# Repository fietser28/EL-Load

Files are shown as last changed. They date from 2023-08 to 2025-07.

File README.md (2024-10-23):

<!--
SPDX-FileCopyrightText: 2023 Jan Nieuwstad <jan.sources@nieuwstad.net>

SPDX-License-Identifier: CC-BY-SA-4.0
-->

# This is WORK IN PROGRESS.
The designs here are not finished or fully tested yet.

# Overview

The DCL8010 electronic load module features a DC Electronic Load with several modes and protections.
This project is the for the development boards for this project. There is a seperate git project for the [firmware](https://github.com/fietser28/EL-Load-FW).

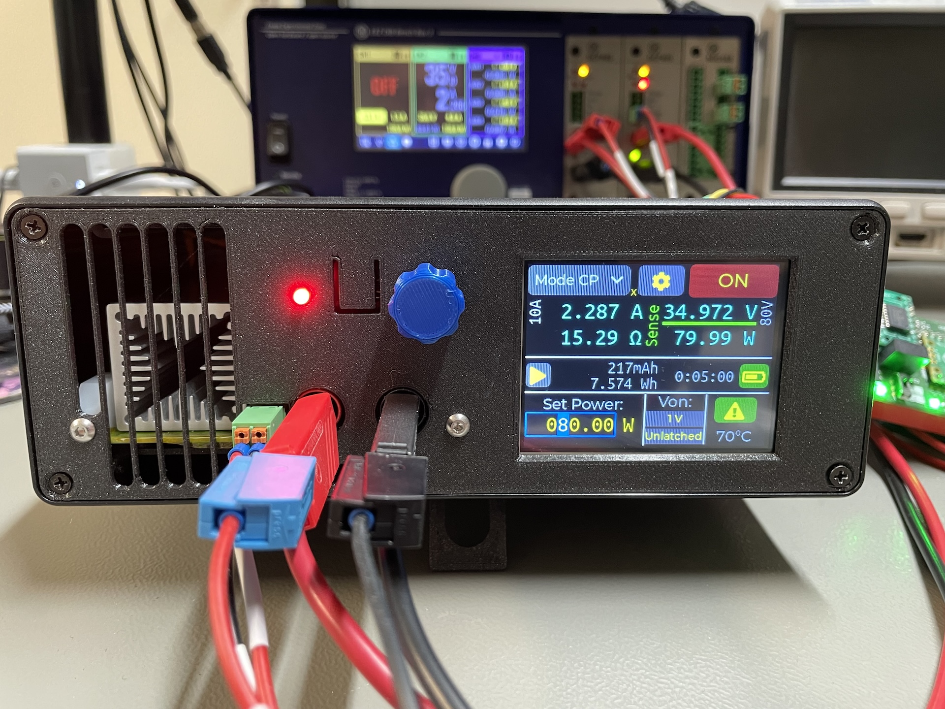
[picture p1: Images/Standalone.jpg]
Standalone unit


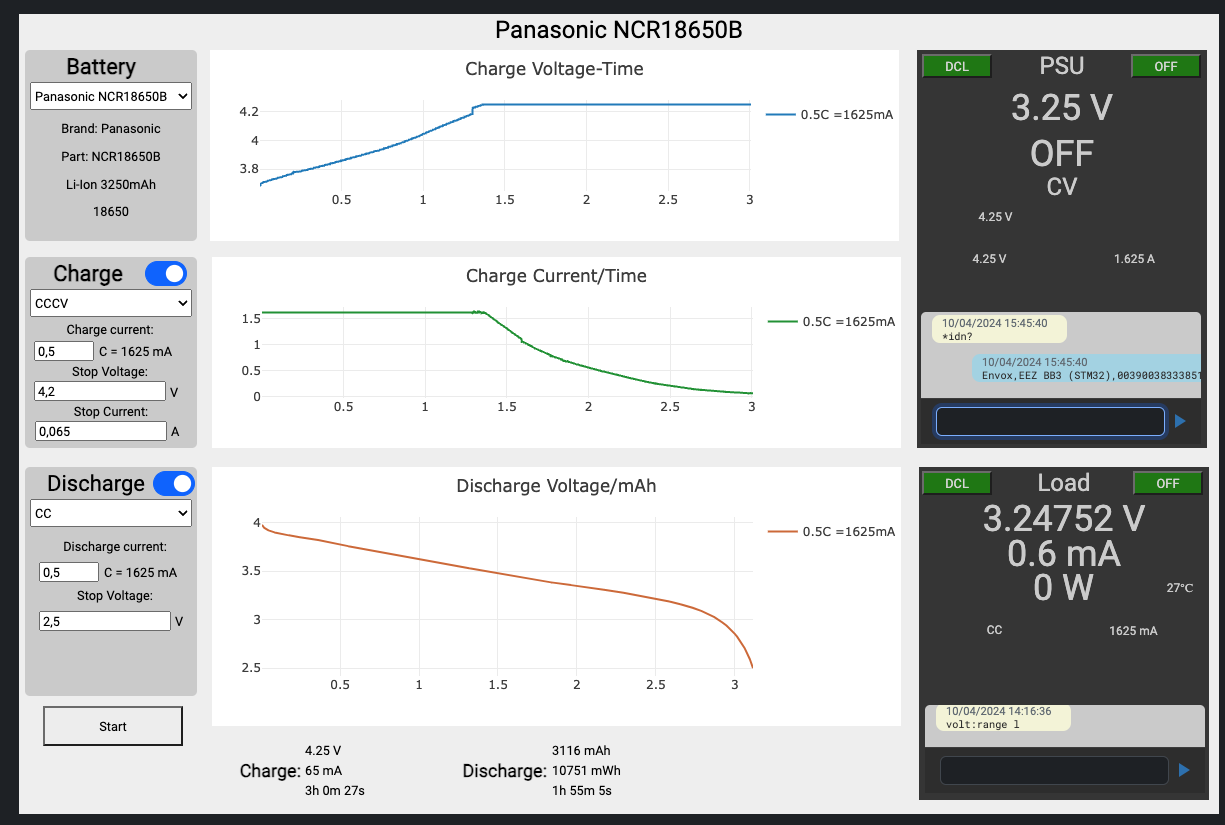
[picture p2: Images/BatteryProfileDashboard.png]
battery profile
Together with [studio] and a BB3 there will be some example dashboards in the near future. For example a  application:

## Specifications

* Modes: Constant Current (CC), Constant Voltage (CV), Constant Power (CP) and Constand Resistance (CR). CC and CV are implemented in hardware, CP and CR are software controlled and have a slower dynamic response.
* Limits:
  * Current: 1mA - 10A set and read
  * Voltage: 0.5V - 80V (set), 1mV-80V read
  * Power: 80W

* Protections:
In hardware:
  * User definable Over Voltage Protection (OVP), clamps load off within 1ms
  * User definable Over Current Protection (OCP), clamps load off within 1ms
With software support:
  * User definable Over Power Protection for a specific time in seconds (1-99)
  * User definable Over Temperature Protection for a specific time in seconds (1-99)

* Other hardware features:
  * Von: The minimum voltage needs to be present before the load is turned on. This can be set with or without latching. This is implemented in hardware and when on guarentees a gradual turn-on if a power source is 'hot plugged' or turned on. 
  * Temperature based fan control
  * Fan RPM readout
  * Heatsink temperature readout

## Design considerations

### Sizing
The Electronic Load was designed to complement a pair of BB3 DCP405 modules. Such a pair can deliver up to 80V (series configuration) or 10A (parallel configuration). The power is just maximized what is achievable with the small form factor of a BB3 module.

Minimum set voltage (an von cutoff) aim is as low as possible but at least 0.5V. A low Von cutoff is important to discharge for example AA battries (around 0.8V).

### Resolution and accurary
Aim is to have 0.1% full scale accurary after calibration. Calibration will be done in 100% in software.

This results in the follwing goals:
| Input/output | Range | Accuracy  | Resolution | Remarks 
| --- |  --- | --- | --- | ---
| Current monitor | 0-10A | 10mA | 1mA | 
| Current monitor | 0-1A | 1mA | 0.1mA | not evaluted/tested yet
| Voltage monitor | 0-80V | 80mV | 1mV | Accuracy probably: 10mV
| Voltage monitor | 0-10V | 1mV | 0.1mV | 
| Power measurements | 0-24h | 1s & 0.2% FS | 1s | Perform accurate incremental calculations and timing
| Current set | 5mA-10A | 10mA | 1mA |
| Current set | 5mA-1A  | 1mA | 0.2mA | 
| Voltage set | 0.5-80V | 80mV | 1mV |
| Voltage set | 0.5-9V  | 5mV | 1mV |
| Resistance set  | ? | ? | ? | 0.5% FS In software
| Power set | ? | 0.25W | ? | 0.5% FS in software
| Von set (80V range) | 0.25-50V | 0.2V  | 0.1V | Difficult to calibrate
| Von set (9V range) | 0.25-6V | 0.1V  | 0.1V | Difficult to calibrate
| OCP (10A range) | 0.1-10A | 100mA  | 10mA | Difficult to calibrate
| OCP set (1A range) | 0.25-6V | 10mA  | 1mA | Difficult to calibrate, not implemnted yet
| OVP (80V range) | 1-80V | 0.2V  | 0.1V | Difficult to calibrate
| OVP set (9V range) | 0.25-9V | 0.1V  | 0.1V | Difficult to calibrate, not tested yet

Using 16bit ADC's and DAC's this should be achievable with calibration done in software.

### Hardware / software partitioning
Everything requiring a response below 10ms is implemented directly in hardware. All other functionality is preferably done in software.
This results in the following decisions:
* Current and Voltage measurement and control loops are in analog circuitry
* Over voltage and over current protection measurement and shutdown are in hardware with a seperate clamp on the power MOSFET gates to shutdown as fast as possible. It is up to software to toggle pins to release the hwardware protection
* Von circuitry is implemented in hardware including the latch. The Von circuitry is important to avoid the MOSFET loops to go fully open (unregulated) when the supplied current and/or voltage is less then the set values. An unregulated situation would lead to large (= overshoot) spikes if the DUT suddenly starts providing more power (e.g. plug-in/turn on).
* To combine current, voltage and Von control a cross-over circuit is used where the smallest set current will get priority.

### Fail safely: 
An electronic load is often used to discharge batteries and due to the time this takes it is not realistic to assume the discharge is always attended by a person. If a failing component in the electronic load fails it might cause a short. A battery (or other power source without proection) being shorted is a serious fire hazard. Therefore the Electronic Load has a physical fuse and all possbile components that might faile are behind this fuse. This includes the input snubber network, transient and revserse polarity diode and of course the main MOSFETS of the electronic load. This protection is not perfect: It requires a >10A peak surge, but greatly reduces the risk.

## Limitations / Issues

Most limitations,TODO's and issues are now tracked on [github issues](https://github.com/fietser28/EL-Load/issues).

# PCBs

### EL-Load-Analog
Main PCB. Contains all the analog circuitry including MOSFETS. The DAC & ADC's are also on this board. Sizes of the PCB adhere to DIB standard (I hope).

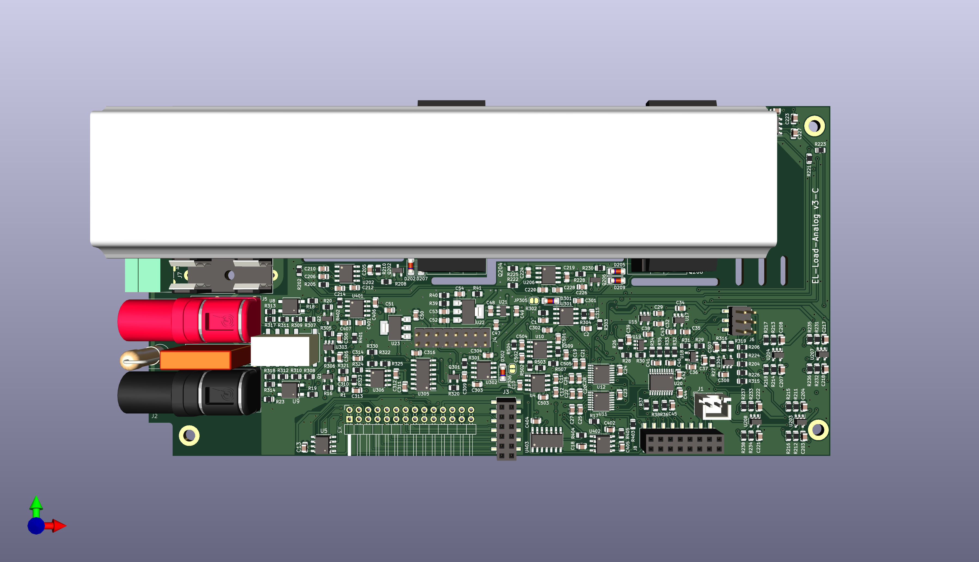
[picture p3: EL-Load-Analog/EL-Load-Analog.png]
EL-Load-Analog


### EL-Load-Power-MCU
PCB for stand alone deployment outside of BB3. This board contains an isolated power supply (input 5V) with fan controllers, MCU, GPIO and a bunch of connectors. 
It directly fits to the Analog PCB with an addidional IDC cable. There is also an IDC connector to the Front panel PCB.

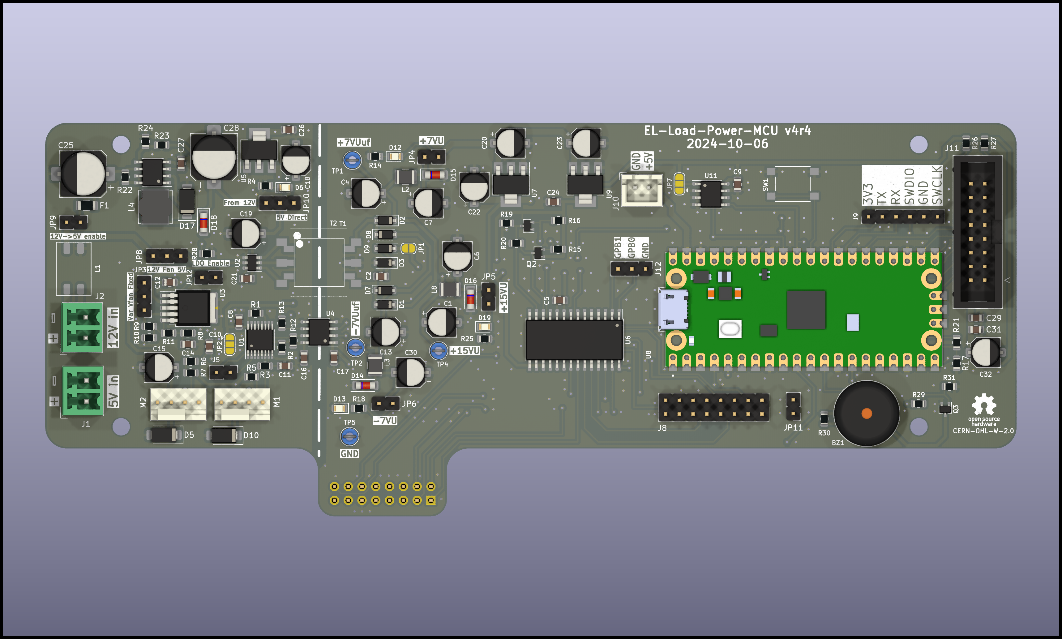
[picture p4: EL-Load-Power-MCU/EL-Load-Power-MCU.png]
EL-Load-Power-MCU


### EL-Load-Panel
Front panel PCB for standalone deployment. Connects to EL-Load-Power-MCU. Has a connector for common 2.4/2.8" TFT touchscreen PCBs, 1 encoder, 1 microswitch and one 1 LED.

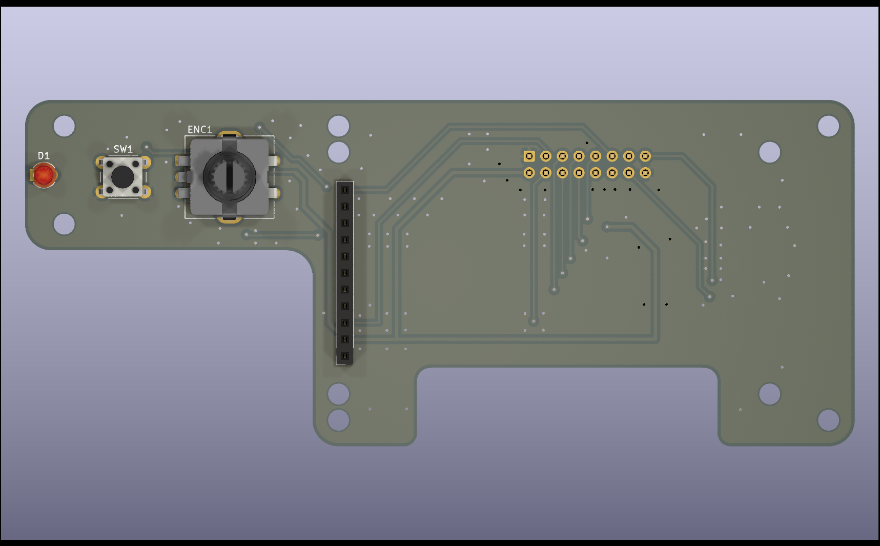
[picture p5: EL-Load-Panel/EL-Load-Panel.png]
EL-Load-Panel

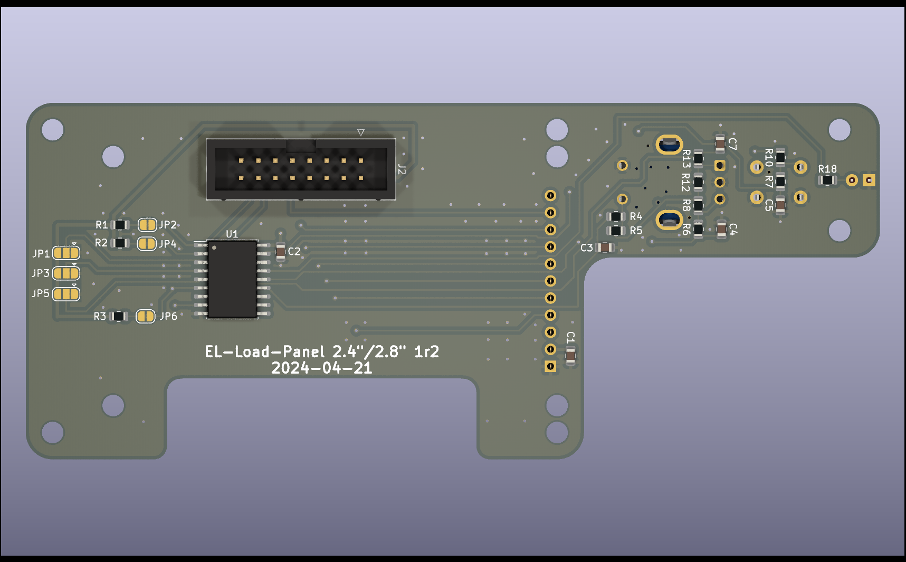
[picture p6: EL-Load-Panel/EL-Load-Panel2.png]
EL-Load-Panel backside


## Obsolete PCB's

### EL-Load-Simple-Power
Obsolete test board. Very simple 78*/79* based power supply to generate 2x+12V, 1x+5V, 1x-5V and optionally -12V. Was used for previous version of EL-Load-Analog.

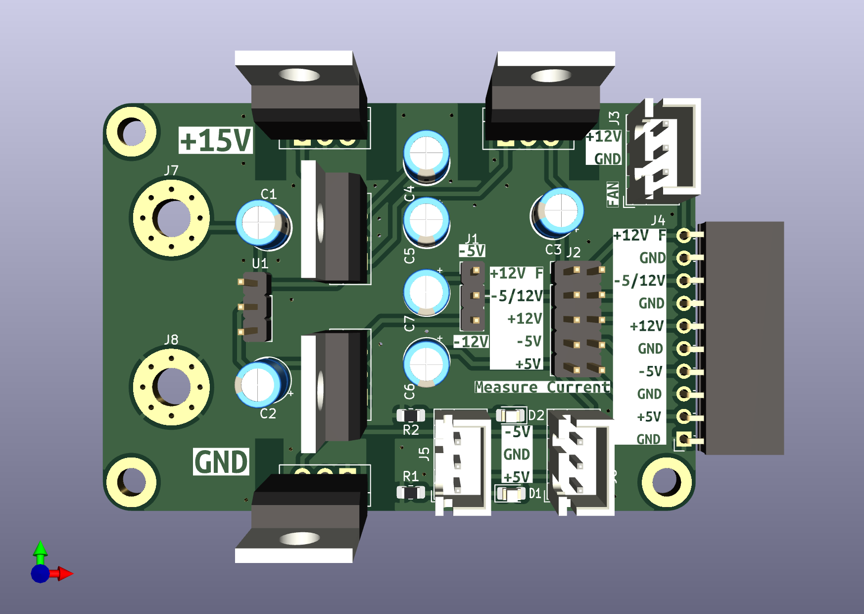
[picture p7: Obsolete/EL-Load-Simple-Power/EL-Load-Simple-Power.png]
EL-Load-Simple-Power


### EL-Load-Fan-Controller
Obsolete test board for the fan controller. For testing MAX31760 with 12V LDO regulation. Not used anymore. MAX31760 is now on Power-MCU-board.

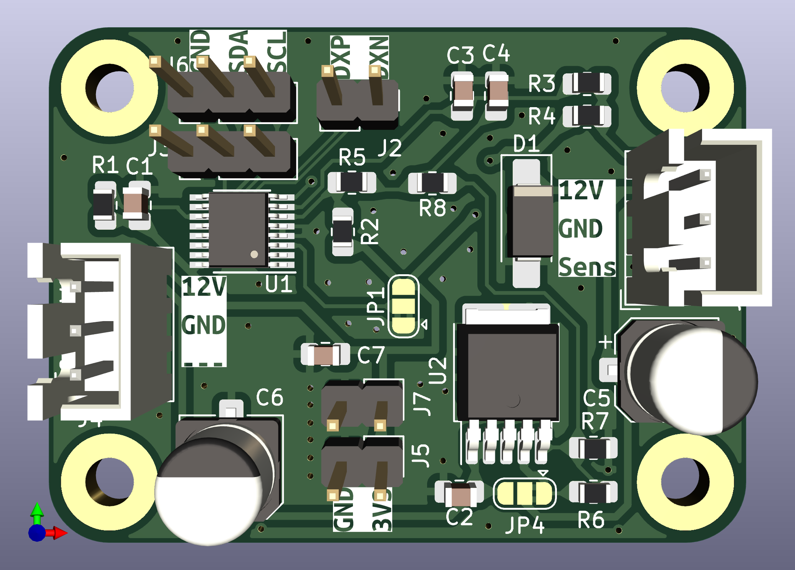
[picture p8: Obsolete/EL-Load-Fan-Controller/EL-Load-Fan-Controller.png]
EL-Load-Fan-Controller


### EL-Load-Digital
Obsolete test board for the MCU + ADC + DAC + GPIO + Touchscreen connection. DAC + ADC's are now on analog board. MCU and GPIO are now on new Power-MCU-board.

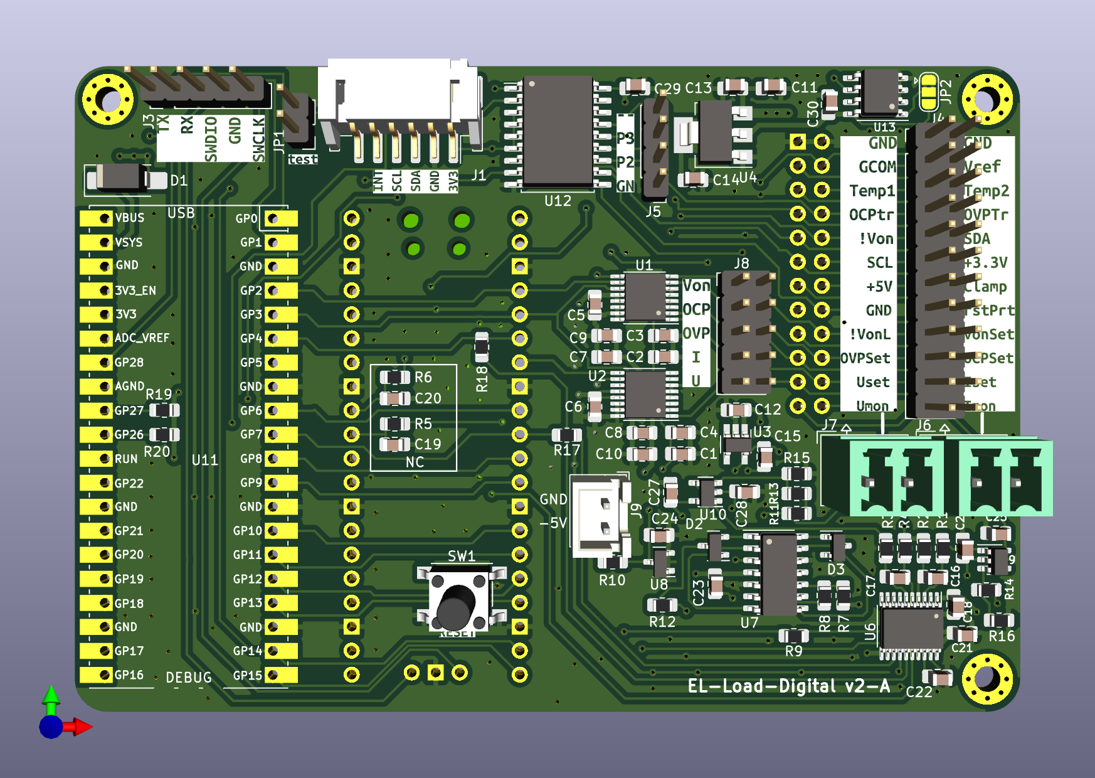
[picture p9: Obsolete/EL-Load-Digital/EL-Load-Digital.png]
EL-Load-Digital


# Ownership and License

This work is licensed under multiple licences:
 * All hardware designs are licensed under CERN-OHL-W-2.0
 * All original software source code is licensed under GPL-3.0-or-later.
 * All documentation is licensed under CC-BY-SA-4.0.
 * There are also parts imported from other sources. See the indivdual files for there specific licenses.

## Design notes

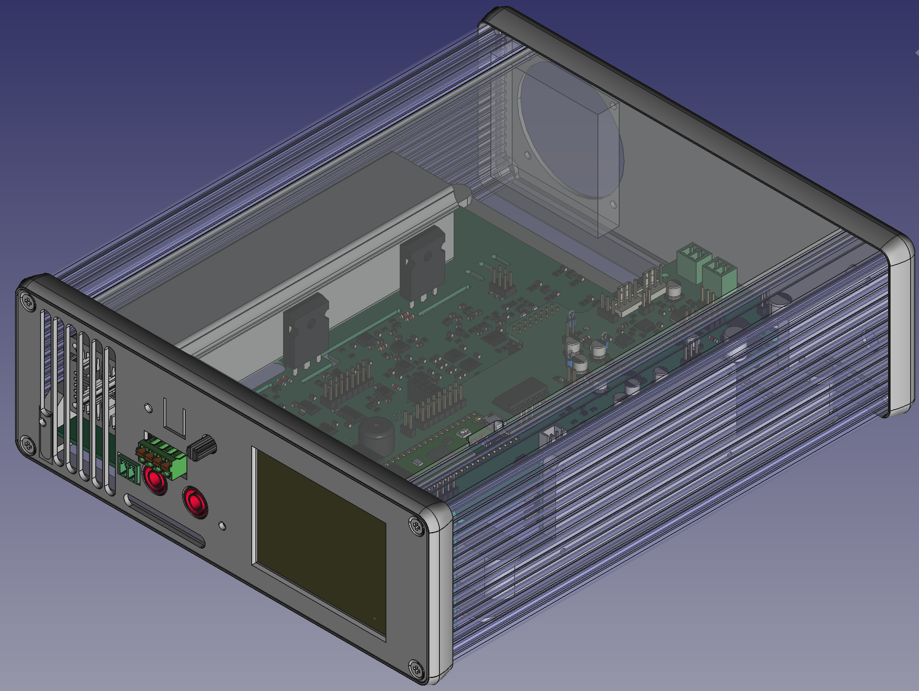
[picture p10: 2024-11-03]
Images/Case3Dv4.png

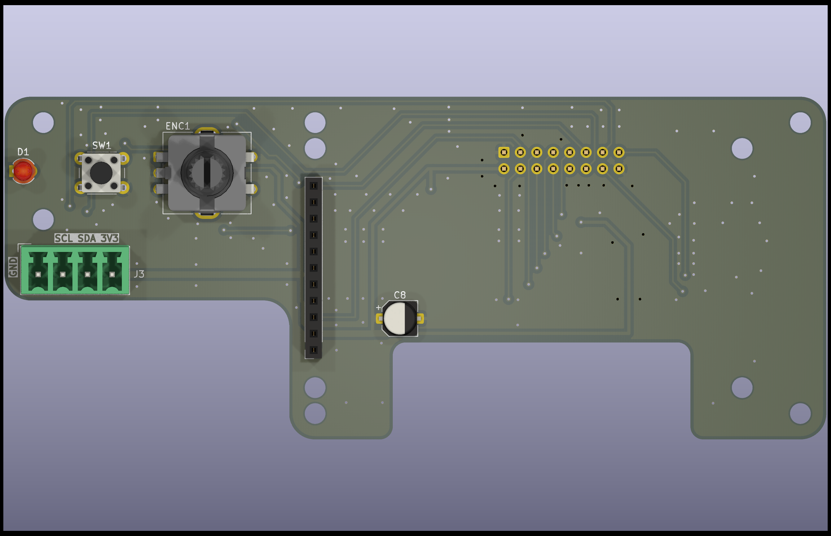
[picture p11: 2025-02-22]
EL-Load-Panel/EL-Load-Panel-v3.png

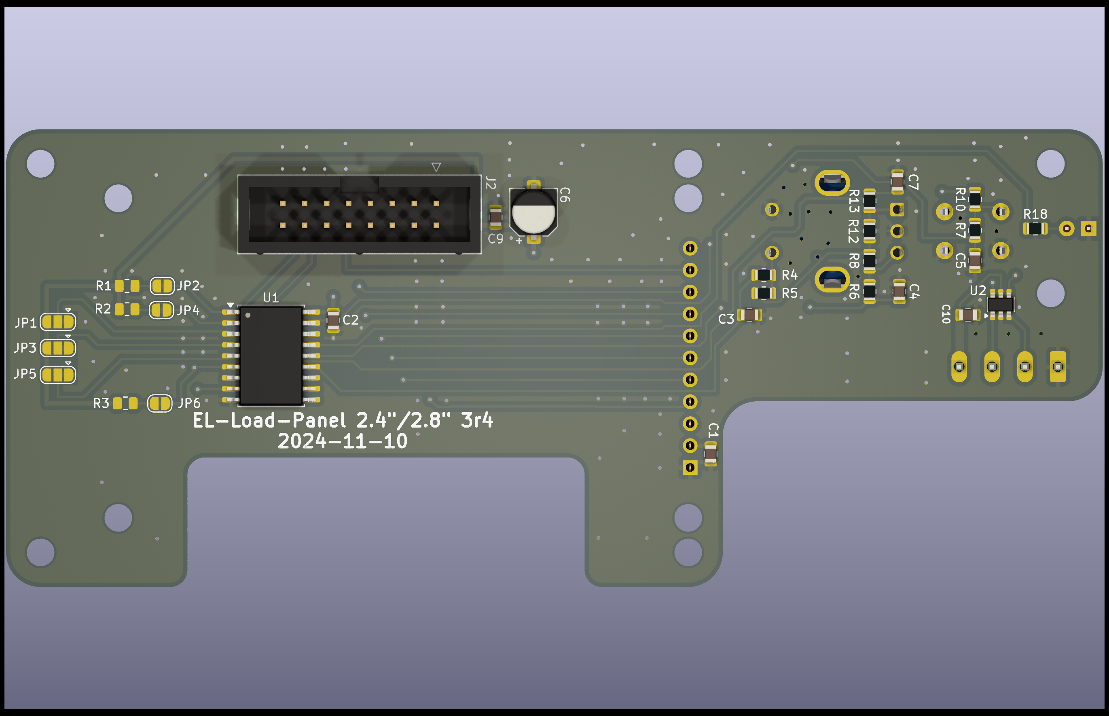
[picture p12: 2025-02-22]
EL-Load-Panel/EL-Load-Panel-v3-2.png

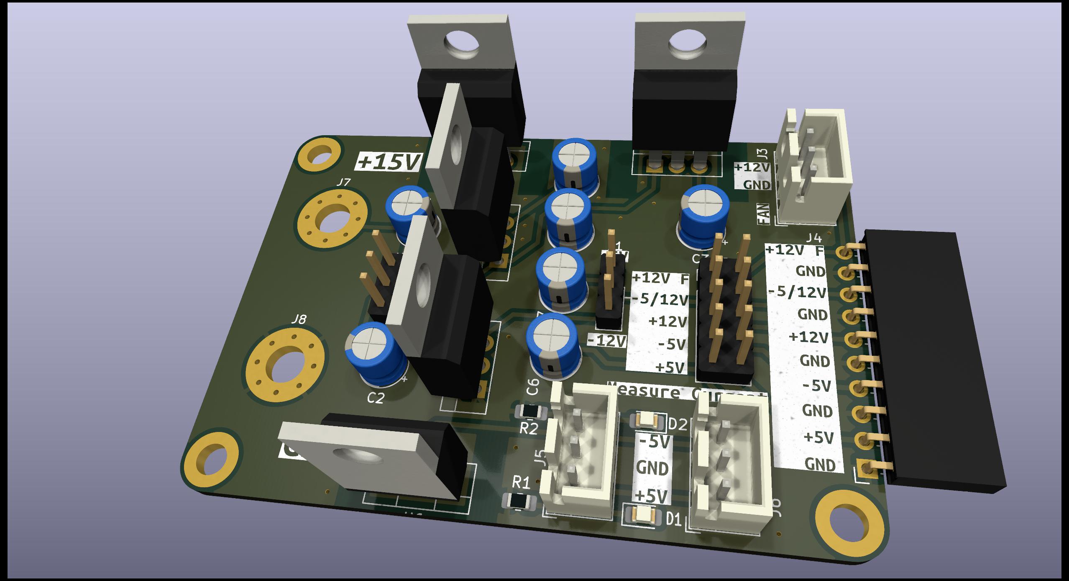
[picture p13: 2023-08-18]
EL-Load-Simple-Power/EL-Load-Simple-Power-3D.jpg

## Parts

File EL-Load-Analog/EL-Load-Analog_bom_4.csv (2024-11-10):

Description | Footprint | Part | Reference | Value | Quantity | Datasheet | Part Name | MPN | Sim.Device | Sim.Pins
Unpolarized capacitor, small symbol | C_0805_2012Metric | C_Small | C315 | 100p | 1 | ~ | C_100.0pF_0805_20%
Unpolarized capacitor, small symbol | C_0805_2012Metric | C_Small | C1 C213 C214 C227 C228 C310 | 1n | 6 | ~ | C_1.0nF_0805_20%
Unpolarized capacitor, small symbol | C_0805_2012Metric | C_Small | C5 C6 C18 C40 C41 C43 C48 C54 C405 | 10n | 9 | ~ | C_10.0nF_0805_20%
Unpolarized capacitor, small symbol | C_0805_2012Metric | C_Small | C2 | 33n | 1 | ~ | C_33.0nF_0805_20%
Unpolarized capacitor, small symbol | C_0805_2012Metric | C_Small | C4 C7 C21 C22 C23 C24 C25 C26 C36 C37 C38 C39 C201 C202 C203 C204 C205 C206 C207 C208 C215 C216 C217 C218 C219 C220 C221 C222 C301 C302 C303 C304 C305 C306 C307 C308 C309 C311 C312 C313 C314 C402 C404 C406 C407 C501 C502 C504 C505 | 100n | 49 | ~ | C_100.0nF_50V_0805_10%_X7R
Unpolarized capacitor | C_Rect_L18.0mm_W5.0mm_P15.00mm_FKS3_FKP3 | C | C3 | 100nF | 1 | ~ | C_100.0nF_15mm_THT_X2_10% | R46KI3100CKM1K
Unpolarized capacitor, small symbol | C_0805_2012Metric | C_Small | C45 | 220n | 1 | ~ | C_220.0nF_0805_20%
Unpolarized capacitor, small symbol | C_0805_2012Metric | C_Small | C401 | 680n | 1 | ~ | C_680nF_25V_X7R_10%_0805
Unpolarized capacitor, small symbol | C_0805_2012Metric | C_Small | C10 C12 C19 C20 C29 C32 C42 C44 C47 C503 | 1u | 10 | ~ | C_1.0uF_0805_20%
Unpolarized capacitor, small symbol | C_0805_2012Metric | C_Small | C34 C35 C316 | 2u2 | 3 | ~ | C_2.2uF_25V_X7R_10%_0805
Unpolarized capacitor, small symbol | C_0805_2012Metric | C_Small | C27 C28 C49 C50 C52 | 10u | 5 | ~ | C_10.0uF_25V_X5R_10%_0805
Unpolarized capacitor, small symbol | C_0805_2012Metric | C_Small | C11 C51 C53 | 22u | 3 | ~ | C_22u_16V_X5R_10%_0805
1500W unidirectional TRANSZORB® Transient Voltage Suppressor, DO-201AE | D_SMC | 1.5KExxA | D203 | 1.5KE100A (smd) | 1 | https://www.vishay.com/docs/88301/15ke.pdf | D_1.5KE100A_SMC
100V 0.15A standard switching diode, DO-35 | D_MiniMELF | 1N4148 | D2 D3 D9 D10 D11 D12 D13 D14 D15 D301 D302 | 1N4148 | 11 | https://assets.nexperia.com/documents/data-sheet/1N4148_1N4448.pdf | D_1N4148_miniMELF |  | D | 1=K 2=A
Bidirectional transient-voltage-suppression diode, filled shape | D_SOD-323 | D_TVS_Filled | D1 D4 D5 D6 | PESD3V3L1BAF | 4 | ~ | D_TVS_PESD3V_SOD323
Zener diode | D_MiniMELF | D_Zener | D7 D8 D201 D202 D204 D205 D206 D207 D208 D209 | TZMB16-GS08 | 10 | ~ | D_Z_16V_miniMELF
Fuse | Fuseholder_Cylinder-5x20mm_Schurter_0031_8201_Horizontal_Open | Fuse | F1 | Fuse | 1 | ~ | FH_5x20_THT
Heatsink | LAM3K | Heatsink | HS102 | Heatsink | 1 | ~ | MH_LAM/3/150
Generic connector, single row, 01x02, script generated | PhoenixContact_MC_1,5_2-G-3.81_1x02_P3.81mm_Horizontal | Conn_01x02_Socket | J7 | Conn_01x02_Socket | 1 | ~ | H_Plug_2P_3.81MM_PCB_HOR
Generic connector, double row, 02x08, odd/even pin numbering scheme (row 1 odd numbers, row 2 even numbers), script generated (kicad-library-utils/schlib/autogen/connector/) | PinHeader_2x08_P2.54mm_Vertical | Conn_02x08_Odd_Even | J4 | Conn_02x08_Odd_Even | 1 | ~ | H_Male_1x40_vertical_THT
Generic connector, double row, 02x08, odd/even pin numbering scheme (row 1 odd numbers, row 2 even numbers), script generated (kicad-library-utils/schlib/autogen/connector/) | PinSocket_2x08_P2.54mm_Vertical_SMD | Conn_02x08_Odd_Even | J8 | Conn_02x08_Odd_Even | 1 | ~ | H_Female_2x8_SMD
Generic connectable mounting pin connector, single row, 01x01, script generated (kicad-library-utils/schlib/autogen/connector/) | SWEB-8094-AU | Conn_01x01_MountingPin | J5 | SWEB8094AU-RT | 1 | ~ | H_Banana_Socket_24A_Red
Generic connectable mounting pin connector, single row, 01x01, script generated (kicad-library-utils/schlib/autogen/connector/) | SWEB-8094-AU | Conn_01x01_MountingPin | J2 | SWEB8094AU-SW | 1 | ~ | H_Banana_Socket_24A_Black
Generic connector, single row, 01x02, script generated (kicad-library-utils/schlib/autogen/connector/) | JST_XH_B2B-XH-A_1x02_P2.50mm_Vertical | Conn_01x02 | J1 | Temp Sensor PCB | 1 | ~ | H_JST_XH_PCB_2P_VERT
Generic connector, single row, 01x02, script generated (kicad-library-utils/schlib/autogen/connector/) | JST_XH_B2B-XH-A_1x02_P2.50mm_Vertical | Conn_01x02 | J9 | Temp Sensor heatsink | 1 | ~ | H_JST_XH_PCB_2P_VERT
General purpose signal relay, Kemet EE2 Series, DPDT (2 Form C), double coil latching, SMD, 60W/125VA, 220VDC/250VAC, 2A, 5V DC coil | Relay_DPDT_Kemet_EE2_NU_DoubleCoil | EE2-5TNU | K2 | EE2-5TNU | 1 | https://content.kemet.com/datasheets/KEM_R7002_EC2_EE2.pdf | ER_EE2-5TNU-L
0.115A Id, 60V Vds, N-Channel MOSFET, SOT-23 | SOT-23 | 2N7002 | Q1 Q2 Q201 Q202 Q205 Q206 Q301 | 2N7002 | 7 | https://www.onsemi.com/pub/Collateral/NDS7002A-D.PDF | Q_2N7002
100Vds, 12A Id, N-Channel MOSFET, SO-8 | SO-8_3.9x4.9mm_P1.27mm | AOSP66923 | Q7 | AOSP66923 | 1 | http://www.aosmd.com/pdfs/datasheet/AOSP66923.pdf | U_AOSP66923
N-MOSFET transistor, gate/drain/source | TO-247-3_Vertical | Q_NMOS_GDS | Q203 Q204 Q207 Q208 | IRFP250M | 4 | ~ | Q_IRFP250MPBF
0.2A Ic, 40V Vce, Small Signal NPN Transistor, SOT-23 | SOT-23 | MMBT3904 | Q4 | MMBT3904 | 1 | https://www.onsemi.com/pdf/datasheet/pzt3904-d.pdf | Q_MMBT3904
-0.2A Ic, -40V Vce, Small Signal PNP Transistor, TO-92 | SOT-23 | MMBT5401 | Q5 Q8 | MMBT5401 | 2 |  | Q_MMBT5401
0.6A Ic, 160V Vce, General Purpose NPN Transistor, SOT-23 | SOT-23 | MMBT5551 | Q3 Q6 | MMBT5551 | 2 |  | Q_MMBT5551
-6A Ic, -100V Vce, Power PNP Transistor, TO-220 | TO-220-3_Vertical | TIP42C | Q101 | TIP42C | 1 | https://www.centralsemi.com/get_document.php?cmp=1&mergetype=pd&mergepath=pd&pdf_id=TIP42.PDF
Resistor, small symbol | R_0805_2012Metric | R_Small | R11 R12 R24 R25 R45 R221 R222 | 0 | 7 | ~ | R_0.0Ω_0805_1%
Resistor | R_2512_6332Metric_Pad1.40x3.35mm_HandSolder | R | R219 R220 R239 R240 | 10m | 4 | ~ | R_R01_2512_1%_20ppmC
Resistor, small symbol | R_0805_2012Metric | R_Small | R36 R37 R38 | 47 | 3 | ~ | R_47.0Ω_0805_1%
Resistor, small symbol | R_0805_2012Metric | R_Small | R207 R208 R227 R228 | 100 | 4 | ~ | R_100.0Ω_0805_1%
Resistor, small symbol | R_0805_2012Metric | R_Small | R40 | 200 | 1 | ~ | R_200.0Ω_0805_1%
Resistor, small symbol | R_0805_2012Metric | R_Small | R504 | 220 | 1 | ~ | R_220.0Ω_0805_1%
Resistor, small symbol | R_0805_2012Metric | R_Small | R8 R21 | 330 | 2 | ~ | R_330.0Ω_0805_1%
Resistor, small symbol | R_0805_2012Metric | R_Small | R18 R19 | 470 | 2 | ~ | R_470.0Ω_0805_1%
Resistor, small symbol | R_0805_2012Metric | R_Small | R9 R10 | 750 | 2 | ~ | R_750.0Ω_0805_1%
Resistor, small symbol | R_0805_2012Metric | R_Small | R32 R33 R34 R35 R322 R401 R402 | 1k | 7 | ~ | R_1.0kΩ_0805_1%
Resistor, small symbol | R_0805_2012Metric | R_Small | R41 | 1k8 | 1 | ~ | R_1.8kΩ_0805_1%
Resistor, small symbol | R_0805_2012Metric | R_Small | R301 R302 R303 R304 R325 R404 R405 | 2k | 7 | ~ | R_2.0kΩ_0805_1%
Resistor, small symbol | R_0805_2012Metric | R_Small | R330 | 2k2 | 1 | ~ | R_2.2kΩ_0805_1%
Resistor, small symbol | R_0805_2012Metric | R_Small | R47 R48 | 4k7 | 2 | ~ | R_4.7kΩ_0805_1%
Resistor, small symbol | R_0805_2012Metric | R_Small | R320 | 7k5 | 1 | ~ | R_7.5kΩ_0805_1%
Resistor, small symbol | R_0805_2012Metric | R_Small | R17 R44 R46 R55 R56 R57 R201 R202 R403 R502 R507 R509 | 10k | 12 | ~ | R_10.0kΩ_0805_1%
Resistor, small symbol | R_0805_2012Metric | R_Small | R323 R503 | 15k | 2 | ~ | R_15.0kΩ_0805_1%
Resistor, small symbol | R_0805_2012Metric | R_Small | R39 R42 R58 R203 R205 R223 R225 | 22k | 7 | ~ | R_22.0kΩ_0805_1%
Resistor, small symbol | R_0805_2012Metric | R_Small | R22 R43 | 47k | 2 | ~ | R_47.0kΩ_0805_1%
Resistor, small symbol | R_0805_2012Metric | R_Small | R16 R20 R53 R54 R321 | 100k | 5 | ~ | R_100.0kΩ_0805_1%
Resistor, small symbol | R_0805_2012Metric | R_Small | R49 R51 R52 R209 R210 R229 R230 | 1M | 7 | ~ | R_1.0MΩ_0805_1%
Resistor, small symbol | R_0805_2012Metric | R_Small | R4 R5 R26 R29 R30 R31 R211 R212 R213 R214 R231 R232 R233 R234 R309 R310 R311 R312 R313 R314 | 100k 0.1% | 20 | ~ | R_100k_0805_0.1%
Resistor, small symbol | R_0805_2012Metric | R_Small | R27 R28 R305 R306 | 10k 0.1% | 4 | ~ | R_10k_0805_0.1%
Resistor, small symbol | R_0805_2012Metric | R_Small | R307 R308 | 1k 0.1% | 2 | ~ | R_1k_0805_0.1%
Resistor, small symbol | R_0805_2012Metric | R_Small | R215 R216 R217 R218 R235 R236 R237 R238 | 1k1 0.1% | 8 | ~ | R_1k1_0805_0.1%
Resistor | R_Axial_DIN0516_L15.5mm_D5.0mm_P5.08mm_Vertical | R | R2 | 1k5 (3W) | 1 | ~ | R_1.5kΩ_THT_15mm_5mm_3W_1% | FMP300FRF73-1K5
Resistor, small symbol | R_0805_2012Metric | R_Small | R204 R206 R224 R226 | 20k 0.1% | 4 | ~ | R_20k_0805_0.1%
Resistor, small symbol | R_0805_2012Metric | R_Small | R317 R318 | 39k 0.1% | 2 | ~ | R_39k_0805_0.1%
Resistor, small symbol | R_0805_2012Metric | R_Small | R3 R6 R315 | 5k 0.1% | 3 | ~ | R_5k_0805_0.1%
quad 2-input NOR gate | SO-14_3.9x8.65mm_P1.27mm | 74HCT02 | U305 U403 | 74HCT02 | 2 | http://www.ti.com/lit/gpn/sn74hct02 | U_74HCT02D
Single 2.7V to 6.0V Single Supply CMOS Op Amps, with Chip Select, SOIC-8 | SOIC-8_3.9x4.9mm_P1.27mm | MCP603-xSN | U401 | AD8038 | 1 | http://ww1.microchip.com/downloads/en/DeviceDoc/21314g.pdf | U_AD8038ARZ
24-bit dual-channel ADC with 1.2V internal reference | TSSOP-20_4.4x6.5mm_P0.65mm | ADS131M02 | U20 | ADS131M02 | 1 |  | U_ADS131M02
1A Low Dropout regulator, positive, adjustable output, SOT-223 | SOT-223-3_TabPin2 | AMS1117 | U22 | AMS1117 | 1 | http://www.advanced-monolithic.com/pdf/ds1117.pdf | U_AZ1117CH-ADJTRG1
16-bit quad-channel voltage output DAC with external reference | TSSOP-16_4.4x5mm_P0.65mm | DAC8555 | U11 U12 | DAC8555 | 2 | https://www.ti.com/lit/ds/symlink/dac8555.pdf | U_DAC8555IPW
Operational Amplifier, TO-99-8 | SOIC-8_3.9x4.9mm_P1.27mm | LM318H | U201 U202 U205 U206 | LM318D | 4 | http://www.ti.com/lit/ds/symlink/lm318-n.pdf | U_LM318D
Low-Power, Low-Offset Voltage, Dual Comparators, DIP-8/SOIC-8/TO-99-8 | SOIC-8_3.9x4.9mm_P1.27mm | LM393 | U2 U306 U402 | LM393 | 3 | http://www.ti.com/lit/ds/symlink/lm393.pdf | U_LM393
Dual, 1 MHz, 85µA, Rail-to-Rail input and output SOIC-8 | SOIC-8_3.9x4.9mm_P1.27mm | MCP6L02x-xSN_2 | U301 | LM833 | 1 | http://ww1.microchip.com/downloads/en/devicedoc/22140b.pdf | U_LM833DR
Dual, 1 MHz, 85µA, Rail-to-Rail input and output SOIC-8 | SOIC-8_3.9x4.9mm_P1.27mm | MCP6L02x-xSN_1 | U302 | LM833 | 1 | http://ww1.microchip.com/downloads/en/devicedoc/22140b.pdf | U_LM833DR
MICROPOWER 200mA Low Noise LDO negative regulator, fixed output -5V, TSOT-23-5 | TSOT-23-5 | LT1964-5 | U21 | LT1964-5 | 1 | https://www.analog.com/media/en/technical-documentation/data-sheets/1964fb.pdf | U_LT1964ES5-5
Single, 1 MHz, 85µA, Rail-to-Rail input and output, SOT-23-5 | SOT-23-5 | MCP6L01x-xOT | U18 U19 | MCP6V51 | 2 | http://ww1.microchip.com/downloads/en/devicedoc/22140b.pdf | U_MCP6V51T-E/OT
Low offset opamp, SOT-23-5 | SOT-23-5 | MCP6V51/LTC2050HV | U203 U204 U207 U208 | MCP6V51/LTC2050HV | 4 |  | U_LTC2050HVCS5
Low offset opamp, SOT-23-5 | SOT-23-5 | MCP6V51/LTC2050HV | U303 U304 | OPA189/MCP6V51/LTC2050HV | 2 |  | U_LTC2050HVCS5
2.5V 0.1% 10mA Low Noise Precision Voltage Reference, SO-8 | SOIC-8_3.9x4.9mm_P1.27mm | REF5025AD | U4 | REF5025AD | 1 | http://www.ti.com/lit/ds/symlink/ref5030.pdf | U_REF5025
Single SPDT Analog Switch, 5V/3.3V Single-Supply Operation, 12Ohm Ron, SOT-23-6 | SOT-23-6 | TS5A63157DBV | U1 | SN74LVC1G3157DBV | 1 | https://www.ti.com/lit/ds/symlink/ts5a63157.pdf | U_SN74LVC1G3157DBVR
Dual Low-Noise JFET-Input Operational Amplifiers, DIP-8/SOIC-8 | SOIC-8_3.9x4.9mm_P1.27mm | TL072 | U10 | TL072/OPA2376 | 1 | http://www.ti.com/lit/ds/symlink/tl071.pdf | U_TL072CDT
800mA Low-Dropout Linear Regulator, 5.0V fixed output, TO-220/TO-252/TO-263/SOT-223 | SOT-223-3_TabPin2 | TLV1117-50 | U23 | TLV1117-50 | 1 | http://www.ti.com/lit/ds/symlink/tlv1117.pdf | U_AZ1117CH-5.0TRG1
Ultra Low Noise, High PSRR LDO | SOT-23-5 | TPS72325 | U17 | TPS72325 | 1 |  | U_TPS72325DB
Ultra Low Noise, High PSRR LDO | SOT-23-5 | TPS7A2030 | U15 | TPS7A2030 | 1 |  | U_TPS7A2030PDBVR
Form A, Solid State Relay (Photo MOSFET) 60V, 0.2A, 10Ohm, SO-4 | SO-4_4.4x4.3mm_P2.54mm | ASSR-1218 | U8 U9 | VO1400AEFTR | 2 | https://docs.broadcom.com/docs/AV02-0173EN | U_VO1400AEFTR
Component Groups: | 82
Component Count: | 301
Fitted Components: | 301
Number of PCBs: | 1
Total components: | 301
Schematic Version: | 4
Schematic Date: | 2024-11-10
PCB Variant: | default
BoM Date: | 2024-11-10
Schematic Source: | EL-Load-Analog.kicad_sch
KiCad Version: | Eeschema 7.0.9

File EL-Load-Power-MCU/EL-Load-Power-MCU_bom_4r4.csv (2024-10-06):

Description | Footprint | Part | Reference | Value | Quantity | Datasheet | Part_Name | MPN | Consumable | Sim.Enable
Buzzer, polarized | Buzzer_12x9.5RM7.6 | Buzzer | BZ1 | Buzzer | 1 | ~ | EM_Buzzer_single_5V_THT
Unpolarized capacitor, small symbol | C_0805_2012Metric | C_Small | C27 | 200p | 1 | ~ | C_200.0pF_0805_20%
Unpolarized capacitor, small symbol | C_0805_2012Metric | C_Small | C5 C8 C9 C10 C11 C16 C17 C21 C31 | 100n | 9 | ~ | C_100.0nF_50V_0805_10%_X7R
Unpolarized capacitor, small symbol | C_0805_2012Metric | C_Small | C2 C14 C29 | 1u | 3 | ~ | C_1.0uF_0805_20%
Unpolarized capacitor, small symbol | C_0805_2012Metric | C_Small | C12 | 2.2u | 1 | ~ | C_2.2uF_25V_X7R_10%_0805
Polarized capacitor, small symbol | CP_Elec_5x5.8 | C_Polarized_Small | C1 C4 C6 C7 C13 C15 C18 C19 C20 C22 C23 C30 C32 | 10u | 13 | ~ | C_10uF_50V_Elec_5 | EEE-FK1V470P
Unpolarized capacitor, small symbol | C_0805_2012Metric | C_Small | C24 C26 | 10u | 2 | ~ | C_10.0uF_6V3_X7R_10%_0805
Polarized capacitor | CP_Elec_8x10.5 | C_Polarized | C25 C28 | 100u | 2 | ~ | C_100uF_50V_Elec_8
Zener diode, small symbol, filled shape | D_MiniMELF | D_Zener_Small_Filled | D14 D15 | 16V | 2 | ~ | D_Z_16V_miniMELF
Zener diode, small symbol, filled shape | D_MiniMELF | D_Zener_Small_Filled | D16 | 20V | 1 | ~ | D_Z_20V_miniMELF
5.6V, 500mW, 2%, Zener diode, MiniMELF | D_MiniMELF | BZV55B5V6 | D18 | BZV55B5V6 | 1 | https://assets.nexperia.com/documents/data-sheet/BZV55_SER.pdf | D_Z_5V6_miniMELF
Light emitting diode | LED_0805_2012Metric | LED | D6 D12 D13 D19 | LED | 4 | ~ | D_LED_Groen_0805
30V 0.5A Schottky Power Rectifier Diode, SOD-123 | D_SOD-123 | MBR0530 | D1 D2 D3 D7 D8 D9 | MBR0530 | 6 | http://www.mccsemi.com/up_pdf/MBR0520~MBR0580(SOD123).pdf | D_MBR0530T | MBR0530T1G
Schottky diode, small symbol | D_SMA | D_Schottky_Small | D5 D10 D17 | SS14 | 3 | ~ | D_SS14
Resettable fuse, polymeric positive temperature coefficient | Fuse_1206_3216Metric | Polyfuse | F1 | 1A | 1 | ~ | F_SMD_PTC_1A_1206
Generic connector, single row, 01x02, script generated (kicad-library-utils/schlib/autogen/connector/) | PhoenixContact_MCV_1,5_2-G-3.81_1x02_P3.81mm_Vertical | Conn_01x02 | J1 J2 | Conn_01x02 | 2 | ~ | H_Plug_2P_3.81MM_PCB_VERT
Generic connector, double row, 02x08, odd/even pin numbering scheme (row 1 odd numbers, row 2 even numbers), script generated (kicad-library-utils/schlib/autogen/connector/) | IDC-Header_2x08_P2.54mm_Vertical | Conn_02x08_Odd_Even | J11 | IDC-Header 2x08 P2.54mm | 1 | ~ | H_IDC_2.54mm_Socket_THT_2x8pins
Generic connector, single row, 01x02, script generated (kicad-library-utils/schlib/autogen/connector/) | PinHeader_1x02_P2.54mm_Vertical | Conn_01x02 | J5 J7 J8 J9 J12 JP3 JP4 JP5 JP6 JP8 JP9 JP10 JP11 JP12 | PN sensor | 14 | ~ | H_Male_1x40_vertical_THT |  | 1
Generic connector, single row, 01x02, script generated (kicad-library-utils/schlib/autogen/connector/) | JST_XH_B2B-XH-A_1x02_P2.50mm_Vertical | Conn_01x02 | J10 | Power for serial interface | 1 | ~ | H_JST_XH_PCB_2P_VERT
Inductor with ferrite core, small symbol | L_1210_3225Metric | L_Ferrite_Small | L2 L3 L8 | 10u | 3 | https://product.tdk.com/system/files/dam/doc/product/inductor/inductor/smd/catalog/inductor_commercial_decoupling_nlcv32-ef_en.pdf | L_10uH_480mohm_450mA_ | NLCV32T-100K-EF
Inductor | L_Bourns_SRN6045TA | L | L4 | 100u / 300mA | 1 | ~ | L_100uH_CD54
Coupled inductor with ferrite core | L_Bourns_SRF1260 | L_Ferrite_Coupled_1423 | L1 | SRF0905-202Y | 1 | ~ | LC_2000uH_0.6A_0905 | SRF0905-202Y
Fan, tacho output, PWM input, 4-pin connector | FanPinHeader_1x04_P2.54mm_Vertical | Fan_4pin | M1 M2 | Fan_4pin | 2 | http://www.formfactors.org/developer%5Cspecs%5Crev1_2_public.pdf | H_Molex_47053-1000_THT_PC_Fan
Open Hardware logo, small | OSHW-Logo_5.7x6mm_SilkScreen | Logo_Open_Hardware_Small | PCB1 | Logo_Open_Hardware_Small | 1 | ~ | PCB_EL-Load-Power-MCU |  |  | 0
50V Vds, 0.22A Id, N-Channel MOSFET, SOT-23 | SOT-323_SC-70 | BSS138 | Q1 Q2 Q3 | BSS138W | 3 | https://www.diodes.com/assets/Datasheets/BSS138W.pdf | Q_BSS138W
Resistor, small symbol | R_0805_2012Metric | R_Small | R22 | 0.3 | 1 | ~ | R_0.33Ω_0805_1%
Resistor, small symbol | R_0805_2012Metric | R_Small | R3 R6 | 10 | 2 | ~ | R_10.0Ω_0805_1%
Resistor, small symbol | R_0805_2012Metric | R_Small | R5 R7 R8 R29 R30 | 1k | 5 | ~ | R_1.0kΩ_0805_1%
Resistor, small symbol | R_0805_2012Metric | R_Small | R12 R13 R15 R16 R19 R20 R26 R27 | 3k | 8 | ~ | R_3.0kΩ_0805_1%
Resistor, small symbol | R_0805_2012Metric | R_Small | R10 R11 R24 | 3k3 | 3 | ~ | R_3.3kΩ_0805_1%
Resistor, small symbol | R_0805_2012Metric | R_Small | R1 R2 | 4k7 | 2 | ~ | R_4.7kΩ_0805_1%
Resistor, small symbol | R_0805_2012Metric | R_Small | R4 R14 R18 R21 R23 R28 | 10k | 6 | ~ | R_10.0kΩ_0805_1%
Resistor, small symbol | R_0805_2012Metric | R_Small | R17 R25 R31 | 20k | 3 | ~ | R_20.0kΩ_0805_1%
Resistor, small symbol | R_0805_2012Metric | R_Small | R9 | 39k | 1 | ~ | R_39.0kΩ_0805_1%
Push button switch, generic, two pins | SW_Push_1P1T_NO_6x6mm_H9.5mm | SW_Push | SW1 | Pico Reset | 1 | ~ | SW_SPST_NO_SMD_6x6x5mm
Transformer, dual primary, dual secondary | L_Wuerth_750316031 | Transformer_2P_2S | T2 | Wuerth_750316031 | 1 | ~ | T_1:1:1.75:1.75_185uH_SMD
I2C Serial EEPROM, 64Kb, DIP-8/SOIC-8/TSSOP-8/DFN-8 | SOIC-8_3.9x4.9mm_P1.27mm | 24LC64 | U11 | 24C64 | 1 | http://ww1.microchip.com/downloads/en/DeviceDoc/21189f.pdf | U_24C64
1A Low Dropout regulator, positive, 3.3V fixed output, SOT-223 | SOT-223-3_TabPin2 | AMS1117-3.3 | U5 U9 | AMS1117-3.3 | 2 | http://www.advanced-monolithic.com/pdf/ds1117.pdf | U_AMS1117-3.3
1A 20V Fixed LDO Linear Regulator, 5.0V, SOT-89/SOT-223/TO-220/TO-252/TO-263 | SOT-223-3_TabPin2 | AZ1117-5.0 | U7 | AZ1117-5.0 | 1 | https://www.diodes.com/assets/Datasheets/AZ1117.pdf | U_AZ1117CH-5.0TRG1
1.5A low dropout linear regulator, adjustable output, TO-252 | TO-252-5_TabPin6 | BD00FC0W | U3 | BD00FC0WFP-E2 | 1 |  | U_BD00FC0WFP
Precision Fan-Speed Controller with Nonvolatile Lookup Table, I2C, SOIC-16 | QSOP-16_3.9x4.9mm_P0.635mm | MAX31760 | U1 | MAX31760 | 1 |  | U_MAX31760AEE+T
1.5A, step-up/down/inverting switching regulator, 3-40V Vin, 100kHz, SO-8 | SOIC-8_3.9x4.9mm_P1.27mm | MC34063AD | U10 | MC34063AD | 1 | http://www.onsemi.com/pub_link/Collateral/MC34063A-D.PDF | U_MC34063AD
16-bit I/O expander, I2C, interrupts, w pull-ups, SOIC-28 | SOIC-28W_7.5x17.9mm_P1.27mm | MCP23017_SO | U6 | MCP23017_SO | 1 | http://ww1.microchip.com/downloads/en/DeviceDoc/20001952C.pdf | U_MCP23017-E/SO
Raspberry Pi Pico Embedded Dev Module | Raspberry Pi SC0915 | MODULE_SC0915 | SC0915 | U8 | SC0915 | 1 |  | EM_Raspberry_Pi_Pico | SC0915
Low Noise, 1A, Transformer Drivers for Isolated Power Supplies, 420 kHz, SOT-23-6 | SOT-23-6 | SN6505BDBV | U2 | SN6505BDBV | 1 | http://www.ti.com/lit/ds/symlink/sn6505b.pdf | U_SN6505BDBVT_SOT-23-6
 | SOIC-8_3.9x4.9mm_P1.27mm | Si8602AD | U4 | Si8602AB | 1 |  | U_SI8602AB-B-IS
Component Groups: | 46
Component Count: | 123
Fitted Components: | 123
Number of PCBs: | 1
Total components: | 123
Schematic Version: | 4r4
Schematic Date: | 2024-09-14
PCB Variant: | default
BoM Date: | 2024-09-14
Schematic Source: | EL-Load-Power-MCU.kicad_sch
KiCad Version: | Eeschema 7.0.9

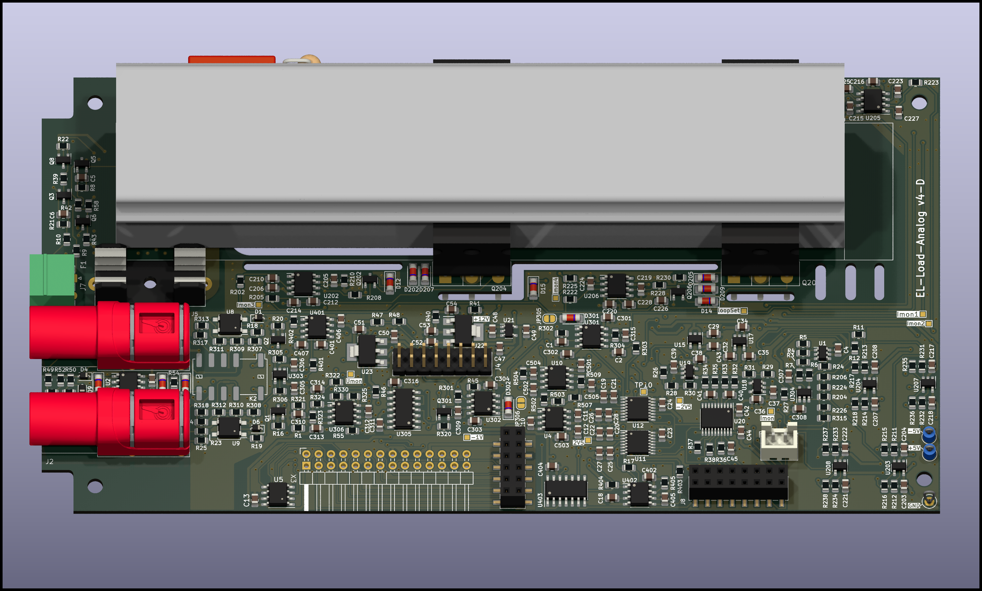
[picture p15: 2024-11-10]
EL-Load-Analog/EL-Load-Analog-PCB-v4D-parts.png

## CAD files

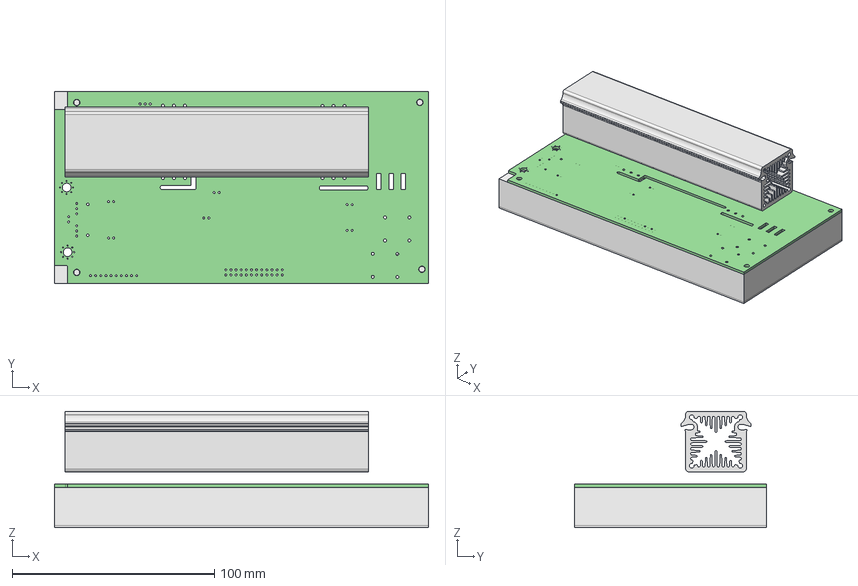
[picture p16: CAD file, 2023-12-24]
3Dmodels/PCB-stands/PCB-EL-Load-Analog.FCStd
185.0 x 95.0 x 57.6 mm
EL-Load-V2 PCB

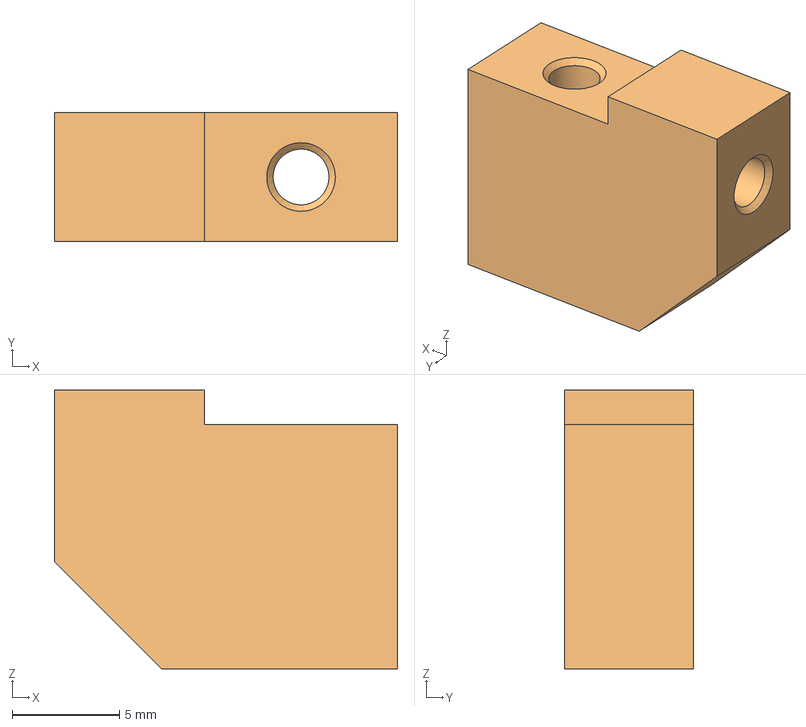
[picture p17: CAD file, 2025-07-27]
3Dmodels/PMB-1.FCStd
16.0 x 6.00 x 13.0 mm
PMB-1

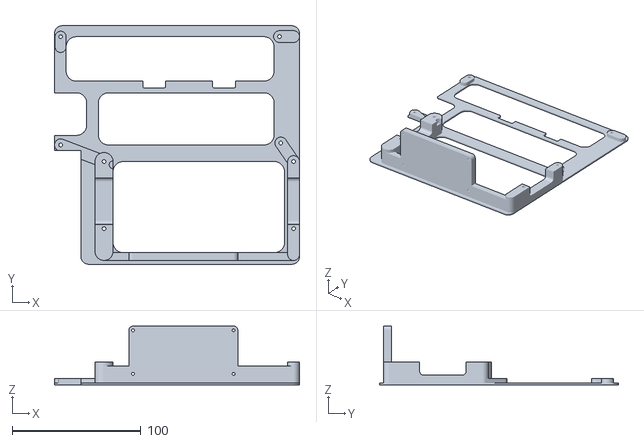
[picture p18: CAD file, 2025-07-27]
3Dmodels/Standalone/EL-Load-CaseV4-PCBFrame1.stl
190.0 x 185.0 x 45.6

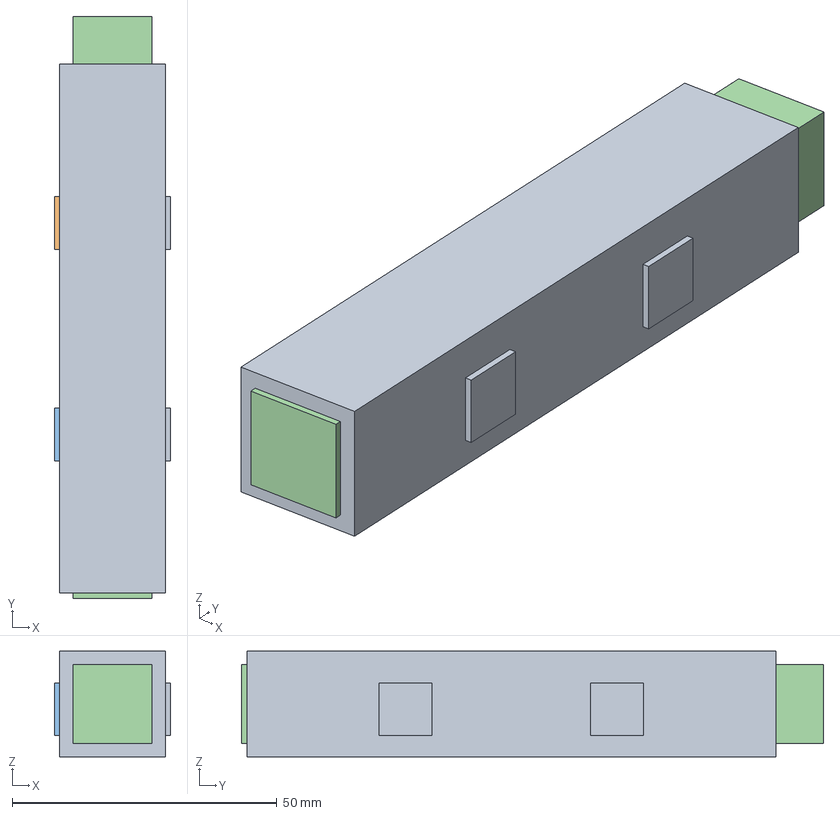
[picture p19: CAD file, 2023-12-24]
3Dmodels/ThermalSimulation/ThermalSim1.FCStd
22.0 x 110.0 x 20.0 mm

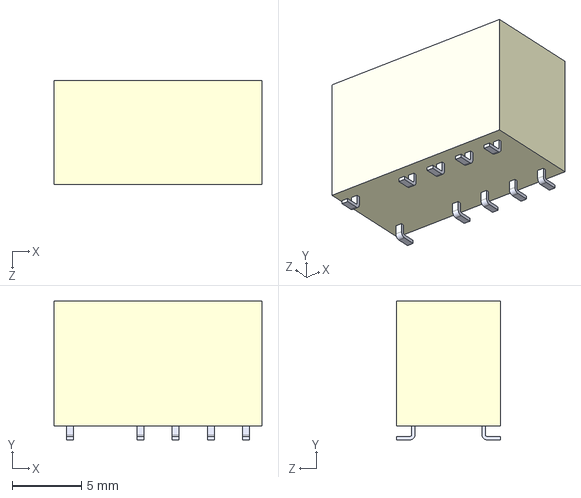
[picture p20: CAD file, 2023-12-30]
EL-Load-Analog/3Dmodels/EE2-3TNUH-L/EE2-3TNUH-L.step
15.0 x 10.0 x 7.50 mm

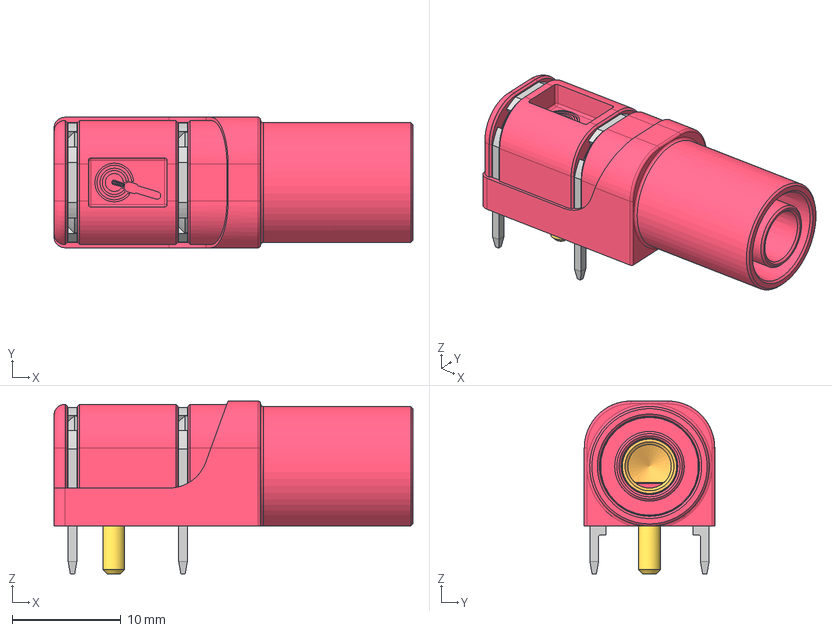
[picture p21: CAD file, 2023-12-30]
EL-Load-Analog/3Dmodels/schutzinger-sweb-8094-isolated-banana-jack-pcb-1kv-24a-1/SWEB 8094 AU RT.step
33.0 x 12.0 x 15.9 mm

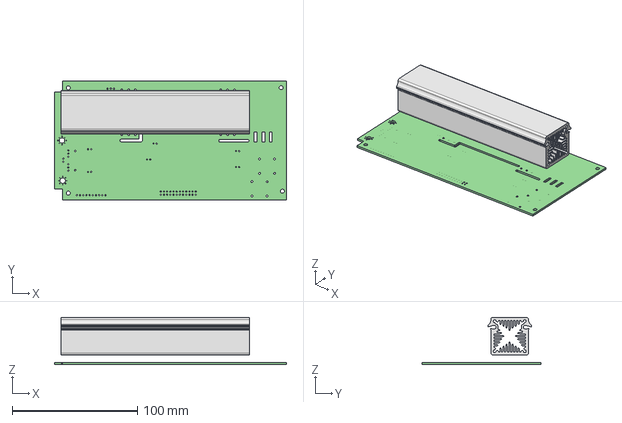
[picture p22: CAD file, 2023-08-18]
EL-Load-Analog/EL-Load-V2.step
185.0 x 95.0 x 37.6 mm
EL-Load-V2 PCB

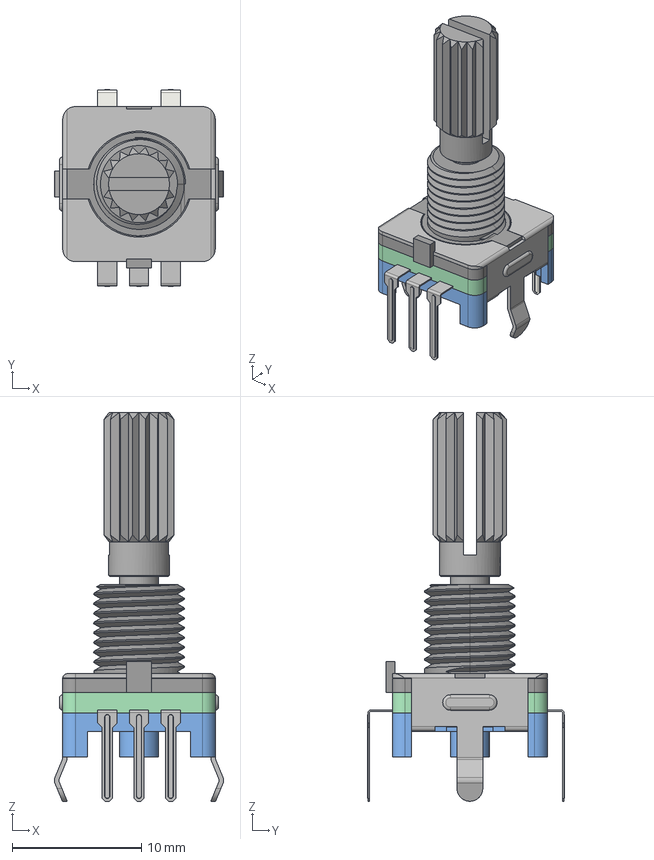
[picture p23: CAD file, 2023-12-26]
EL-Load-Panel/models/ec11-rotary-encoder-with-switch-1/EC11_Rotary_Encoder_Switched.step
13.1 x 15.3 x 30.1 mm

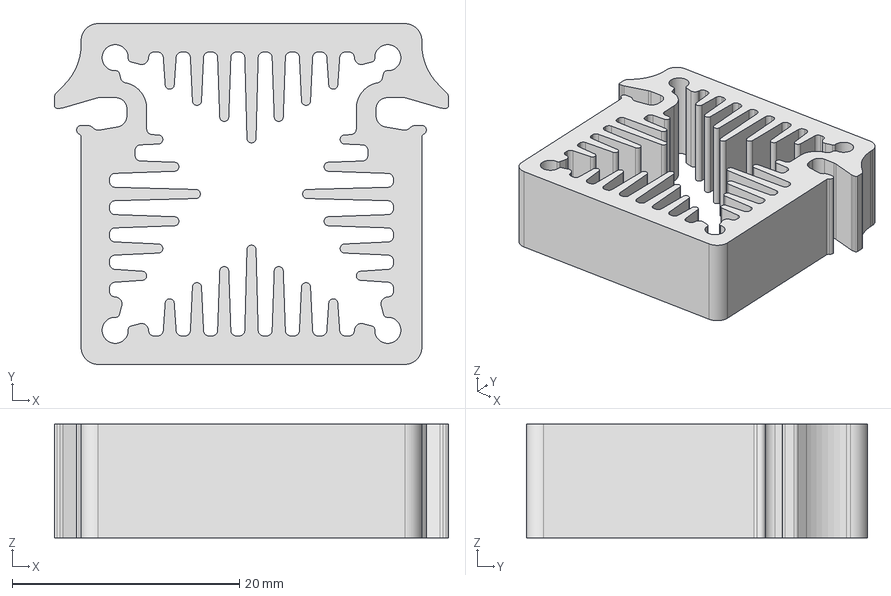
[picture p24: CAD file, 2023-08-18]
3Dmodels/lam_3_k.stp
34.7 x 30.0 x 10.0 mm

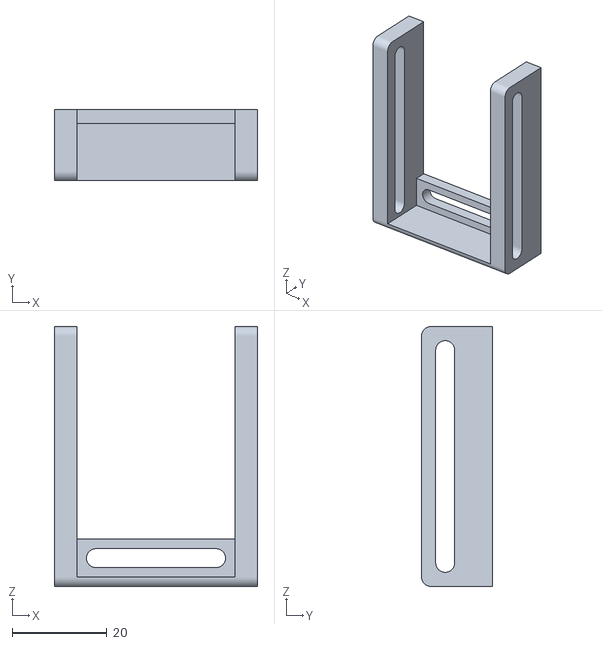
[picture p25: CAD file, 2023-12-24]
3Dmodels/PCB-stands/PCB-EL-Load-Analog-Fan30Stand2-FanSupport.stl
43.0 x 15.0 x 55.0

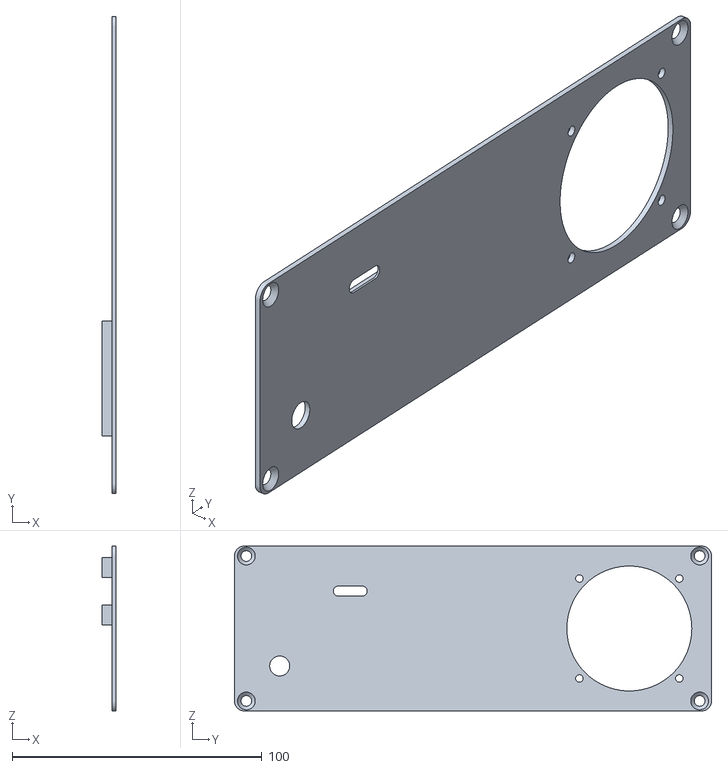
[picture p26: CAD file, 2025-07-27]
3Dmodels/Standalone/EL-Load-CaseV4-EndPanel.stl
5.63 x 191.0 x 66.0

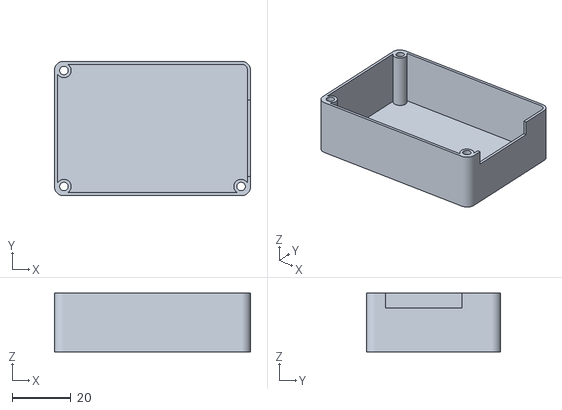
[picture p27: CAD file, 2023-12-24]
3Dmodels/PCB-stands/PCB-EL-Load-Simple-Power-BodyThickness.stl
66.6 x 45.7 x 20.0

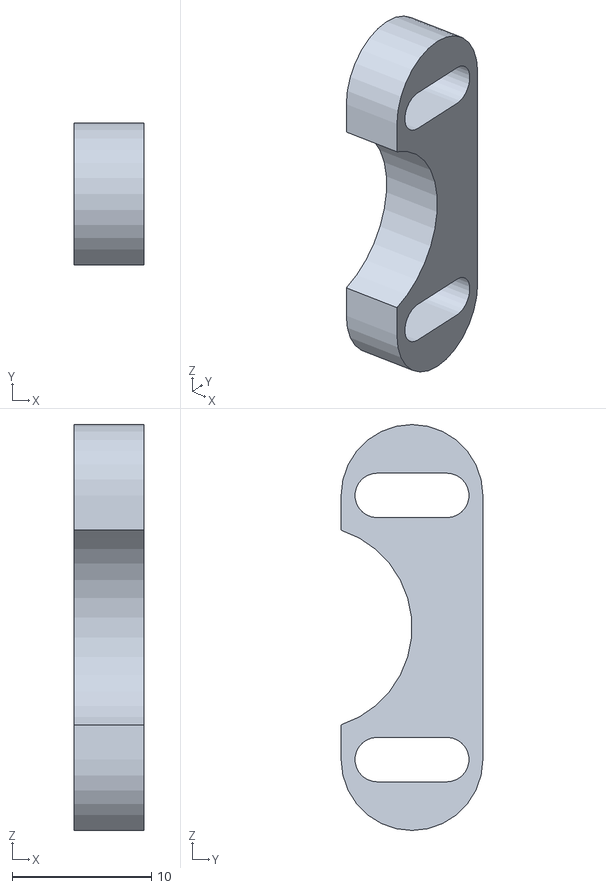
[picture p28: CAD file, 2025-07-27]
3Dmodels/Standalone/EL-Load-CaseV4-USB clip.stl
5.00 x 10.2 x 29.2

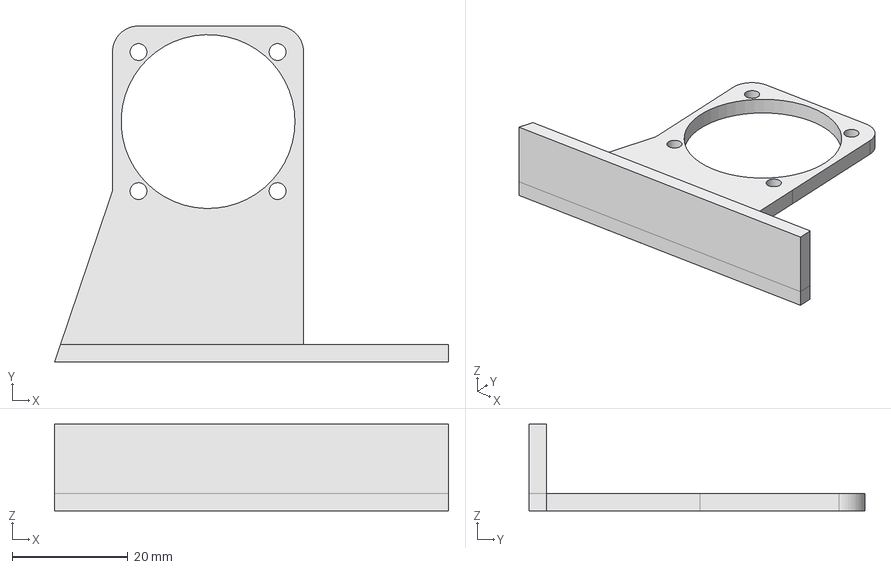
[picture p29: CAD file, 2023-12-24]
3Dmodels/PCB-stands/PCB-EL-Load-Analog-Fan30Stand1.FCStd
68.0 x 58.0 x 15.0 mm

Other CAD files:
EL-Load-Analog/3Dmodels/schutzinger-sweb-8094-isolated-banana-jack-pcb-1kv-24a-1/SWEB 8094 AU GN.step
EL-Load-Analog/3Dmodels/schutzinger-sweb-8094-isolated-banana-jack-pcb-1kv-24a-1/SWEB 8094 AU SW.step
3Dmodels/Standalone/Encoder knob.FCStd
EL-Load-Analog/3Dmodels/schutzinger-sweb-8094-isolated-banana-jack-pcb-1kv-24a-1/SWEB 8094 AU OR.step
3Dmodels/PCB-stands/PCB-ADS1115-module.FCStd
3Dmodels/PCB-stands/PCB-ADS1115-module.stl
3Dmodels/PCB-stands/PCB-EL-Load-Analog-Fan30Stand2-FanBracket.stl
3Dmodels/PCB-stands/PCB-EL-Load-Analog-Fan30Stand2.FCStd
3Dmodels/PCB-stands/PCB-EL-Load-Analog-NTCclip.FCStd
3Dmodels/PCB-stands/PCB-EL-Load-Analog-NTCclip.stl
3Dmodels/PCB-stands/PCB-EL-Load-Analog-PartPad001.stl
3Dmodels/PCB-stands/PCB-EL-Load-Digital-Body.stl
3Dmodels/PCB-stands/PCB-EL-Load-Digital.FCStd
3Dmodels/PCB-stands/PCB-EL-Load-Simple-Power.FCStd
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

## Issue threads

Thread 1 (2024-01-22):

Optimise MOSFET placement on heat sink and/or power distribution between MOSFETS.

fietser28, 2024-01-22:
We need to find a good placement of the 4 MOSFETS on the LAM 3 150 heat sink. The MOSFETs are fixed on the PCB and it would require a special setup to move them around or a lot of different PCB’s to test different configurations.

A form of thermal analysis simulation to find an optimal/good placement seems more feasible. The analysis is not very trivial because the fan cases a forced airflow thru the heatsink and the air will heat up while flowing thru the heatsink.

On my current test PCB the MOSFETS are evenly placed along the heatsink and all MOSFETS dissipate the same amount of power (this is forced by the circuit). This situation results in the MOSFETS further away from the fan being around 15-20 degrees Celsius higher. The maximum temperature of the individual MOSFETs places the limit on the maximum power rating of the device. In my test I can now dissipate 90W total in a 19 degrees room temperature. The heatsink close to the MOSFET with highest temperature is just below 90 degrees Celsius.

The MOSFETS are IRF250 in TO-247 package with thermal grease and a kapton foil isolation. They are pressed against the heatsink with DIY clamps at the place of the screw hole of the package. Because of the experimentation I don’t want to drill a lot of holes in the heatsink.

Thermal images show a gradual increase in heatsink temperature when moving away from the fan. The increase is comparable to the temperature difference between the MOSFETS. Therefore I think it is worth investigating if placing all the MOSFETS closer to the fan results in a possible lower maximum MOSFET temperature at the same overall power dissipation.

A good/optimal placement maximises the total power the mosfets can dissipate without individually overheating.
For this I think there are 2 degreees of freedom we should focus on:
1.  placement of the 2 MOSFETS with the greatest distance from the fan. The other mosfets should be placed close to the fan.
2. Create a Fixed difference (in %) between currents (which is directly proportional to the power) of the MOSFETS close and far away of the fan. If simulation shows this is beneficial it is straight forward to create this fixed difference in the circuit.

I think we should first optimise on 1 and second on 2.

jbb-nz, 2024-02-17:
I expect that a big factor in the temperature difference is due to the air inside the heatsink warming up, so I’m not sure how much difference item 1 (fiddling with the ‘downwind’ pair of MOSFETs’ position) will make.

I do think that item 2 could be a win.

fietser28, 2024-03-03:
I also have a few other factor to play with:

3. Thermal conductivity from MOSFETs to heatsink. Use grease, karnton, other type of pads.
4. Fan. I have several fans. 12V fans seem more powerful. Will also test with this.

For more structural testing I have an studio dashboard that increases the power, waits until the temperature measurement on the heat sink stabilises and records this before taking the next step.

only the physical placement is hard to change , to others are probably doable.

fietser28, 2024-03-10:
I've tested item 2: change the current ratio between MOSFETS. This doesn't change the overall heatsink temperature but it does change the individual MOSFETS temperature (which is the limiting factor).

It turns out with the current 55mm distance between the MOSFETS a 1:2 ratio results in almost leveling the temperature between the MOSFET cases. And resulting in a lower max individual MOSFET temperature around 15C at the same power level.

For 90W this means 30W for a MOSFET near the fan and 15W in the middle.
I did not expect the ratio to be so big. Definitely something to keep in there. I implemented this using simple resistor dividers at the current setting.

fietser28, 2024-03-10:
item 4: I've tested with a more powerful 12V fan: This definitely results in more cooling. Except for the cost of small powerful fans this is the way to go.

jbb-nz, 2024-03-11:
Wow, a 30 W : 15 W ratio on the current sharing is really surprising. I wonder if the ambient temperature makes a big impact here? You previously mentioned 19 degrees C; where would the temperatures end up at an ambient of 35 degrees C (for a box jammed into a corner)?

If you are implementing circuitry to manage how the current reference is send to each opamp + MOSFET, maybe you could also implement a ‘low current’ range which only sends it to the two 15 W channels? I’ve found it very useful in the past to have a ‘low’ and ‘high’ range on an electronic load.

fietser28, 2024-03-11:
I was also surprised about the ratio. I was expecting more like 20%, but it makes sense.

I expect with the ambient temperature is linear with the heatsink temperature: at a constant ambient temperature I stepped the power up and waited for the temp to stabilize: the temperature rose linear with the power.

regarding the low ranges: What is your use case / preferred range?
I have a low range implemented for testing now: it only changes the measurement from 10A full scale to 1A full scale. This increases the accuracy, hopefully from 10mV accuracy and 1mA resolution to 1mA accuracy and. 0.1 mA resolution . Setting current stays the same: 1mA.
Voltage goes from 80V full scale to around 10V full scale.

jbb-nz, 2024-03-12:
Oops, I forgot about existing low range setting. 0.1 mA readout resolution is good. 1 mA setting resolution is probably just fine.

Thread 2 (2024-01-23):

Fix errors on EL-Load-Power-MCU 2r2

fietser28, 2024-01-23:
There are some mistakes on 2r2:

- [x] diodes on negative rails are reversed (D7 & D8)
- [x]  Enable pin (pin 5)  on sn6505 is low instead of high
- [x] remove C3 and D4. Short jumper JP1. Configuration with 2 diodes is enough.
- [x] remove zener D16 or change to higher value (18-20V)
- [ ] ~~Remove T1 or T2 footprint in final version depending on choice~~ no in #24
- [x] Fix T1 component label (footprint is ok)
- [x] Add cutout for MCP23008 on panel PCB.
- [x] J7 pin 14 = GND, should be 3.3VD (power supply for ADC and DAC's on analog board)
- [x] Fix Q1 an Q2 footprints. SOT23-3 instead of SOT23?

Improvements:

- [x]  in test PCBs: Add led to +15VU. This wil work as a small dummy load when analog board is not connected.

Closed 2024-03-21.

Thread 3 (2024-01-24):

Fix Errors on EL-Load-Panel PCB 1r1

fietser28, 2024-01-24:
Errors found on r1r1:

- [x]  TFT Display connector is rotated 180 degrees.
- [x] TFT Display connector is about 1mm misaligned with TFT display connector.
- [x]  Move MCP23008 up to keep it clear from MCU-Power PCB in case (or make cutout on MCU-Power PCB see #2 )
- [x]  Correct encoder footprint

Closed 2024-01-26.

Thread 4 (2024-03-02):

Fix errors on EL-Load-Analog v3-C Schema & PCB

fietser28, 2024-03-02:
- [x]  C401 = 1u  (was 680n)
- [x]  C52 10uF cap should have higher voltage rating (25/50V)
- [x] C316 = 1uF ipv 2.2uF. Change in design?
- [x] R330 label is at wrong/unclear place (to close to R322)
- [x] LT1964 PCB is correct for fixed 5V regulator. (adjustable requires additional 1200+390 ohm resistors)
- [x] Fix +12V regulator setup (values below result in 11,5 V which is fine):
- [x]  remove R39
- [x] R40 = 200
- [x] R41 = 1k8
- [x]  GCOM op differential amplifiers shunt resistors instead of GND: R213, R211, R233, R231: GND change to GCOM.
- [x]  R6 should be connected to GCOM instead of GND. This relates to previous item.
- [x] R18 en R19 = 470 ohm instead of 100k.
- [x]  U10B -1V reference circuit doesn't work. Fix.
- [x]  ~~Connect -5V to R320 (instead of -1V) and replace R320 with 47k. After this: tune the Von response time.~~
- [x]  ~~R201,~~ R221, ~~R202,~~ R222 can be removed.
- [x] ~~R203, R205, R223, R225 = 10k. This improves the set current stability when temperature rises.~~

Closed 2025-01-01.

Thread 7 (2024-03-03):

Make Power section dual voltage input

fietser28, 2024-03-03:
Change power section to have a 5V input for the isolated power rails and separate 12V input for the fan connections and the fan controller (non isolated).

~~For ease of testing also add an optional 12V to 5V buck converter to allow for a single 12V power supply for testing.~~

Closed 2024-03-20.

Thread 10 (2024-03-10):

12V to 5V convertor

fietser28, 2024-03-10:
Separated from #7:
For ease of testing also add an optional 12V to 5V buck converter to allow for a single 12V power supply for testing.

Add this to the isolated power section of the Power-MCU board. Should be optional using jumpers.

Closed 2024-03-20.

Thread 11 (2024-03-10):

Test with powerful fan

fietser28, 2024-03-10:
Test with powerfull fan: [MR3010E with 12V with PWM](1570-MR3010E12B1+6-RSR-ND)  ([datasheet](https://www.mechatronics.com/pdf/MR3010.pdf)).

Disadvantage: expensive and only available from Digikey. It really has to make a difference.

fietser28, 2024-05-03:
No noticable difference.

Closed 2024-05-03.

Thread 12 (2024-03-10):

Add testpoints

fietser28, 2024-03-10:
Add testpoints to PCB for easier testing.

- [x]  Several GND pins close to other testpins (to avoid loops)
- [x] +12V
- [x] +5V
- [x] -5V
- [x] V Ref
- [x] -2.5V
- [x] +3.0V
- [x] LoopISet
- [x]  Imon
- [x] Umon
- [x]  Imon for each loop

Closed 2024-03-24.

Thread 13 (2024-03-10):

Von circuitry might oscillate with specific loads

fietser28, 2024-03-10:
Von circuitry causes some oscillation when the voltage slowly decreases to the set level. This is noticeable in a typical battery discharge test, but this scenario can be circumvented easily by the user with the current firmware.

As this ia a very valid and common scenario we should implement something for it in hardware or software to notify user or avoid it.

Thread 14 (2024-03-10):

Add nice reverse polarity protection and detection.

fietser28, 2024-03-10:
Current reverse polarity implementation is a very crude diode+fuse: Implement a proper reverse polarity circuit preferabbly with a detection to software (nice to have).

fietser28, 2024-04-21:
See https://github.com/fietser28/EL-Load/tree/main/Obsolete/EL-Load-Reverse-Polarity for a prototype

Closed 2024-11-13.

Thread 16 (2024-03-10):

Von scaling

fietser28, 2024-03-10:
Von doesn't have to be possible for the full voltage ranges, 50% of the range is enough. This might increase the accuracy of Von.

This can be implemented using voltage dividers. This is already in place on v3 of PCB.

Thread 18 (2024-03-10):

Remove ADC clamp circuits

fietser28, 2024-03-10:
Probably not needed, replace with simple TVS diodes. Design in conjunction with #6

Closed 2024-03-24.

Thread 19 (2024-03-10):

Evaluate low current range

fietser28, 2024-03-10:
Evaluate the v3 hardware implementation. Is it useful, e.g. does it give extra measurement accuracy or not.

fietser28, 2024-03-15:
Working. Measurements are fine. Setting is also possible with increments below 1mA.
Practical lower limit for regulation is around 5mA.

Closed 2024-03-15.

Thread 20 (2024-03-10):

Evaluate low voltage range

fietser28, 2024-03-10:
Evaluate the v3 hardware implementation. Is it useful, e.g. does it give extra measurement accuracy or not.

fietser28, 2024-03-13:
Done. Workable range is 0-10V. Updated in README.md

Calibration is also working in firmware.

Closed 2024-03-13.

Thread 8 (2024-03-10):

CC loop tuning

fietser28, 2024-03-10:
During changes to reduce temperature dependencies some instability was introduced to the CC loop for low voltages (2-7V) and and multiple amps (2-4A). The measured oscillation is around 65kHz (using 10kohm feedback resistors for R225,R223, R205, R203)

Spice simulation agrees with this.

New values:

- [ ] ~~gate resistors R207, R208, R227, R228: 10ohm (was 100)~~ did not help
- [x] feedback restores R203, R205, R223, R225: 22k (was 100k in V3C)
- [x] compensation caps C213, C214, C227, C228: 1n (was 470p)

fietser28, 2024-03-13:
Tested with above values on PCB. Looks ok for now. Still need to correct this in design and BOM.

Closed 2024-03-21.

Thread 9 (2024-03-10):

Change clamping circuit

fietser28, 2024-03-10:
#8 will put to much stress on the mosfet driving opamps with the current clamp circuit.

Change the clamp method by clamping LoopIset to zero instead of the MOSFET gates.
Use a 2N7002 + resistor (1k?) + diode (1N4148) to clamp LoopIset to zero or slightly below zero.

Remove the lamp MOSFETS and the long lines to it.

fietser28, 2024-03-24:
#8 numbers changed. This is not needed for this reason anymore.
Maybe still a good idea to add this. Needs further HW testing.

fietser28, 2024-11-10:
Designed. Waiting for test.

Closed 2024-11-13.

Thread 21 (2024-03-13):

range switching doesn't always work

fietser28, 2024-03-13:
When a range switch happens this not always results in the right calibration values being used for displayed value.
Noticed on voltages.
This also happens when leaving calibration mode (during setDefaults).

going back and forth solves the problem.

fietser28, 2024-03-13:
Also is wrong during startup... switching back and forth fixes it. Looks like it is only wrong on voltage range.

fietser28, 2024-03-15:
Fixed with fietser28/EL-Load-FW@587e0462c25fcbd57fed5ebb97679b09d0ad073b

Closed 2024-03-15.

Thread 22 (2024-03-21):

MCP23017 GPA7 is output only according to datasheet

fietser28, 2024-03-21:
The revision D (2022) of the MCP23017 states the GPA7 (and GPB7) pins are output only. Currently we use GPA7 for Von input and this is working fine but can’t be relied upon.

Solution: Change the hw pin for von to a different pin of bank A. Swap it with an output pin.

fietser28, 2024-03-21:
Fixed in v3 MCU PCB

Closed 2024-03-21.

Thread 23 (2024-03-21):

Swap Von and VonLatch in firmware for v3 MCU PCB

fietser28, 2024-03-21:
See #22

fietser28, 2024-11-03:
Done

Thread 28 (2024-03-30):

Analog V4 testing

fietser28, 2024-03-30:
The Analog V4 schematic and PCB have some changes that need testing after fabrication:

- [x] Test reverse polarity protection circuit (with remote voltage sensing voltage connection)  (#14)
- [x] Test -1V reference
- [x] Test dynamic behaviour of Von
- [x] Test new clamping circuit (#9)

fietser28, 2025-01-03:
Reverse polarity is sensitive to adding/removing positive voltages (unplugging, turning DUT on/off). Happens both with load on and off. The Von switching the reverse polarity mosfett off might also cause this.
Possible solutions:

- add hysteresis to reverse polarity comparator.
- more relaxed lower voltage
- compare negative imput to GND or, -0.5V or -1V instead of positive input.
- is to add a small delay (50ms?) before actually triggering beep/reverse polarity in software.

Closed 2025-01-06.

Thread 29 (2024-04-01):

Standalone PCB with DIB connector.

fietser28, 2024-04-01:
Create a PCB with:
- RP2040 CPU / use raspberry pi pico module
- Connector to panel PCB with display, touch, and encoders. Using existing connector setup.
- 12V -> 5V module to feed BB3 module with both 12V and 5V.
- Case fan controller and drivers.

This PCB can be derived from the MCU-Power PCB.

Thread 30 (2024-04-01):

BB3 compatible MCU board

fietser28, 2024-04-01:
Rework the Power-MCU PCB to be a piggy board:

- Flip the board to fit on top of the BB3 board and connectors.
- Keep/Include Pico
- Keep MCP23017 section with level shifting
- Keep/include isolated power section (simplify?!)
- Keep heatsink fan controller
- Keep panel connector for display/touch/keys
- Keep Debug interface SWD+UART

- Add: DIB opto isolators
- Add: allow to switch between panel and DIB isolators (jumpers?)

- Remove case fan controller
- Remove 12V - 5V

Optionally/TBD: Add leds and extend piggy board to panel. Banana connectors and or sense relay might be in the way.

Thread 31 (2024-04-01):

Add programmable slew rate circuitry

fietser28, 2024-04-01:
Long term which. Main problem is to find space for the additional hardware on the main PCB.

3 available DAC channels can be used to set the levels/slew rates

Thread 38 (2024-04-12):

Implement self test and *TST?

fietser28, 2024-04-12:
Implement self test function and add it to startup and *TST? command.

Due to hardware limitations a full functional test is not possible without additional circuitry but a few sanity check can be implemented:

- [ ] ADC should trigger measure task (not really needed because watchdog might catch this?)
- [ ] measure voltage, perform range switch. Voltage should be same within a certain spec.
- [ ] same for current.
- [ ] set OCP DAC to 0 and MAX and see if it triggers/clears
- [ ] same for OVP DAC
- [ ] Manual Fan test

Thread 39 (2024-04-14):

Demo dashboard: MPPT for small solar panels

fietser28, 2024-04-14:
Create a studio dashboard that creates MPPT specific graphs and calculates results.

The graphs will be:
- Current-Voltage
- Power-Voltage

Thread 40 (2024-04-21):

Check/test rise fall time compatibility of inputs to logic

fietser28, 2024-04-21:
Check if the rise/fall times of the ovp,ocp and von comparators and other digital inputs are in the range of the used logic family/ic’s. If not they need to be replaced with Schmitt-trigger equivalents.

fietser28, 2025-01-08:
74HCT series are used. TI specifies a min. rise/fall time of 500ns for this series.

With LM393's from unknown origin I get 500us rise and 6ms(!) fall times with a 2k pull-up at the OVP/OCP comparators.

This is clearly not within spec but **everything is working fine**. Probably because the switching is very infrequent so thermal issues at the input of the TTL chips are not a problem.

Clamping in response to large OVP or OCP steps happens in around 250us.

Possbile improvements for later:
- use genuine LM393's
- use fast comparators with TTL output. Better but more expensive and possibly not jelly bean components

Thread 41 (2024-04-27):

Implement MEASure commands

fietser28, 2024-04-27:
Implement real MEAS commands that start a new measurement.

fietser28, 2024-12-06:
Implemented: MEASure:CURRent?, MEASure:VOLTage?, MEASure:POWer?

Closed 2024-12-06.

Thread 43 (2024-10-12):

Add basic statistic support

fietser28, 2024-10-12:
- [x] Add min,max and average calculations for current, voltage and power.
- [x] Implement run and clear states.
- [x] Add SCPI commands for clear and run/pause
- [x] Add SCPI commands for querying different stats. As options to existing fetch commands?
- [x] Add UI to control and display stats in separate screen
- [x] Add stats display option instead of capacity panel/make suitable with swipe?

fietser28, 2024-11-02:
Implemented.

Closed 2024-11-02.

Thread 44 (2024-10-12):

Standalone enclosure design

fietser28, 2024-10-12:
Finish a standalone enclosure design based on:
- Hammond aluminium extrusion,
- 3D printed frames
- PCB based front and back panels OR 3D printed panels integrated with frames.

fietser28, 2024-11-03:
Done.

Closed 2024-11-03.

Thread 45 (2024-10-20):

ADD Beeper config screen and settings

fietser28, 2024-10-20:
ADD a screen to set the beeper options:
- [x] On/off beep on OCP/OVP/OTP/OPP
- [x] On/off beep on capacity limit reached
- [x] Beep on reverse polarity
- [x] Beep on sense error
- [x] Default beep duration
- [x] Encoder click on/off
- [x] SCPI set/query for all of the above

fietser28, 2024-10-23:
Done.

Closed 2024-10-23.

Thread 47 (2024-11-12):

Add event log

fietser28, 2024-11-12:
- [x] define log data structure with levels
- [x] (circular?) data structure for event logging
- [x] UI screen to display event log including level filter
- [x] SCPI command to read event log (different from scpi errors, or will certain event duplicate to SCPI error log?
- [x] remove ui_glue.h/.cpp

Event log will not be persistent across reboots for now.

Closed 2025-02-02.

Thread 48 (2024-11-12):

Implement reverse polarity FW support

fietser28, 2024-11-12:
- [x] beep when reverse polarity is detected
- [x] ui signalling when reverse polarity is detected (switch to warning screen?)
- [x] add SCPI query if reverse polarity is detected
- [x] TBD: add reverse polarity software latch??

fietser28, 2025-01-12:
SCPI commands:

```[SOURce]:INPut:PROTection:TRIPped:REVerse[:POLarity]?```
Returns if reverse polarity was detected when input was on (causing a protection triggered status). This acts as a latch.

```FETCh[:SCALar]:VOLTage:REVerse[:POLarity]?```
Instantaneous readout of reverse polarity detection. Works both when input is on or off.

Closed 2025-01-12.

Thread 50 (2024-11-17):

Full automatic calibration in dashboard

fietser28, 2024-11-17:
Create a panel for calibration in the dashboard where calibration is fully automated, starting with an empty EEPROM.

fietser28, 2024-11-17:
- [ ] OCPH is not working in current dashboard
- [ ] find solution for automatic uset calibration without changing cables.

fietser28, 2024-11-20:
Calibration order matters, fine tuning it.

fietser28, 2024-11-22:
Working, ocp and ovp need double run.

Closed 2024-11-22.

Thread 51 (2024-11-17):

Move fan controller across isolation: save on Si8602

fietser28, 2024-11-17:
If we move the MAX31760 near the MCU and use simple optocouplers for the PWM and taco signals (25KHz digital signals) we save on the rather expensive SI8602AB IC (I2C isolator).

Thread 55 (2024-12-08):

UI: Capacity editing capacity limits should be possible when capacity limits is not active.

fietser28, 2024-12-08:
Currently when the capacity limit is disabled the editing of the capacity limits is also disabled in UI. This should not be the case, you should still be able to edit the limits.

Also check if color schemes are OK.

fietser28, 2024-12-08:
Fixed.

Closed 2024-12-08.

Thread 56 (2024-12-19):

Create electronic load test dashboard

fietser28, 2024-12-19:
Crete a dashboard performing the following tests. During the test screenshots of oscilloscope from current and differential probe will be added to a generated report (PDF?)

Tests, each test will be performed for different voltages and currents:
- [ ] Turn on load in CC mode. Validate turn on dynamics
- [ ] Turn off load in CC mode.
- [ ] Current set step in CC mode.
- [ ] Tests above but now in CV mode.
- [ ] Simulate hot plug by turning on power supply when load is on
- [ ] Test behaviour when voltage drops below Von
- [ ] Test OCP dynamic behaviour
- [ ] Test OVP
- [ ] Test Von behaviour when voltage rises slowly
- [ ]

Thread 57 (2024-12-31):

Fix errors on v4-D

fietser28, 2024-12-31:
- [x] D15 doesn't work. Test without OR replace with a 2N7002 OR use pin 10 of U40e (negative of clampoff)
- [x] Test reverse polarity without R50

fietser28, 2025-01-03:
- Made D15 a do not place. Fixed problem, clamping now working within around 150us.
- Even without R50, the reverse polarity is a bit jumpy. May need more testing.

Closed 2025-01-06.

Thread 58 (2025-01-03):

Implement better support for remote sense errors

fietser28, 2025-01-03:
Remote sense should:

- [ ] Make Sense word and line on main page color red when there is currently a remote sense condition (so not latched)
- [ ] Same for icon on protection page if remote sensing is enabled.
- [ ] Always beep when a remote sensing error occurs.
- [ ] Add SCPI command to query remote sensing status.
- [ ] Add option to test for remote sensing error when load is OFF by comparing measured values with remote sensing on and off.
- [ ] Add option to test for remote sensing error when load is turned on. This test takes several measurement cycles and relay switching.

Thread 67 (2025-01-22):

SCPI loop efficiency

fietser28, 2025-01-22:
Current SCPI / serial processing is done as a busy loop with polling. Change it to interrupt based and make it wait for IO instead of busy polling.

fietser28, 2025-01-26:
Not interrupt based yet, but performance is better now. Also doesn't take as much CPU time as before.

Closed 2025-01-26.

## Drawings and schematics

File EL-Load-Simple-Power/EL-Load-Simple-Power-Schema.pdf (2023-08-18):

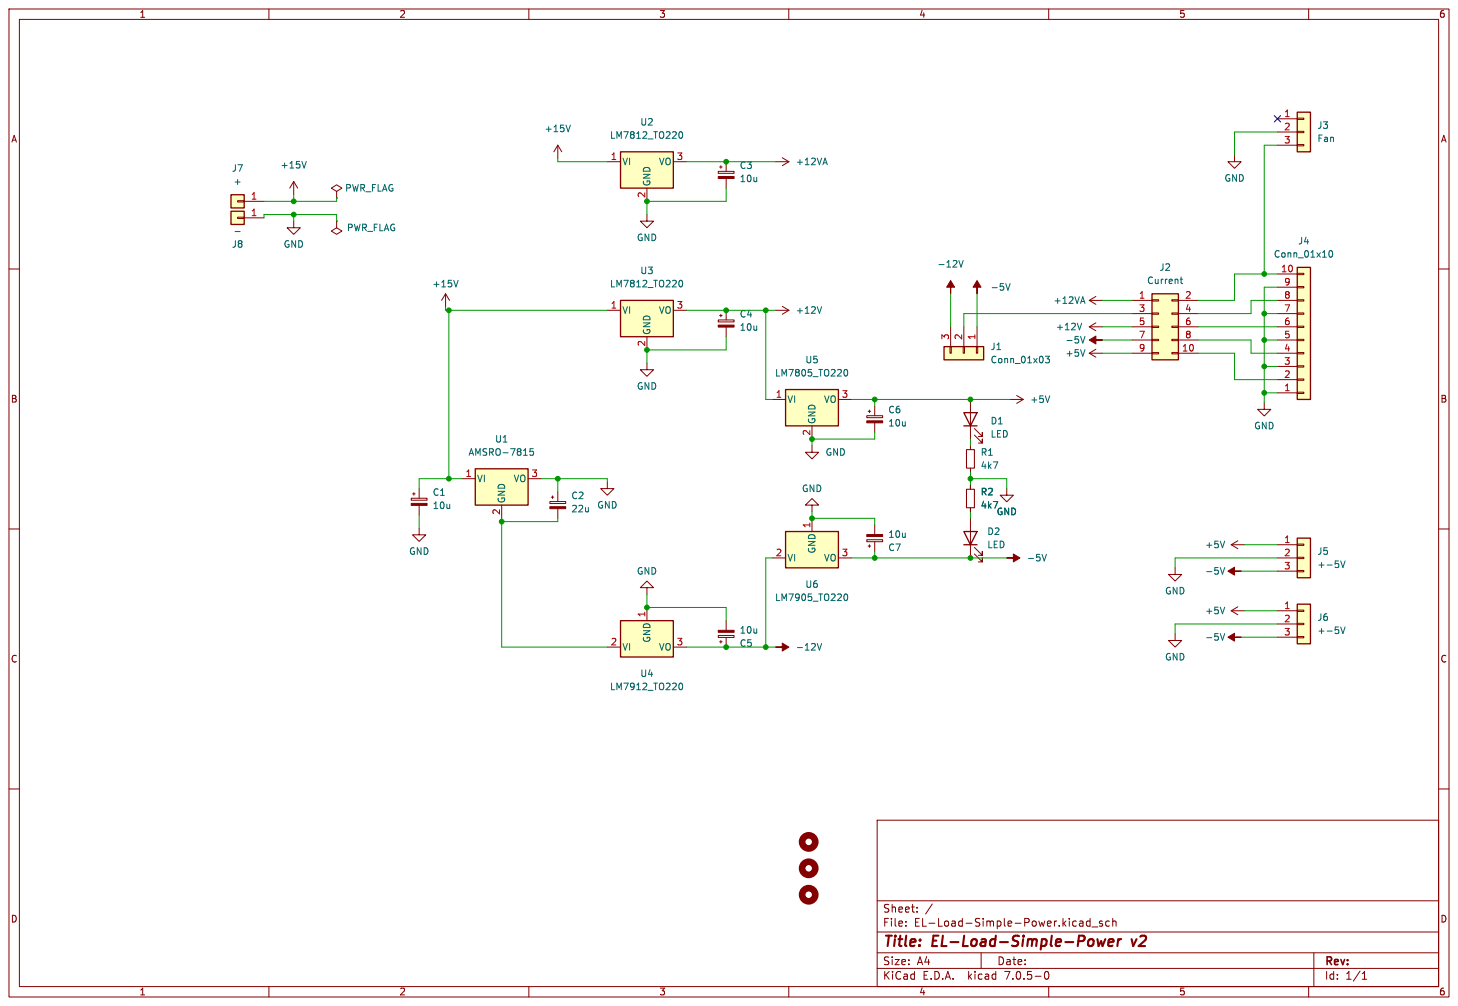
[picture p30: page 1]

File: EL-Load-Simple-Power.kicad_sch Sheet: /

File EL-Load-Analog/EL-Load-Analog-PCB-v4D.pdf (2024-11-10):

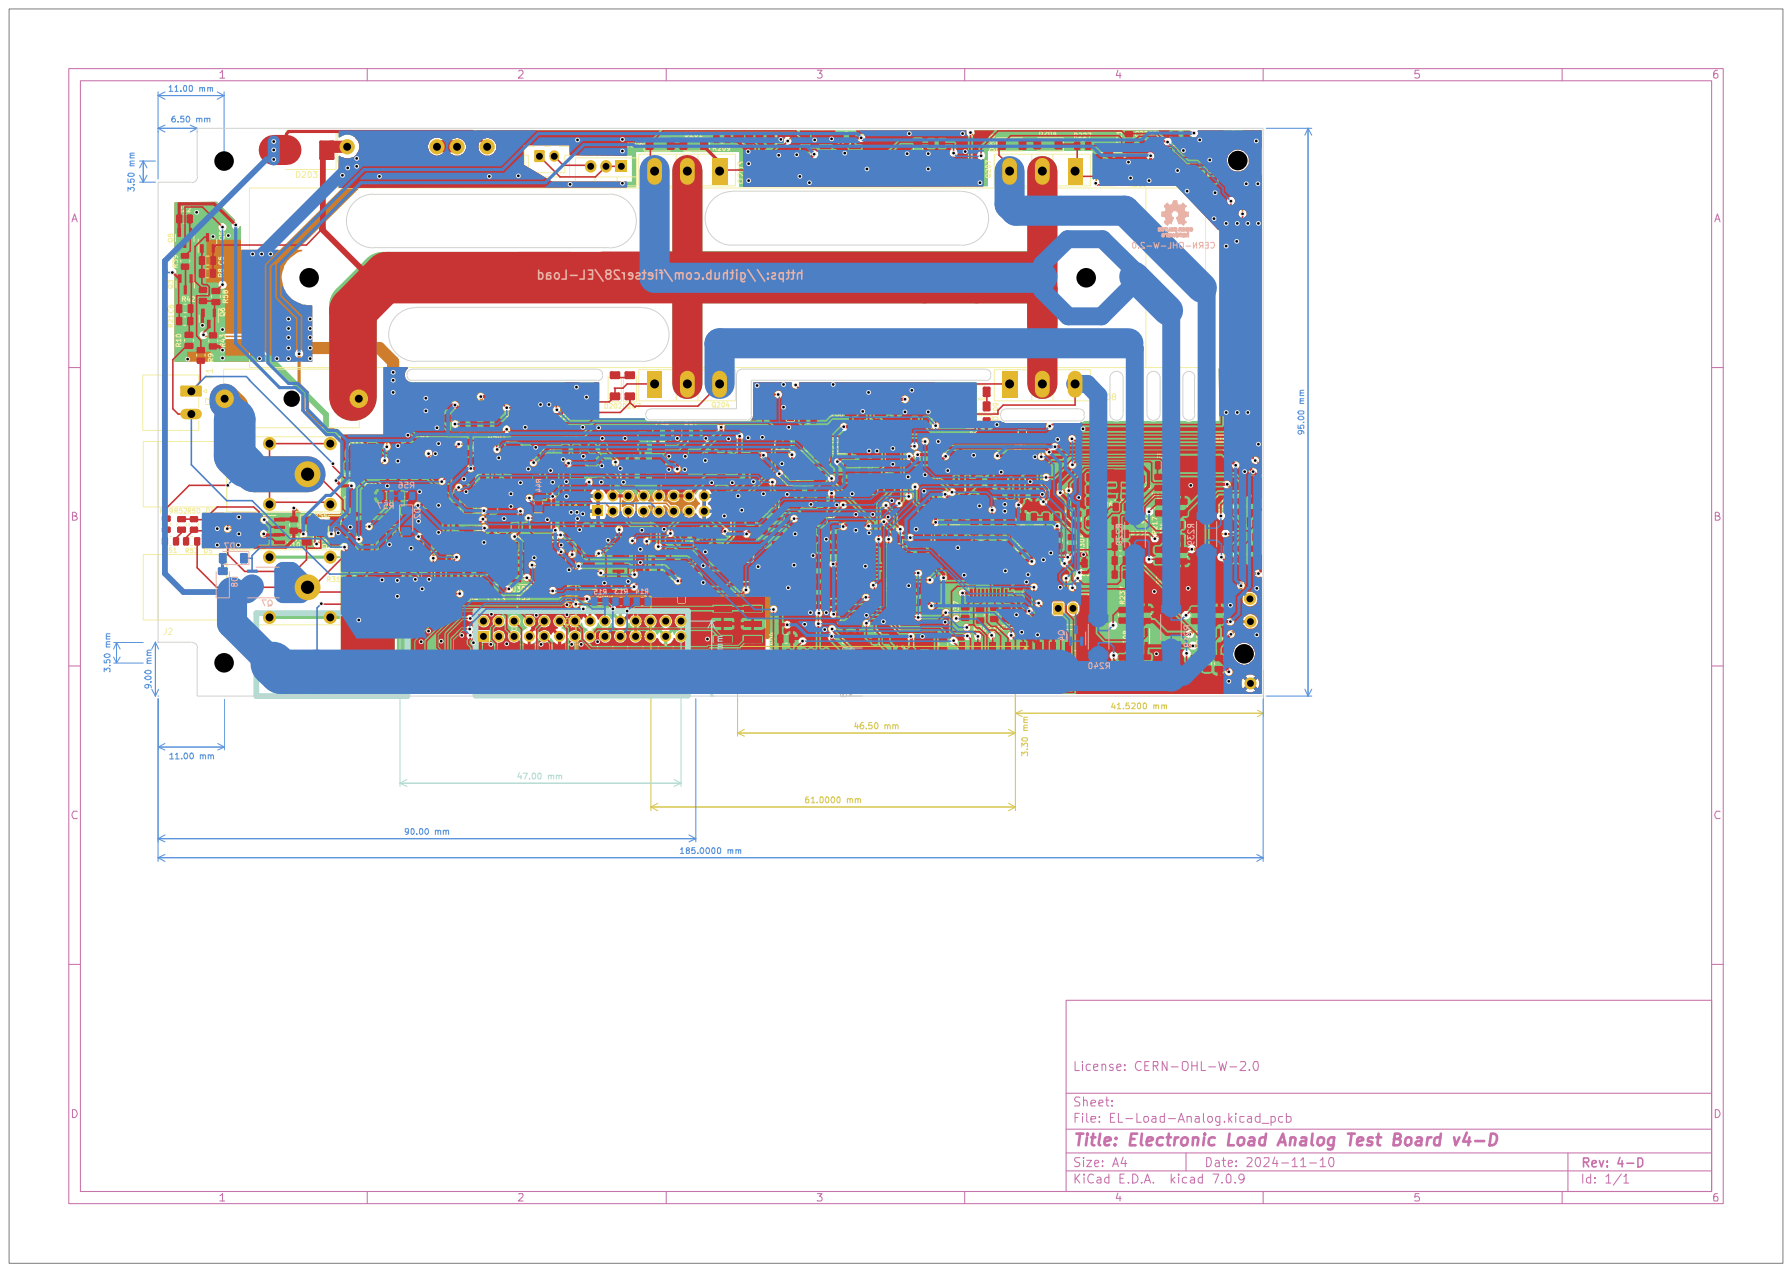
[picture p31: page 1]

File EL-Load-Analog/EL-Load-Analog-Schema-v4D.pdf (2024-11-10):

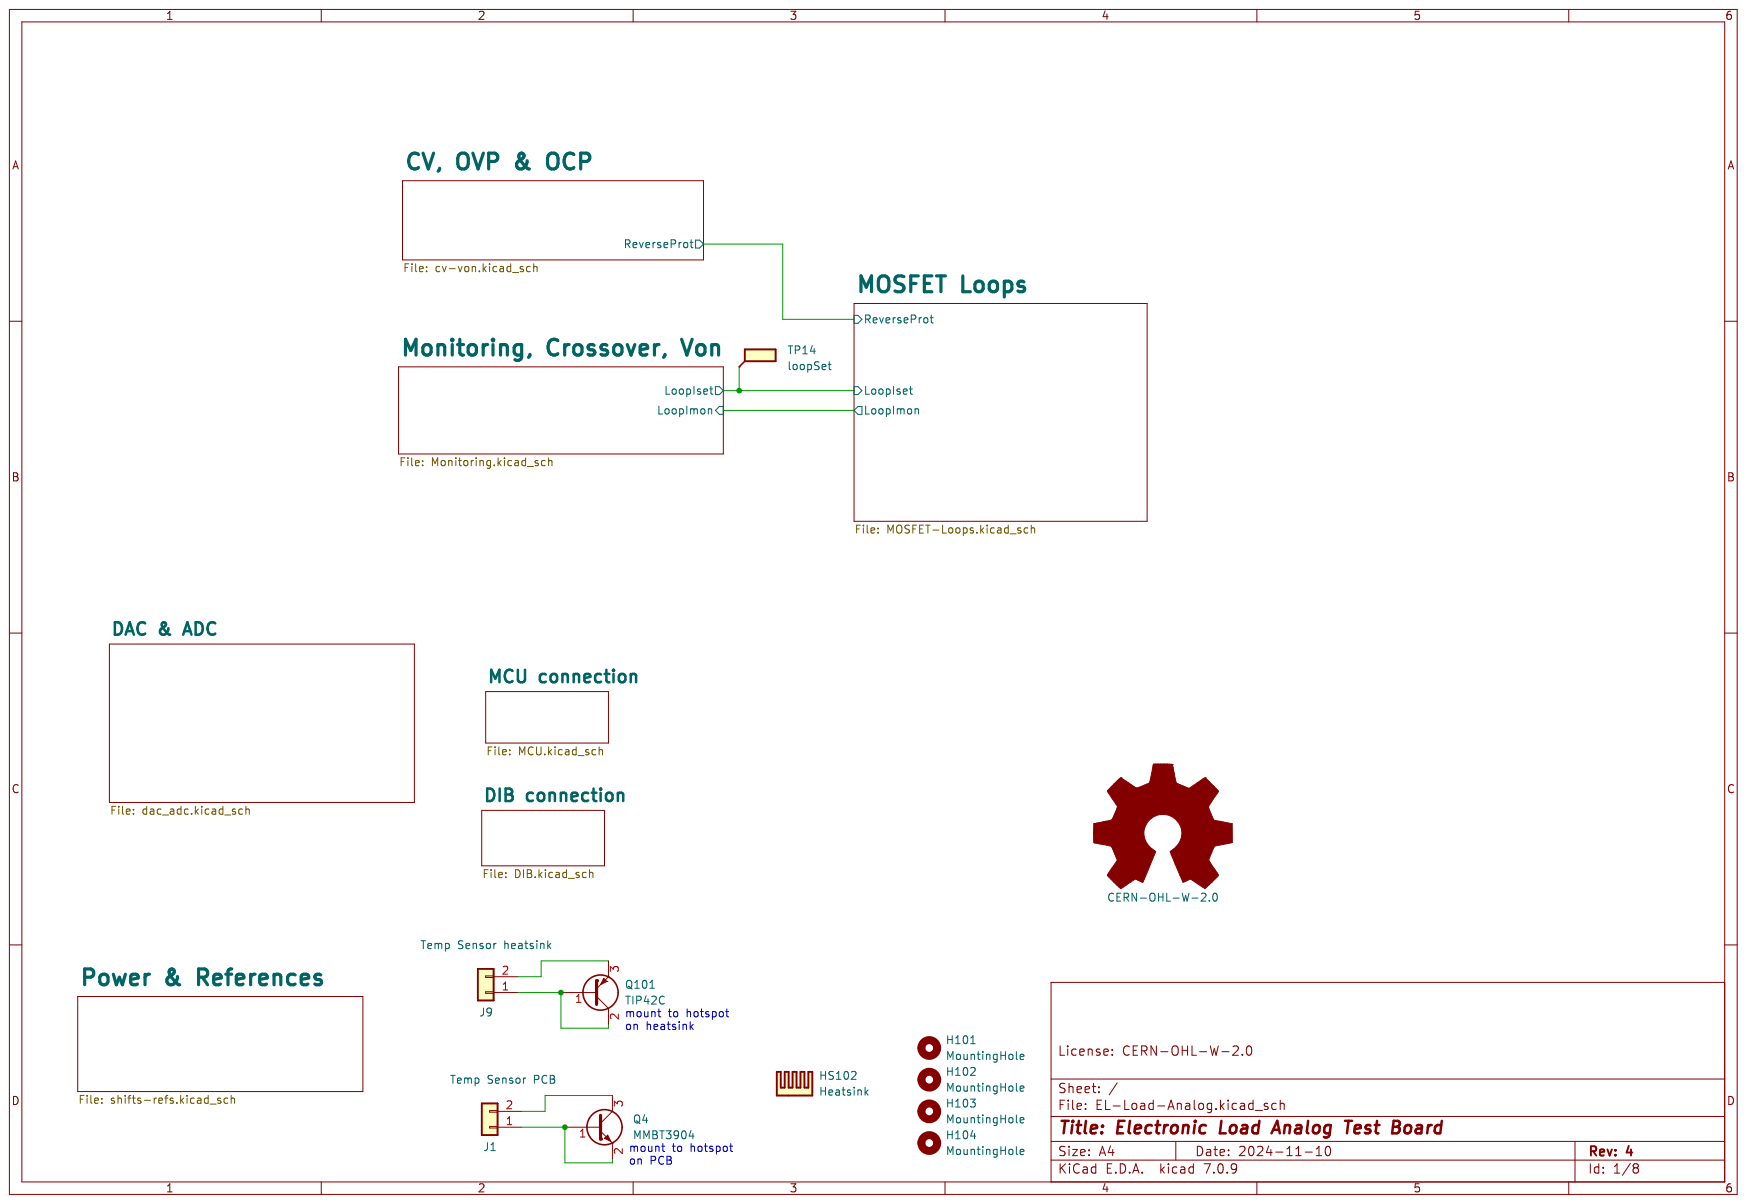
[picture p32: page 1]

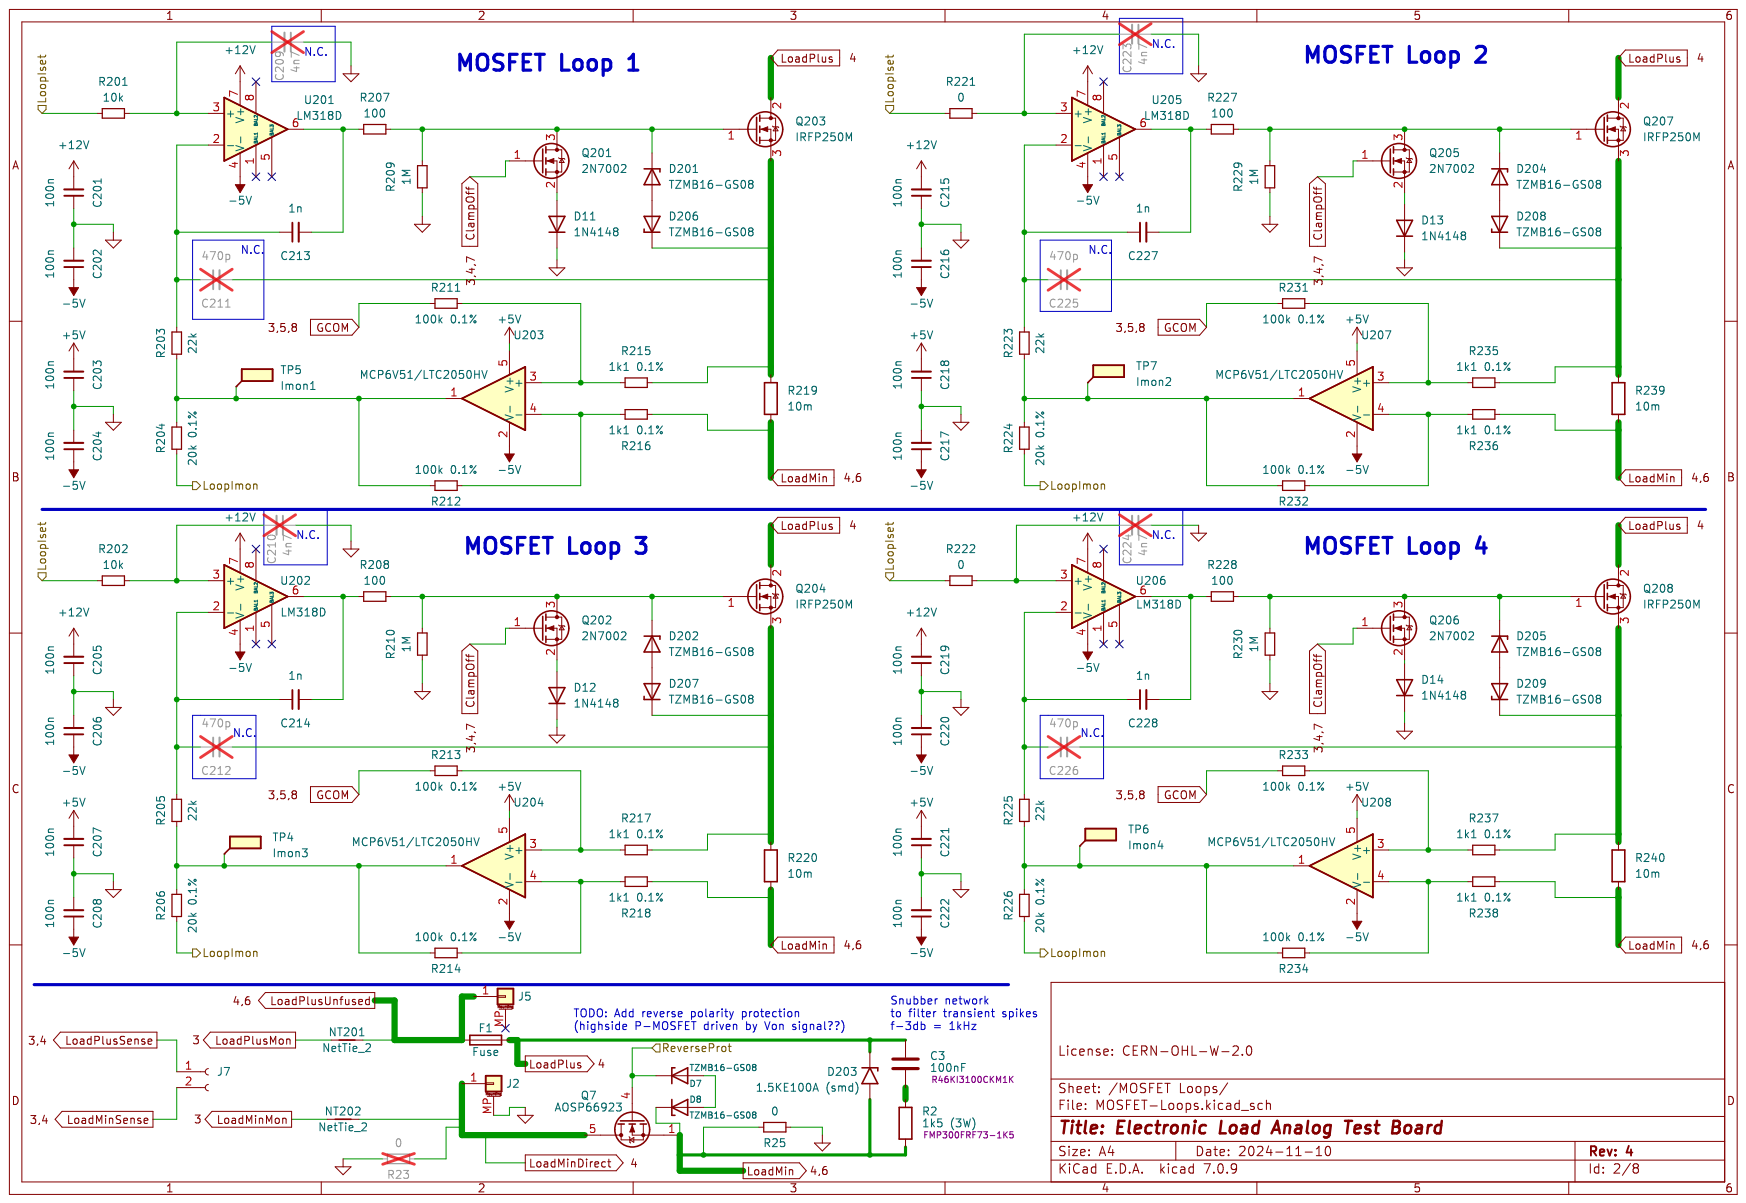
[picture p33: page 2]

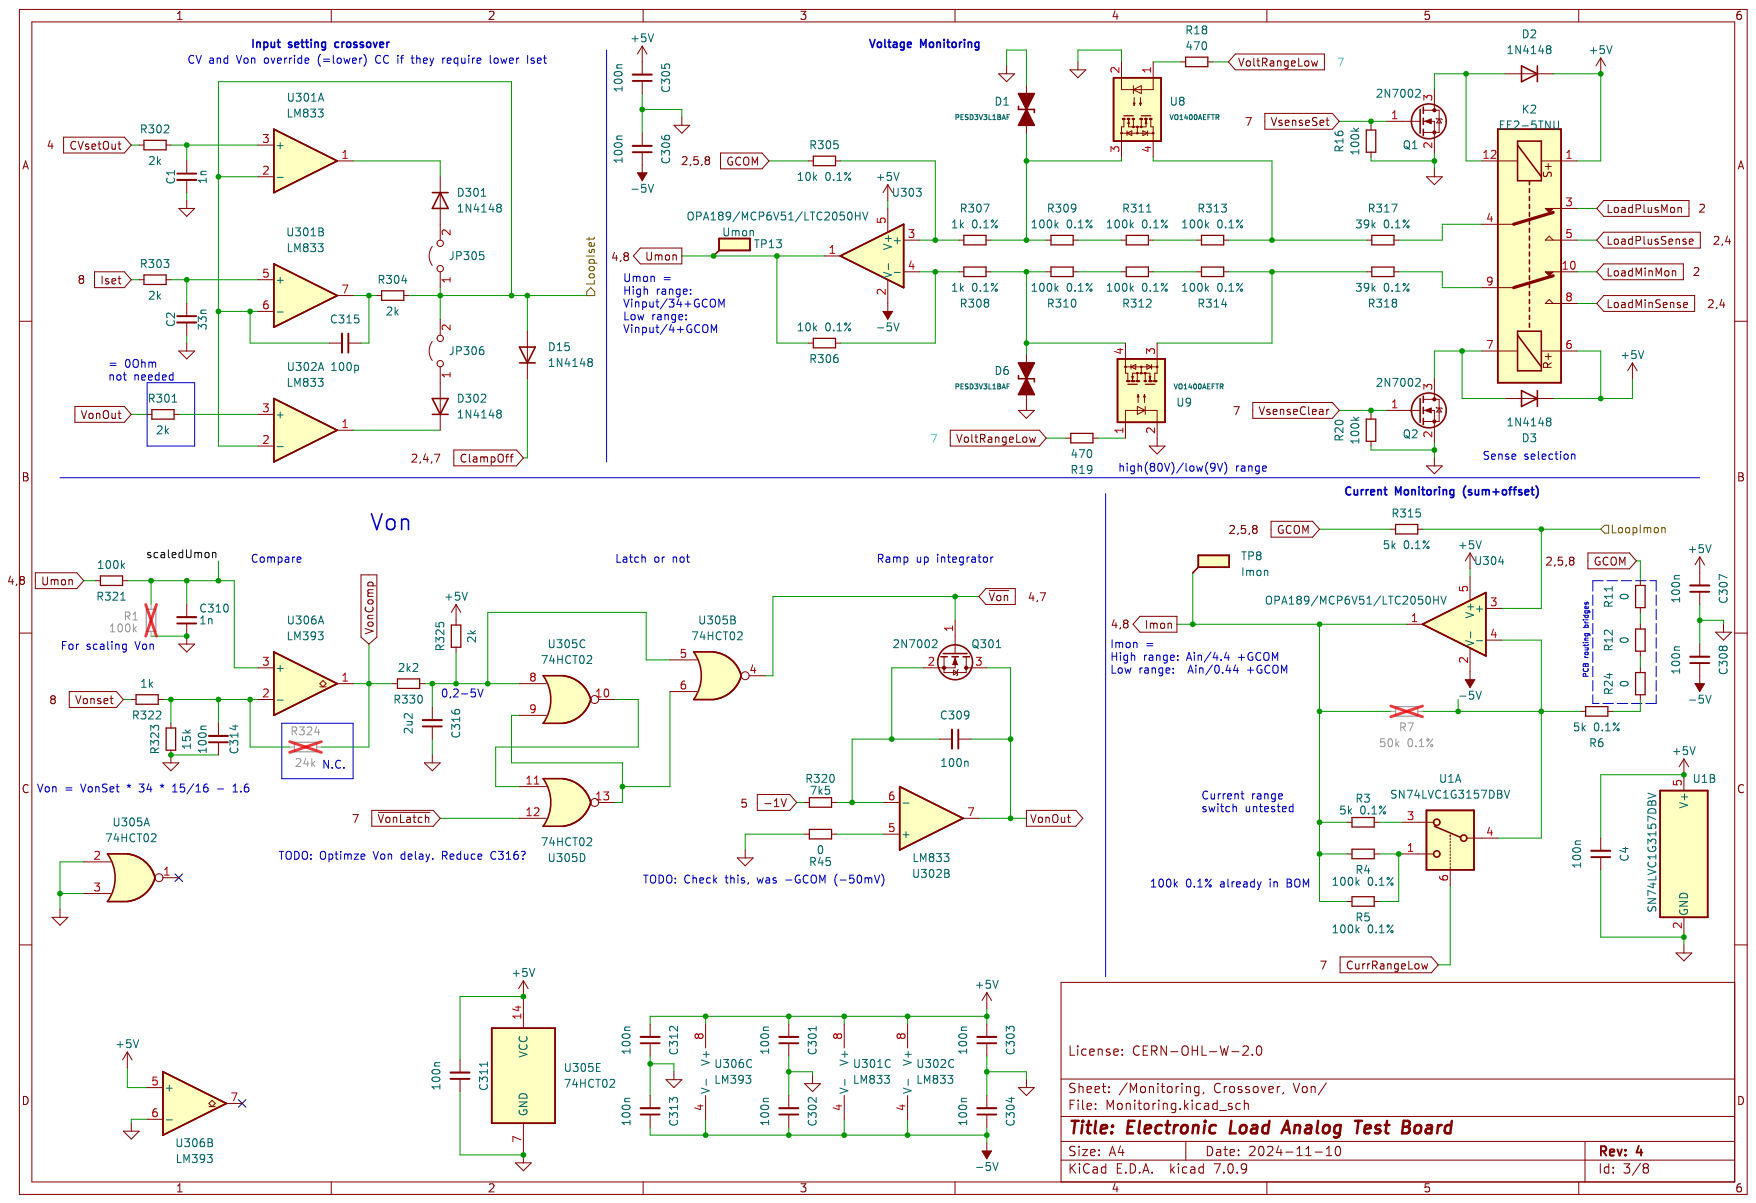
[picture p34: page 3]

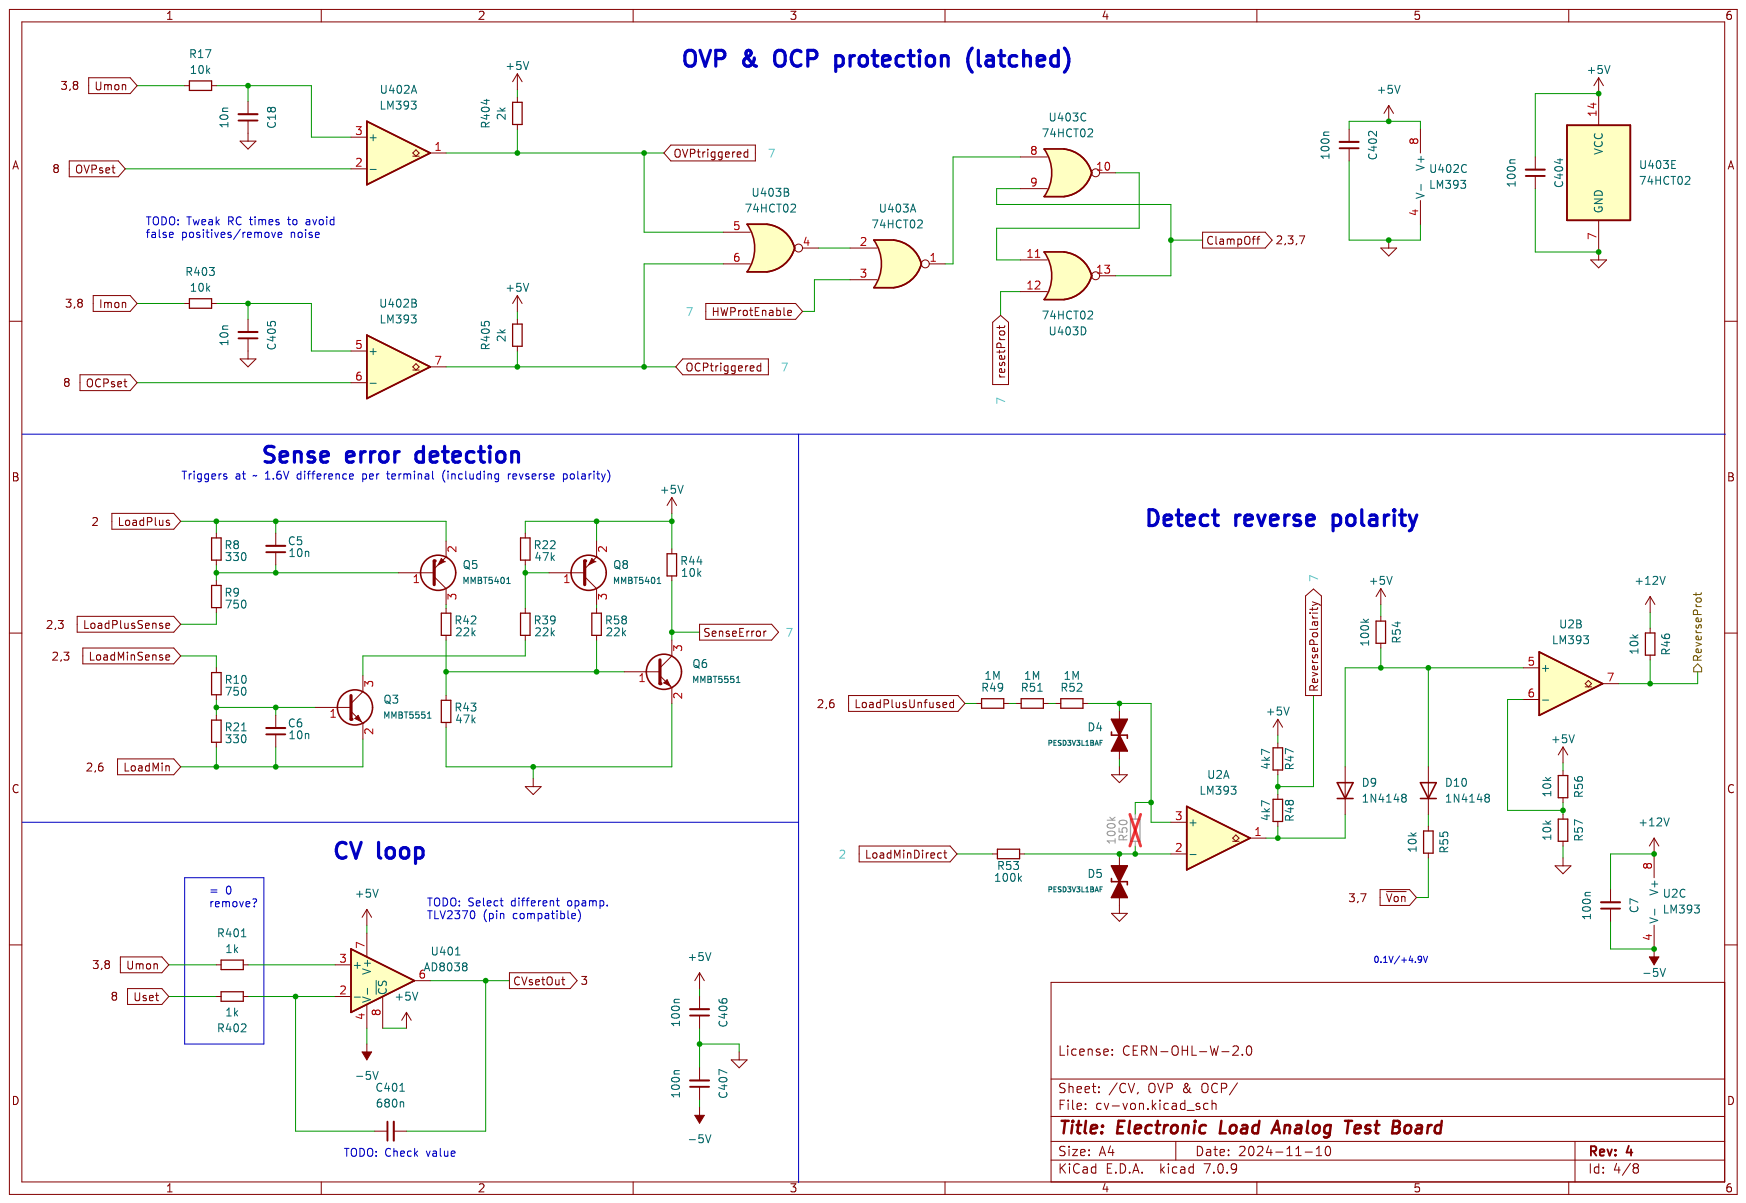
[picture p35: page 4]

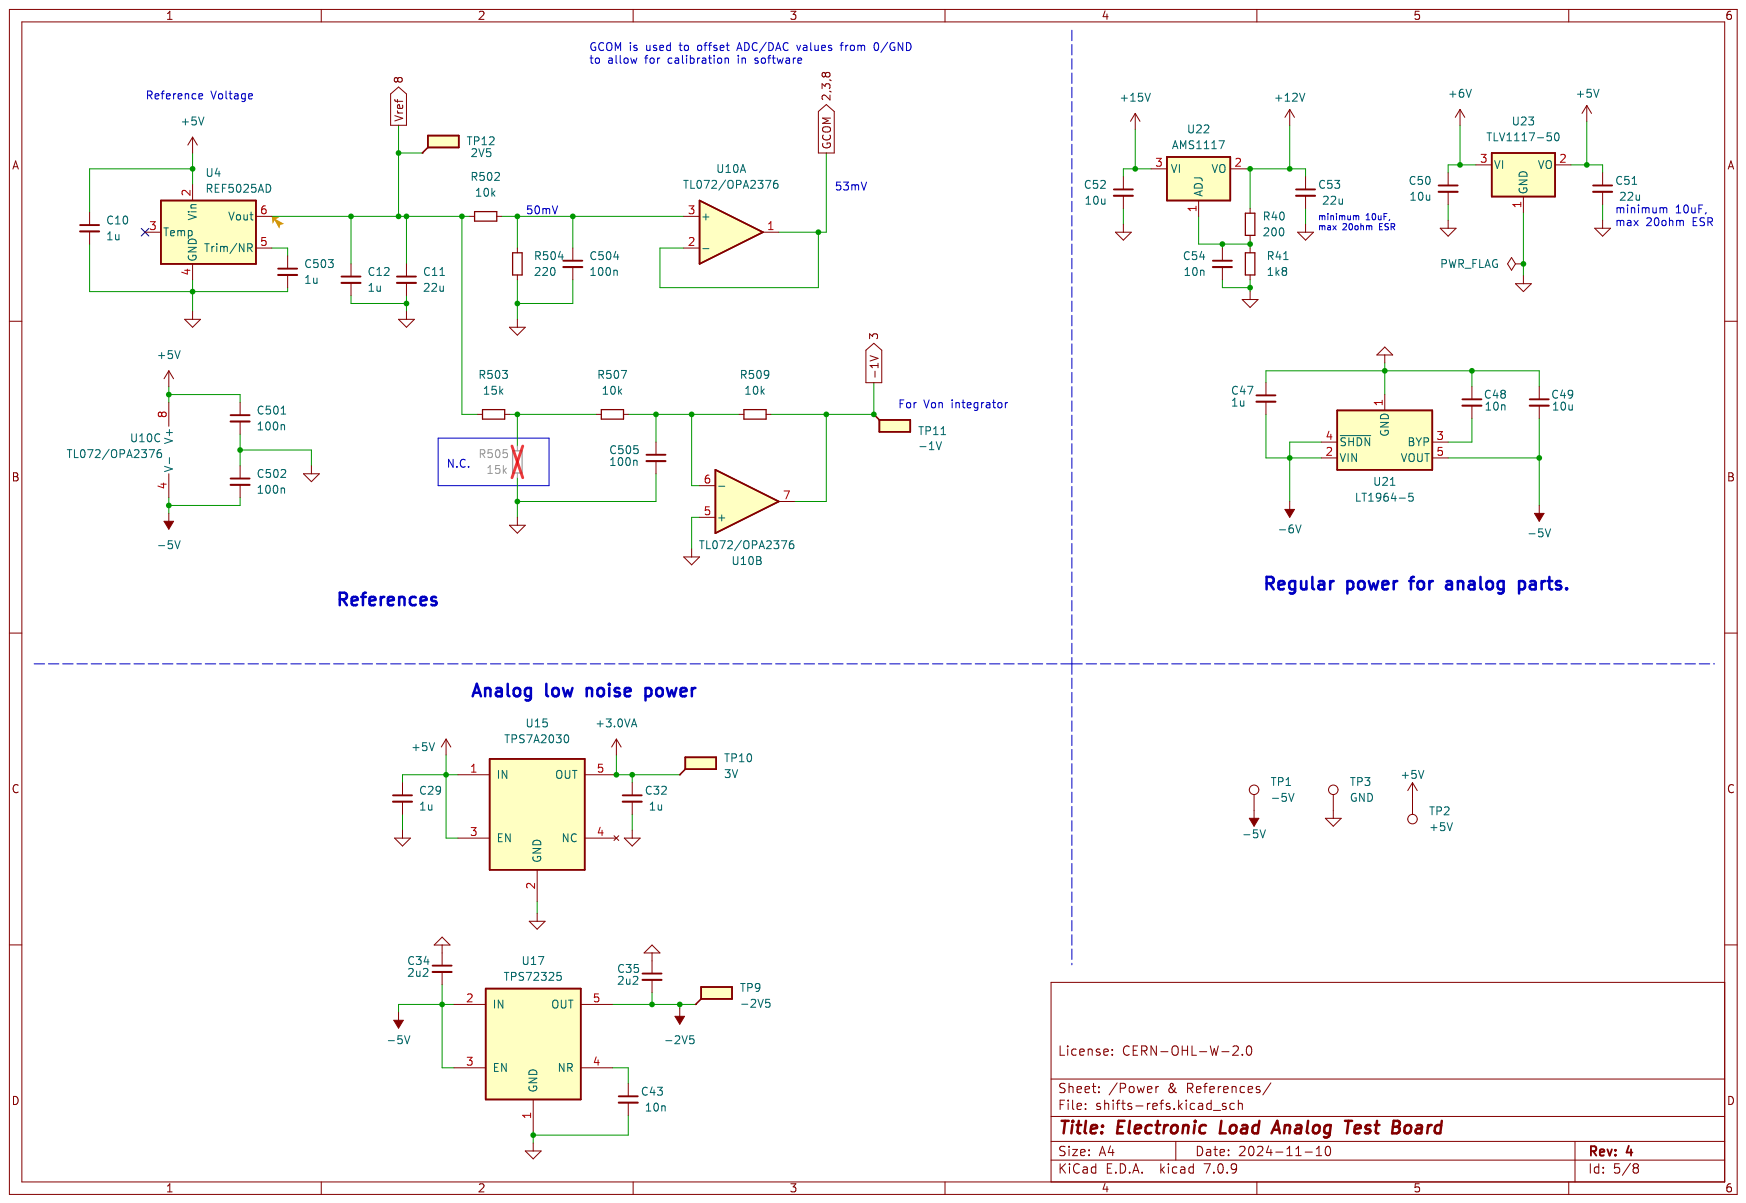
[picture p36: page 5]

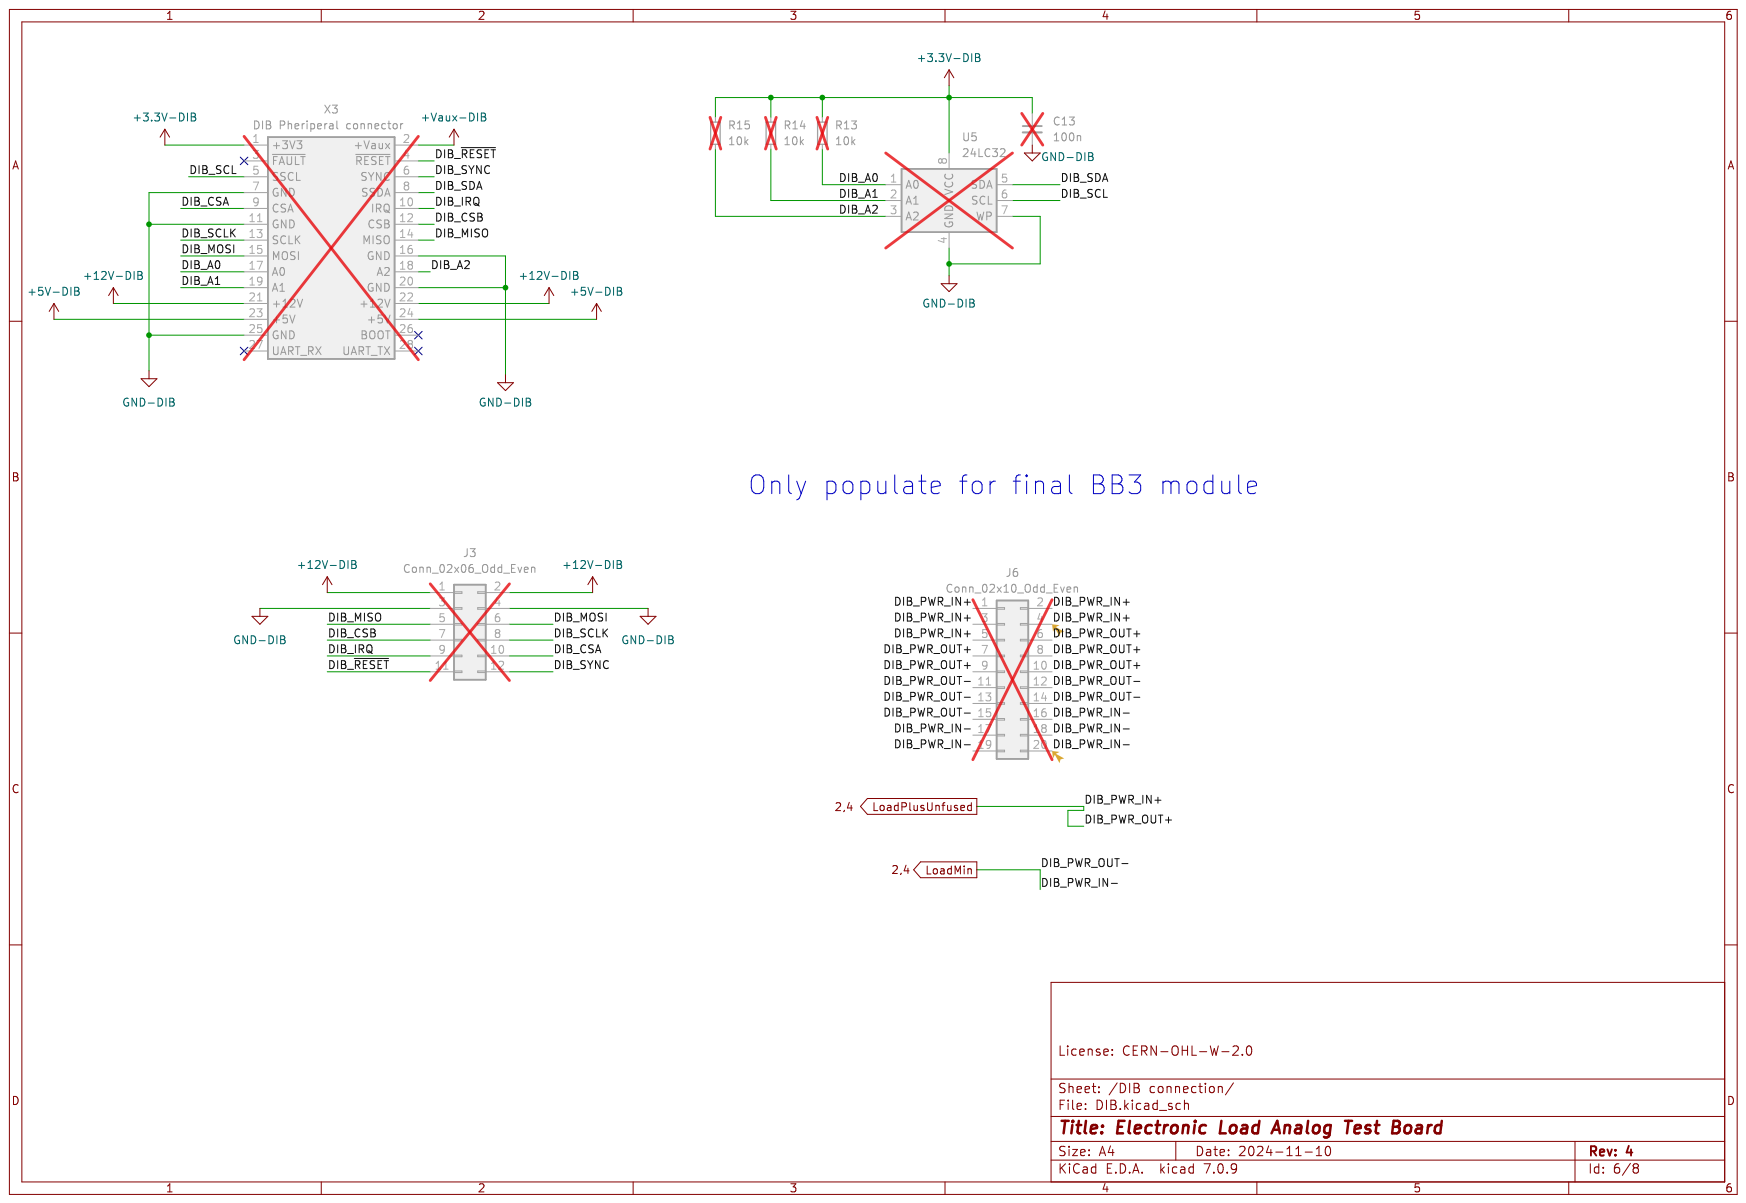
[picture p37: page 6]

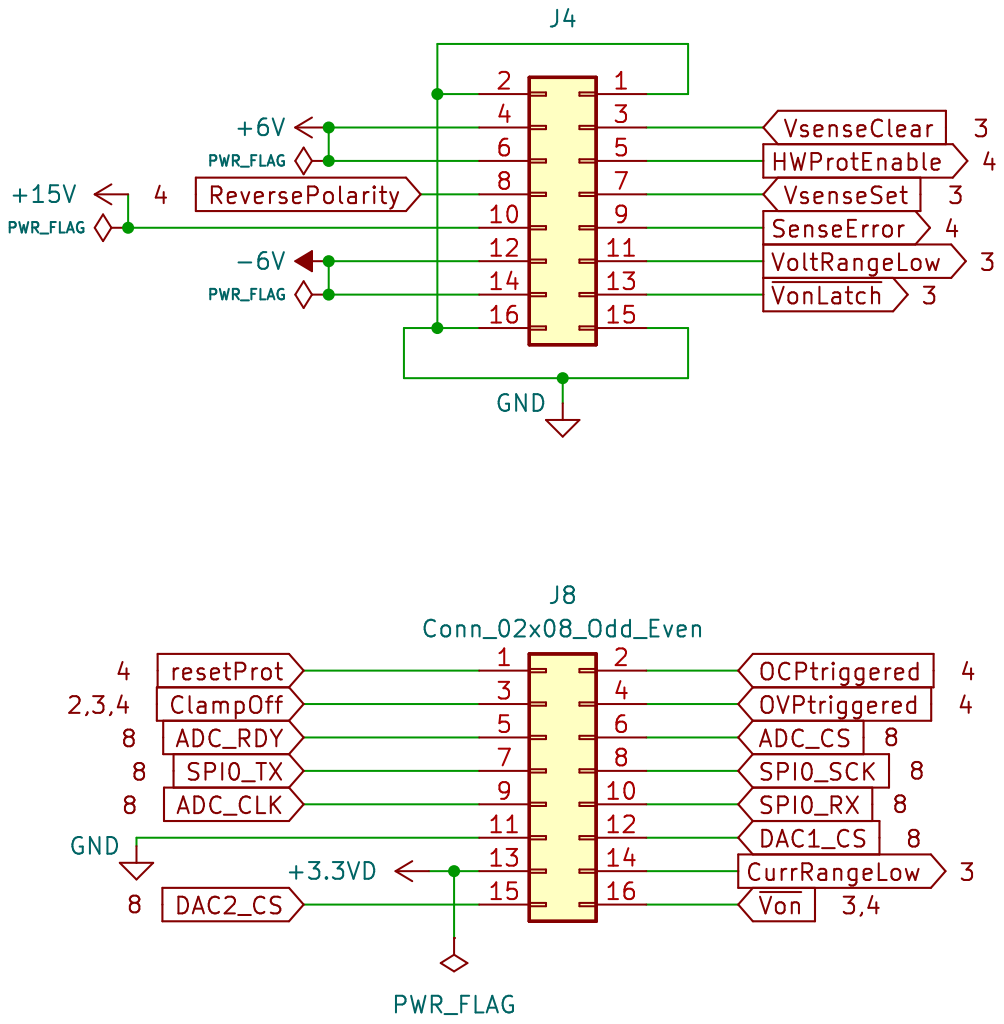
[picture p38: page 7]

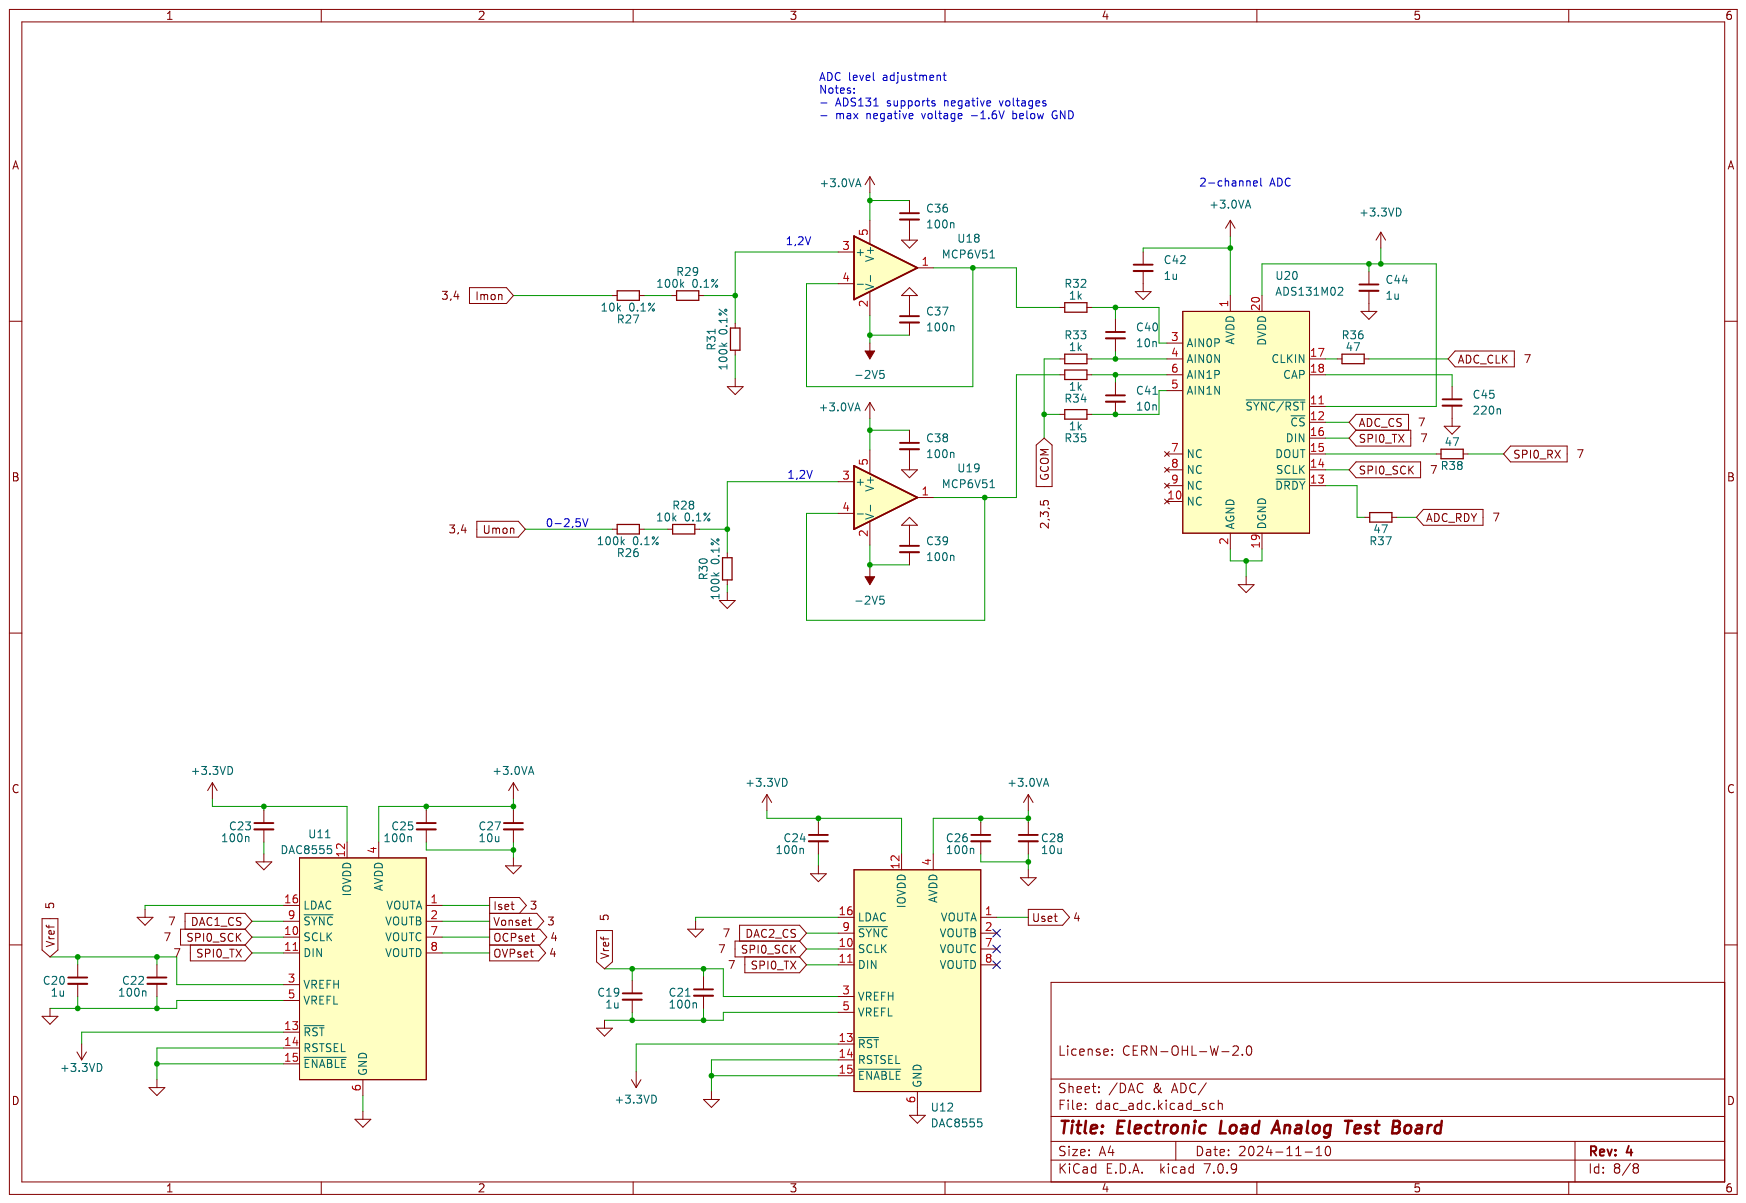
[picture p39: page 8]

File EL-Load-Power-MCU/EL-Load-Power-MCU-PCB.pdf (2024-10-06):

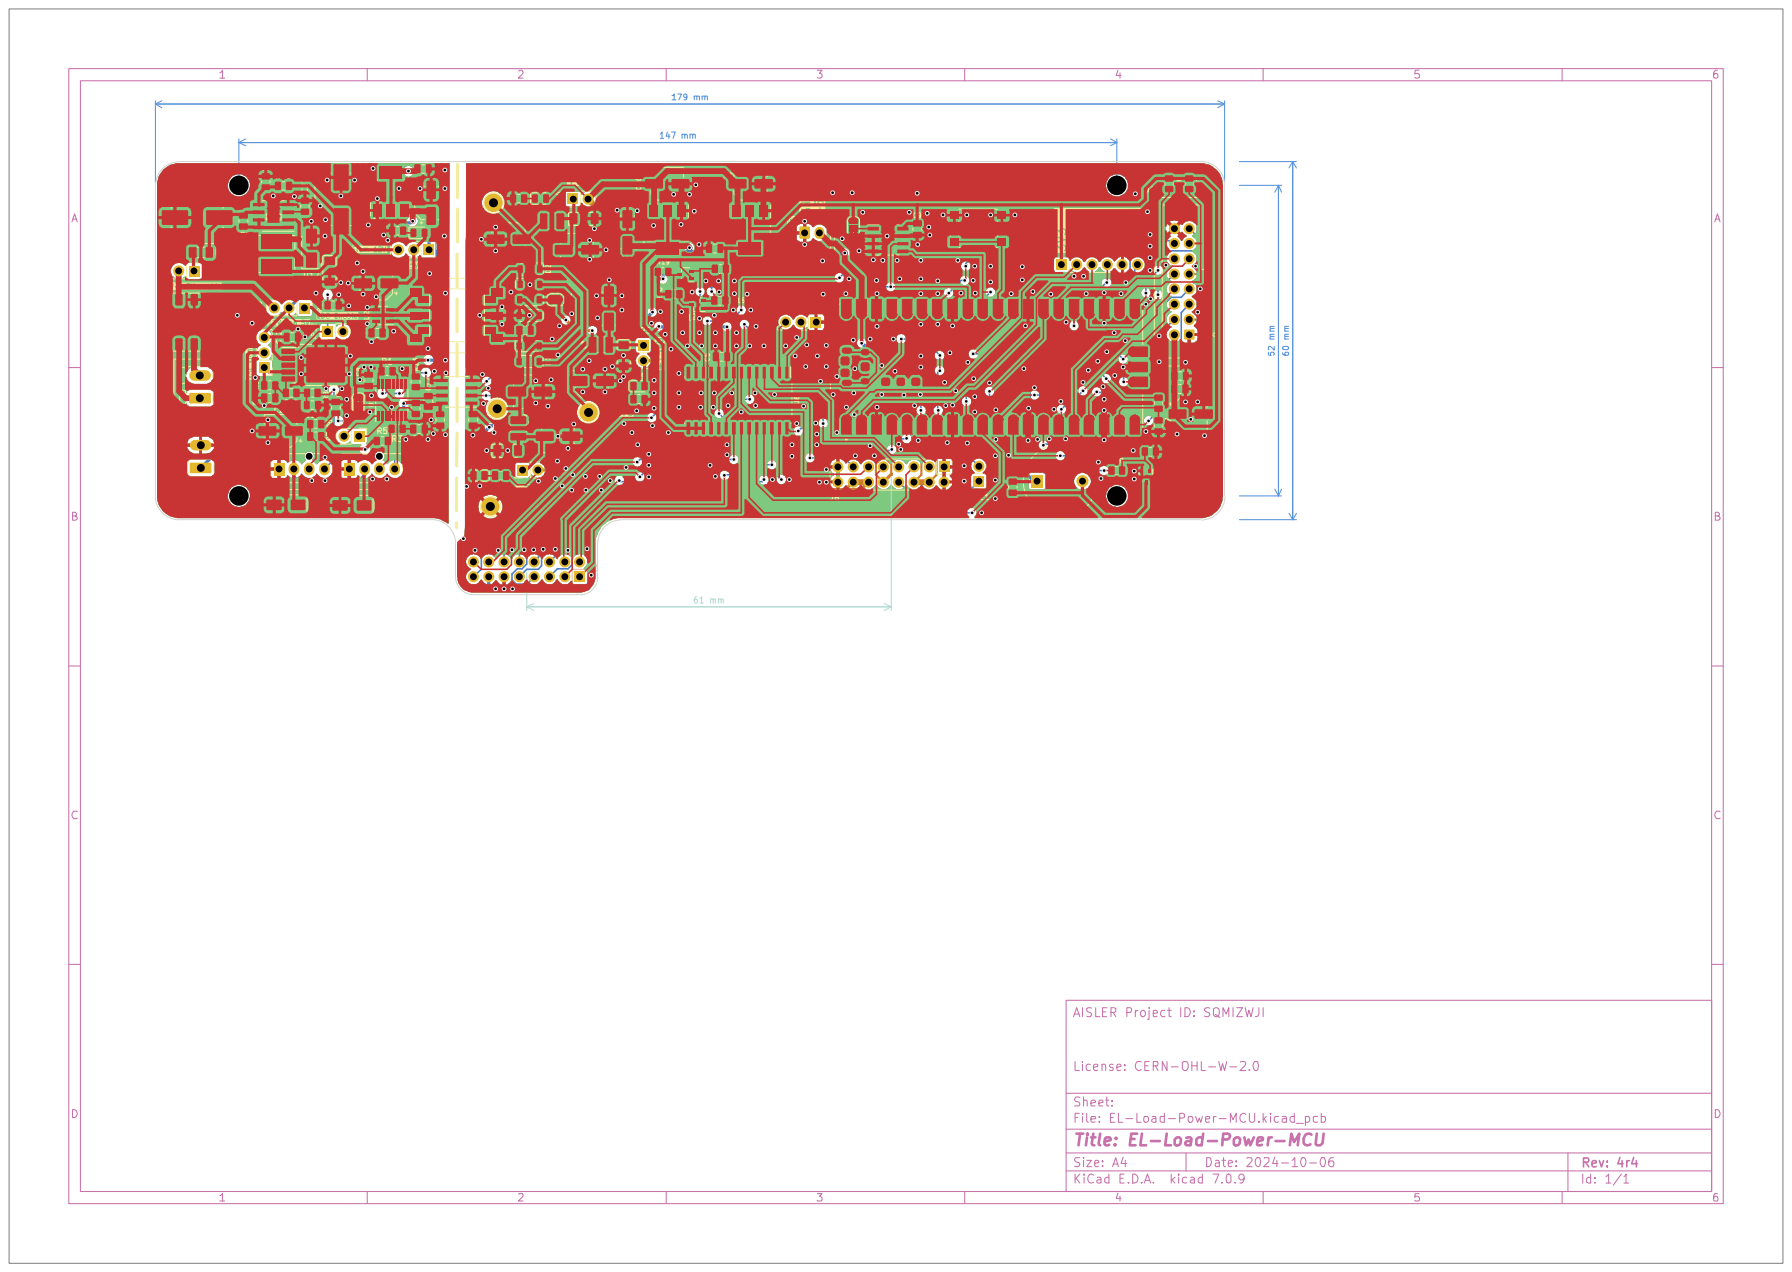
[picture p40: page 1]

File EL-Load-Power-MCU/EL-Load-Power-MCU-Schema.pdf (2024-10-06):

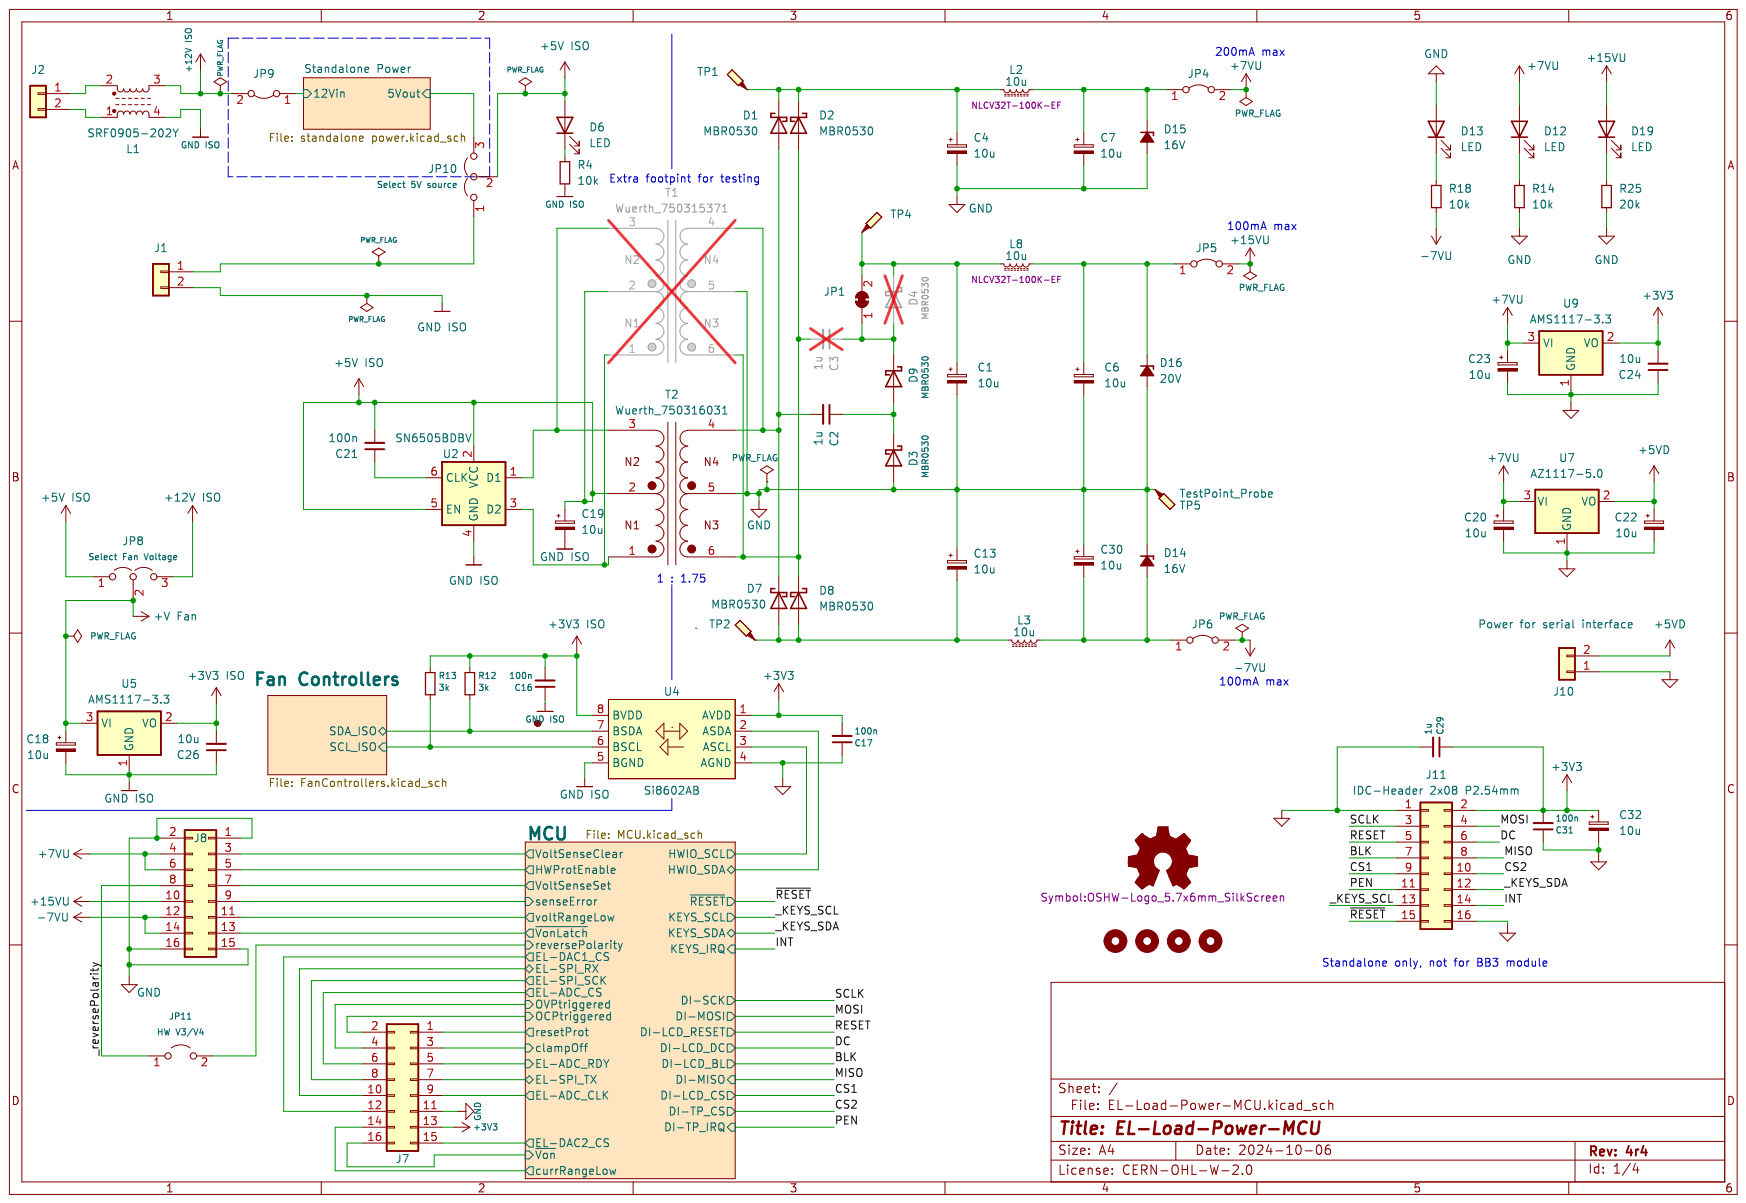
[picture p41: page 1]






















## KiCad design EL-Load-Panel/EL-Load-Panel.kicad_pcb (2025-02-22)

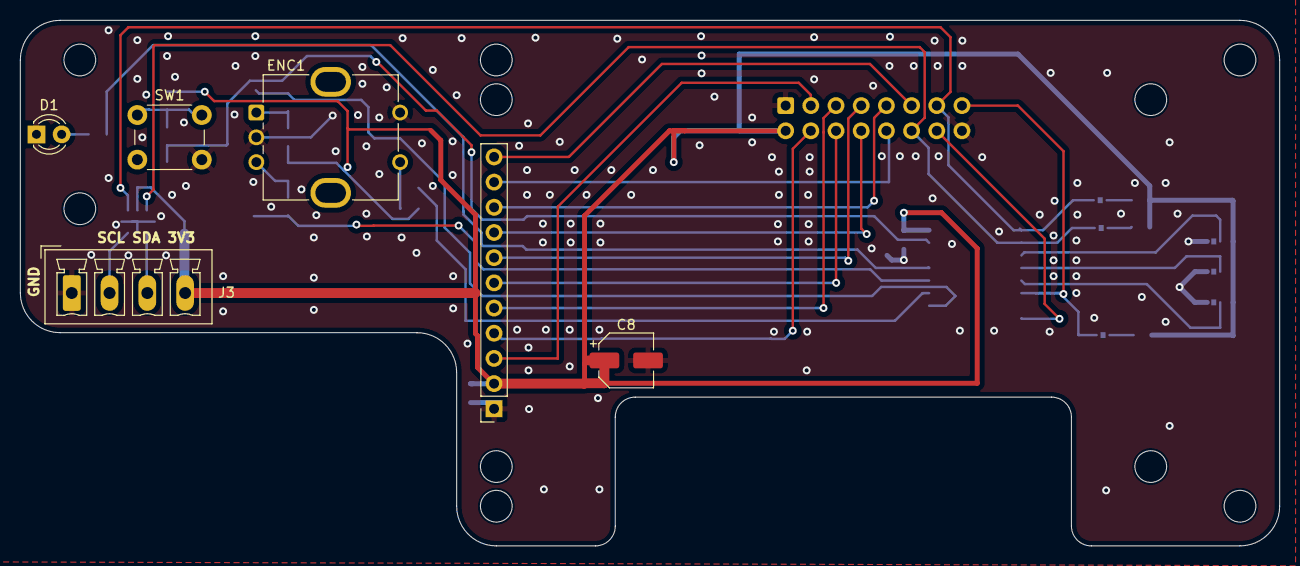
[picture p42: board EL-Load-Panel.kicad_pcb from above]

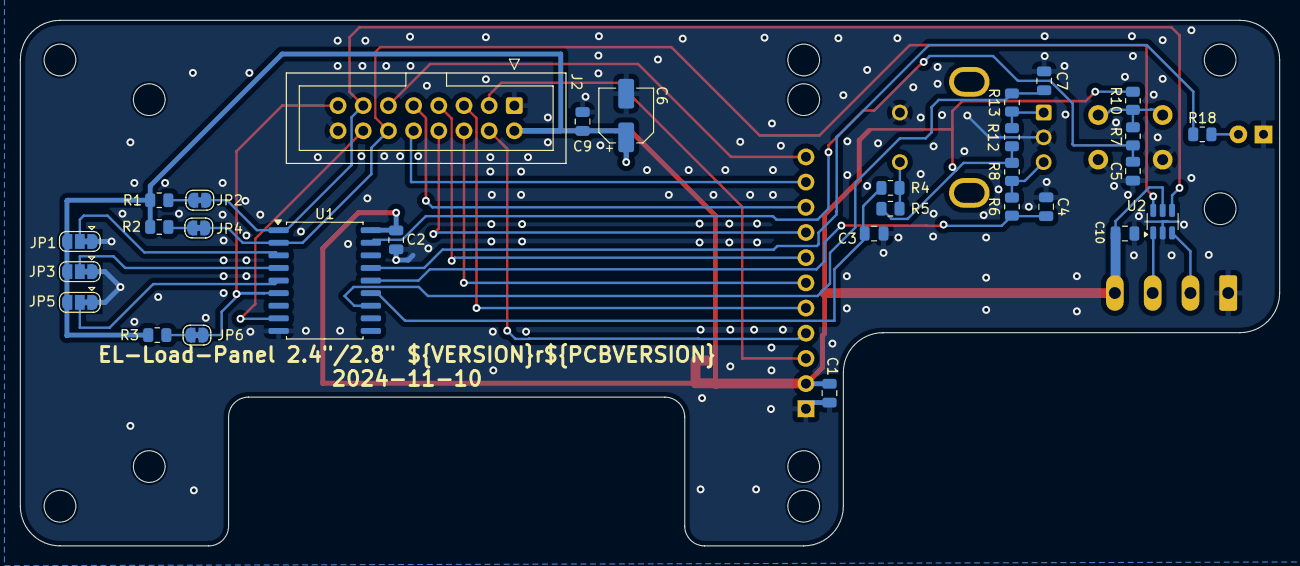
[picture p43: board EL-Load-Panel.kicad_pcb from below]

Board: 2 copper layers, 127.0 x 53.0 mm, 46 parts (30 on the bottom side), 33 nets.

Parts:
C1: 1u; C_0805_2012Metric
C2, C9, C10: 100n; C_0805_2012Metric
C3, C4, C5, C7: 10n; C_0805_2012Metric
C6, C8: 10u; CP_Elec_5x5.8
D1: LED; LED_D3.0mm
ENC1: Bourns PEC11R; RotaryEncoder_Bourns_Vertical_PEC12R-3x17F-Sxxxx
H1, H2, H3, H4, H5, H6, H7, H8, H9, H10: MountingHole; MountingHole_3.2mm_M3
J1: Touchscreen; PinSocket_1x11_P2.54mm_Vertical
J2: Conn_02x08_Odd_Even; IDC-Header_2x08_P2.54mm_Vertical
J3: Conn_01x04_Socket; PhoenixContact_MCV_1,5_4-G-3.81_1x04_P3.81mm_Vertical
JP1: A2; SolderJumper-3_P1.3mm_Bridged12_RoundedPad1.0x1.5mm
JP2: SCL PU; SolderJumper-2_P1.3mm_Bridged_RoundedPad1.0x1.5mm
JP3: A1; SolderJumper-3_P1.3mm_Bridged12_RoundedPad1.0x1.5mm
JP4: SDA PU; SolderJumper-2_P1.3mm_Bridged_RoundedPad1.0x1.5mm
JP5: A0; SolderJumper-3_P1.3mm_Bridged12_RoundedPad1.0x1.5mm
JP6: RST PU; SolderJumper-2_P1.3mm_Bridged_RoundedPad1.0x1.5mm
R1, R2, R3, R4, R5, R6, R7, R8, R10, R12, R13: 10k; R_0805_2012Metric
R18: 270; R_0805_2012Metric
SW1: ON/OFF; SW_PUSH_6mm_H8.5mm
U1: MCP23008-xSO; SOIC-18W_7.5x11.6mm_P1.27mm
U2: USBLC6-2SC6; SOT-23-6

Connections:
+3V3: C1.1, C2.1, C6.1, C8.1, C9.1, C10.1, J1.2, J2.2, J3.4, JP1.3 (B), JP3.3 (B), JP5.3 (B), R1.1, R2.1, R3.1, R5.1, R8.1, R10.1, R12.1, U1.18 (VDD), U2.5 (VBUS)
/A0: JP5.2 (C), U1.5 (A0)
/A1: JP3.2 (C), U1.4 (A1)
/A2: JP1.2 (C), U1.3 (A2)
/BLK: J1.7, J2.7
/CS1: J1.9, J2.9
/CS2: J1.10, J2.10
/DC: J1.6, J2.6
/INT: J2.14, U1.8 (INT)
/MISO: J1.8, J2.8
/MOSI: J1.4, J2.4
/PEN: J1.11, J2.11
/RESET: J1.5, J2.5
/SCL: J2.13, JP2.1 (A), U1.1 (SCL), U2.4 (I/O2)
/SCLK: J1.3, J2.3
/SDA: J2.12, JP4.1 (A), U1.2 (SDA), U2.6 (I/O1)
/encA: C7.1, R13.1, U1.12 (GP2)
/encB: C4.1, R6.1, U1.14 (GP4)
/encS: C3.1, R4.1, U1.13 (GP3)
/sw0: C5.1, R7.1, U1.17 (GP7)
/sw4: R18.1, U1.15 (GP5)
/~RESET: J2.15, JP6.1 (A), U1.6 (~RESET)
GND: C1.2, C2.2, C3.2, C4.2, C5.2, C6.2, C7.2, C8.2, C9.2, C10.2, D1.1 (K), ENC1.C, ENC1.S1, J1.1, J2.1, J2.16, J3.1, JP1.1 (A), JP3.1 (A), JP5.1 (A), SW1.2 (B), U1.9 (VSS), U2.2 (GND)
unnamed: D1.2 (A), R18.2
unnamed: ENC1.A, R12.2, R13.2
unnamed: ENC1.B, R6.2, R8.2
unnamed: ENC1.S2, R4.2, R5.2
unnamed: J3.2, U2.3 (I/O2)
unnamed: J3.3, U2.1 (I/O1)
unnamed: JP2.2 (B), R1.2
unnamed: JP4.2 (B), R2.2
unnamed: JP6.2 (B), R3.2
unnamed: R7.2, R10.2, SW1.1 (A)

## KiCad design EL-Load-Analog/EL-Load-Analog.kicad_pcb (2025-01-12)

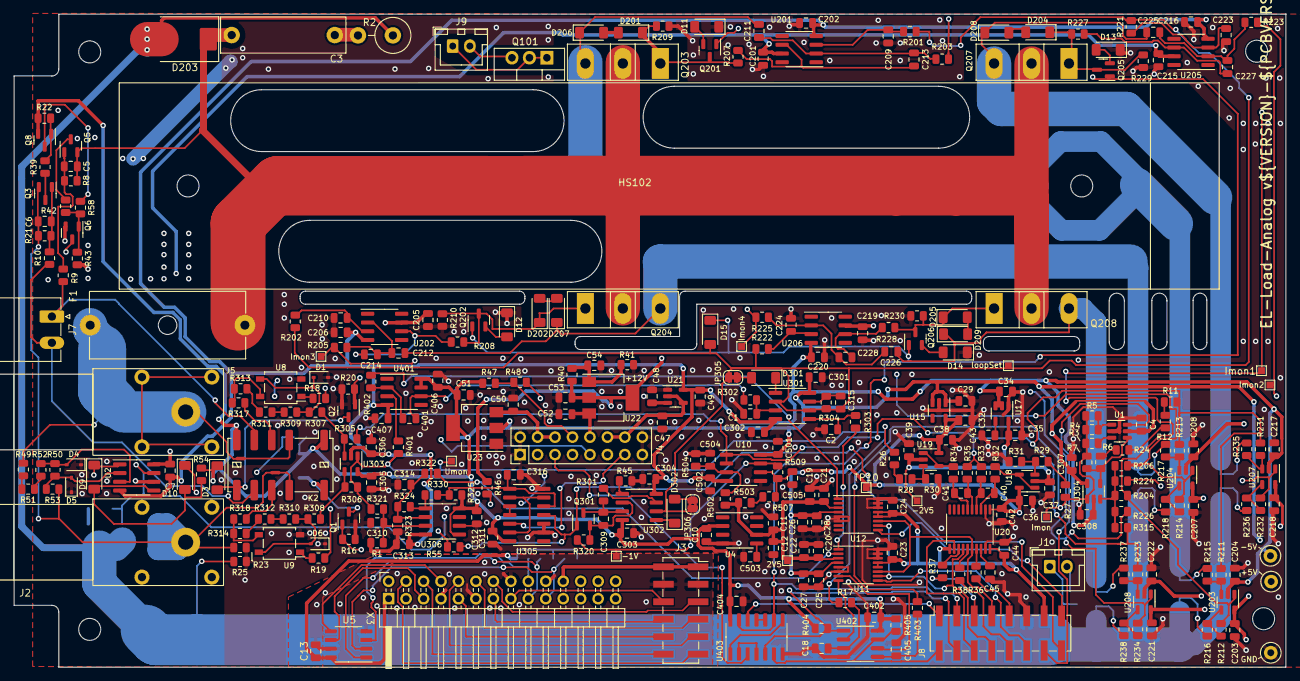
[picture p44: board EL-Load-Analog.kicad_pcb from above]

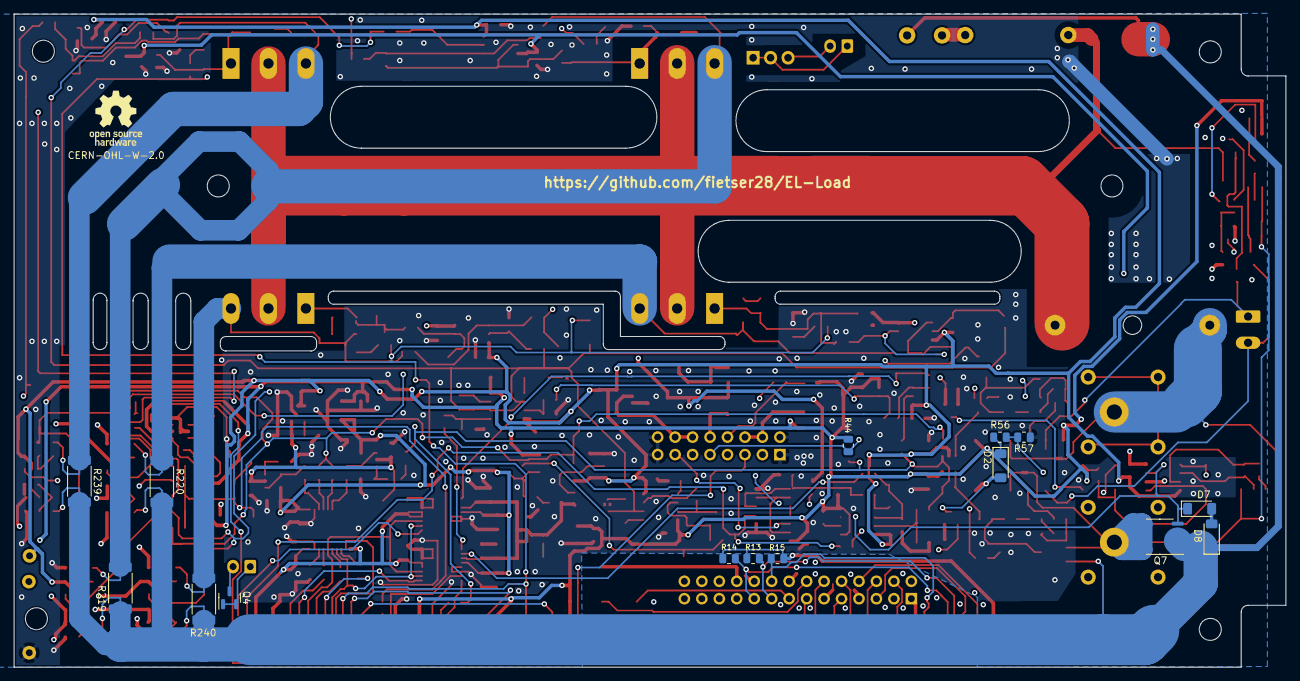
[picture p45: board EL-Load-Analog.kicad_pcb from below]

Board: 4 copper layers, 185.0 x 95.0 mm, 344 parts (16 on the bottom side), 198 nets.

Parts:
C1, C213, C214, C227, C228, C310: 1n; C_0805_2012Metric
C2: 33n; C_0805_2012Metric
C3: 100nF; C_Rect_L18.0mm_W5.0mm_P15.00mm_FKS3_FKP3
C4, C7, C13, C21, C22, C23, C24, C25, C26, C36, C37, C38, C39, C201, C202, C203, C204, C205, C206, C207, C208, C215, C216, C217, C218, C219, C220, C221, C222, C301, C302, C303, C304, C305, C306, C307, C308, C309, C311, C312, C313, C314, C402, C404, C406, C407, C501, C502, C504, C505: 100n; C_0805_2012Metric
C5, C6, C18, C40, C41, C43, C48, C54, C405: 10n; C_0805_2012Metric
C10, C12, C19, C20, C29, C32, C42, C44, C47, C503: 1u; C_0805_2012Metric
C11, C51, C53: 22u; C_0805_2012Metric
C27, C28, C49, C50, C52: 10u; C_0805_2012Metric
C34, C35, C316: 2u2; C_0805_2012Metric
C45: 220n; C_0805_2012Metric
C209, C210, C223, C224: 4n7; C_0805_2012Metric
C211, C212, C225, C226: 470p; C_0805_2012Metric
C315: 100p; C_0805_2012Metric
C401: 680n; C_0805_2012Metric
D1, D4, D5, D6: PESD3V3L1BAF; D_SOD-323
D2, D3, D9, D10, D11, D12, D13, D14, D15, D301, D302: 1N4148; D_MiniMELF
D7, D8, D201, D202, D204, D205, D206, D207, D208, D209: TZMB16-GS08; D_MiniMELF
D203: 1.5KE100A (smd); D_SMC
F1: Fuse; Fuseholder_Cylinder-5x20mm_Schurter_0031_8201_Horizontal_Op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
H101, H102, H103, H104: MountingHole; MountingHole_3.2mm_M3_DIN965
HS102: Heatsink; LAM3K
J1: Temp Sensor PCB; JST_XH_B2B-XH-A_1x02_P2.50mm_Vertical
J2: SWEB8094AU-SW; SWEB-8094-AU
J3: Conn_02x06_Odd_Even; PinSocket_2x06_P2.54mm_Vertical_SMD
J4: Conn_02x08_Odd_Even; PinHeader_2x08_P2.54mm_Vertical
J5: SWEB8094AU-RT; SWEB-8094-AU
J7: Conn_01x02_Socket; PhoenixContact_MC_1,5_2-G-3.81_1x02_P3.81mm_Horizontal
J8: Conn_02x08_Odd_Even; PinSocket_2x08_P2.54mm_Vertical_SMD
J9: Temp Sensor heatsink; JST_XH_B2B-XH-A_1x02_P2.50mm_Vertical
JP305: Jumper_2_Open; SolderJumper-2_P1.3mm_Bridged_RoundedPad1.0x1.5mm
JP306: Jumper_2_Open; SolderJumper-2_P1.3mm_Bridged2Bar_RoundedPad1.0x1.5mm
K2: EE2-5TNU; Relay_DPDT_Kemet_EE2_NU_DoubleCoil
NT201, NT202: NetTie_2; NetTie-2_SMD_Pad0.5mm
OSHWLogo1: CERN-OHL-W-2.0; OSHW-Logo_7.5x8mm_SilkScreen
Q1, Q2, Q201, Q202, Q205, Q206, Q301: 2N7002; SOT-23
Q3, Q6: MMBT5551; SOT-23
Q4: MMBT3904; SOT-23
Q5, Q8: MMBT5401; SOT-23
Q7: AOSP66923; SO-8_3.9x4.9mm_P1.27mm
Q101: TIP42C; TO-220-3_Vertical
Q203, Q204, Q207, Q208: IRFP250M; TO-247-3_Vertical
R1, R16, R20, R50, R53, R54, R321: 100k; R_0805_2012Metric
R2: 1k5 (3W); R_Axial_DIN0516_L15.5mm_D5.0mm_P5.08mm_Vertical
R3, R6, R315: 5k 0.1%; R_0805_2012Metric
R4, R5, R26, R29, R30, R31, R211, R212, R213, R214, R231, R232, R233, R234, R309, R310, R311, R312, R313, R314: 100k 0.1%; R_0805_2012Metric
R7: 50k 0.1%; R_0805_2012Metric
R8, R21: 330; R_0805_2012Metric
R9, R10: 750; R_0805_2012Metric
R11, R12, R23, R24, R25, R45, R221, R222: 0; R_0805_2012Metric
R13, R14, R15, R17, R46, R55, R56, R57, R201, R202, R403, R502, R507, R509: 10k; R_0805_2012Metric
R18, R19: 470; R_0805_2012Metric
R22, R43: 47k; R_0805_2012Metric
R27, R28, R305, R306: 10k 0.1%; R_0805_2012Metric
R32, R33, R34, R35, R322, R401, R402: 1k; R_0805_2012Metric
R36, R37, R38: 47; R_0805_2012Metric
R39, R42, R58, R203, R205, R223, R225: 22k; R_0805_2012Metric
R40: 200; R_0805_2012Metric
R41: 1k8; R_0805_2012Metric
R44, R47, R48: 4k7; R_0805_2012Metric
R49, R51, R52, R209, R210, R229, R230: 1M; R_0805_2012Metric
R204, R206, R224, R226: 20k 0.1%; R_0805_2012Metric
R207, R208, R227, R228: 100; R_0805_2012Metric
R215, R216, R217, R218, R235, R236, R237, R238: 1k1 0.1%; R_0805_2012Metric
R219, R220, R239, R240: 10m; R_2512_6332Metric_Pad1.40x3.35mm_HandSolder
R301, R302, R303, R304, R325, R404, R405: 2k; R_0805_2012Metric
R307, R308: 1k 0.1%; R_0805_2012Metric
R317, R318: 39k 0.1%; R_0805_2012Metric
R320: 7k5; R_0805_2012Metric
R323, R503: 15k; R_0805_2012Metric
R324: 24k; R_0805_2012Metric
R330: 2k2; R_0805_2012Metric
R504: 220; R_0805_2012Metric
TP1: -5V; TestPoint_Loop_D1.80mm_Drill1.0mm_Beaded
TP2: +5V; TestPoint_Loop_D1.80mm_Drill1.0mm_Beaded
TP3: GND; TestPoint_Loop_D2.50mm_Drill1.0mm
TP4: Imon3; TestPoint_Pad_1.0x1.0mm
TP5: Imon1; TestPoint_Pad_1.0x1.0mm
TP6: Imon4; TestPoint_Pad_1.0x1.0mm
TP7: Imon2; TestPoint_Pad_1.0x1.0mm
TP8: Imon; TestPoint_Pad_1.0x1.0mm
TP9: -2V5; TestPoint_Pad_1.0x1.0mm
TP10: 3V; TestPoint_Pad_1.0x1.0mm
TP11: -1V; TestPoint_Pad_1.0x1.0mm
TP12: 2V5; TestPoint_Pad_1.0x1.0mm
TP13: Umon; TestPoint_Pad_1.0x1.0mm
TP14: loopSet; TestPoint_Pad_1.0x1.0mm
U1: SN74LVC1G3157DBV; SOT-23-6
U2, U306, U402: LM393A; SOIC-8_3.9x4.9mm_P1.27mm
U4: REF5025AD; SOIC-8_3.9x4.9mm_P1.27mm
U5: 24LC32; SO-8_3.9x4.9mm_P1.27mm
U8, U9: VO1400AEFTR; SO-4_4.4x4.3mm_P2.54mm
U10: TL072/OPA2376; SOIC-8_3.9x4.9mm_P1.27mm
U11, U12: DAC8555; TSSOP-16_4.4x5mm_P0.65mm
U15: TPS7A2030; SOT-23-5
U17: TPS72325; SOT-23-5
U18, U19: MCP6V51; SOT-23-5
U20: ADS131M02; TSSOP-20_4.4x6.5mm_P0.65mm
U21: LT1964-5; TSOT-23-5
U22: AMS1117; SOT-223-3_TabPin2
U23: TLV1117-50; SOT-223-3_TabPin2
U201, U202, U205, U206: LM318D; SOIC-8_3.9x4.9mm_P1.27mm
U203, U204, U207, U208: MCP6V51/LTC2050HV; SOT-23-5
U301, U302: LM833; SOIC-8_3.9x4.9mm_P1.27mm
U303, U304: OPA189/MCP6V51/LTC2050HV; SOT-23-5
U305, U403: 74HCT02; SO-14_3.9x8.65mm_P1.27mm
U401: AD8038; SOIC-8_3.9x4.9mm_P1.27mm
X3: DIB Pheriperal connector

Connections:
+3.0VA: C25.1, C26.1, C27.1, C28.1, C32.1, C36.1, C38.1, C42.1, TP10.1, U11.4 (AVDD), U12.4 (AVDD), U15.5 (OUT), U18.5 (V+), U19.5 (V+), U20.1 (AVDD)
+3.3V-DIB: C13.1, R13.1, R14.1, R15.1, U5.8 (VCC), X3.1 (+3V3)
+3.3VD: C23.1, C24.1, C44.1, J8.13, U11.12 (IOVDD), U11.13 (~RST), U12.12 (IOVDD), U12.13 (~RST), U20.11 (~SYNC/RST), U20.20 (DVDD)
+5V: C4.2, C10.1, C29.1, C51.1, C203.2, C207.2, C218.2, C221.2, C301.2, C303.2, C305.2, C307.2, C311.2, C312.2, C402.2, C404.2, C406.2, C501.1, D2.1 (K), D3.1 (K), K2.1, K2.6, Q8.2 (E), R22.2, R44.2, R47.2, R54.2, R56.2, R325.1, R404.2, R405.2, TP2.1, U1.5 (V+), U4.2 (Vin), U10.8 (V+), U15.1 (IN), U15.3 (EN), U23.2 (VO), U203.5 (V+), U204.5 (V+), U207.5 (V+), U208.5 (V+), U301.8 (V+), U302.8 (V+), U303.5 (V+), U304.5 (V+), U305.14 (VCC), U306.5 (+), U306.8 (V+), U401.7 (V+), U401.8 (~CS), U402.8 (V+), U403.14 (VCC)
+5V-DIB: X3.23 (+5V), X3.24 (+5V)
+6V: C50.1, J4.4, J4.6, U23.3 (VI)
+12V: C7.2, C53.1, C201.2, C205.2, C215.2, C219.2, R40.1, R46.2, U2.8 (V+), U22.2 (VO), U201.7 (V+), U202.7 (V+), U205.7 (V+), U206.7 (V+)
+12V-DIB: J3.1, J3.2, X3.21 (+12V), X3.22 (+12V)
+15V: C52.1, J4.10, U22.3 (VI)
-1V: R320.2, R509.2, TP11.1, U10.7
-2V5: C35.2, C37.2, C39.2, TP9.1, U17.5 (OUT), U18.2 (V-), U19.2 (V-)
-5V: C7.1, C34.2, C49.2, C202.1, C204.1, C206.1, C208.1, C216.1, C217.1, C220.1, C222.1, C302.1, C304.1, C306.1, C308.1, C313.1, C407.1, C502.2, TP1.1, U2.4 (V-), U10.4 (V-), U17.2 (IN), U17.3 (EN), U21.5 (VOUT), U201.4 (V-), U202.4 (V-), U203.2 (V-), U204.2 (V-), U205.4 (V-), U206.4 (V-), U207.2 (V-), U208.2 (V-), U301.4 (V-), U302.4 (V-), U303.2 (V-), U304.2 (V-), U306.4 (V-), U401.4 (V-)
-6V: C47.2, J4.12, J4.14, U21.2 (VIN), U21.4 (~SHDN)
/CV, OVP & OCP/ReverseProt: D7.1 (K), Q7.4 (G), R46.1, U2.7
/DIB connection/DIB_A0: R13.2, U5.1 (A0), X3.17 (A0)
/DIB connection/DIB_A1: R14.2, U5.2 (A1), X3.19 (A1)
/DIB connection/DIB_A2: R15.2, U5.3 (A2), X3.18 (A2)
/DIB connection/DIB_CSA: J3.10, X3.9 (CSA)
/DIB connection/DIB_CSB: J3.7, X3.12 (CSB)
/DIB connection/DIB_IRQ: J3.9, X3.10 (IRQ)
/DIB connection/DIB_MISO: J3.5, X3.14 (MISO)
/DIB connection/DIB_MOSI: J3.6, X3.15 (MOSI)
/DIB connection/DIB_SCL: U5.6 (SCL), X3.5 (SSCL)
/DIB connection/DIB_SCLK: J3.8, X3.13 (SCLK)
/DIB connection/DIB_SDA: U5.5 (SDA), X3.8 (SSDA)
/DIB connection/DIB_SYNC: J3.12, X3.6 (SYNC)
/DIB connection/DIB_~RESET: J3.11, X3.4 (~RESET)
/MOSFET Loops/LoopImon: R204.2, R206.2, R224.2, R226.2, R315.1, U304.3 (+)
/MOSFET Loops/LoopIset: C315.2, D15.2 (A), JP305.1 (A), JP306.2 (B), R201.1, R202.1, R221.1, R222.1, R304.1, TP14.1, U301.2 (-), U301.6 (-), U302.2 (-)
/Monitoring, Crossover, Von/scaledUmon: C310.2, R1.2, R321.2, U306.3 (+)
ADC_CLK: J8.9, R36.2
ADC_CS: J8.6, U20.12 (~CS)
ADC_RDY: J8.5, R37.2
CVsetOut: C401.2, R302.2, U401.6
ClampOff: D15.1 (K), J8.3, Q201.1 (G), Q202.1 (G), Q205.1 (G), Q206.1 (G), U403.9, U403.13
CurrRangeLow: J8.14, U1.6
DAC1_CS: J8.12, U11.9 (~SYNC)
DAC2_CS: J8.15, U12.9 (~SYNC)
GCOM: R11.2, R33.1, R35.1, R211.2, R213.2, R231.2, R233.2, R305.2, R315.2, U10.1, U10.2 (-)
GND: C1.2, C2.2, C4.1, C10.2, C11.2, C12.2, C18.1, C19.2, C20.2, C21.2, C22.2, C23.2, C24.2, C25.2, C26.2, C27.2, C28.2, C29.2, C32.2, C34.1, C35.1, C36.2, C37.1, C38.2, C39.1, C42.2, C43.2, C44.2, C45.2, C47.1, C48.1, C49.1, C50.2, C51.2, C52.2, C53.2, C54.2, C201.1, C202.2, C203.1, C204.2, C205.1, C206.2, C207.1, C208.2, C209.1, C210.1, C215.1, C216.2, C217.2, C218.1, C219.1, C220.2, C221.1, C222.2, C223.1, C224.1, C301.1, C302.2, C303.1, C304.2, C305.1, C306.2, C307.1, C308.2, C310.1, C311.1, C312.1, C313.2, C314.1, C316.1, C402.1, C404.1, C405.1, C406.1, C407.2, C501.2, C502.1, C503.2, C504.2, C505.2, D1.2 (A2), D4.1 (A1), D5.1 (A1), D6.1 (A1), D11.1 (K), D12.1 (K), D13.1 (K), D14.1 (K), J2.MP (MountPin), J4.1, J4.2, J4.15, J4.16, J8.11, Q1.2 (S), Q2.2 (S), Q6.2 (E), R1.1, R16.1, R20.1, R23.2, R25.1, R30.2, R31.2, R41.2, R43.1, R45.2, R57.1, R209.2, R210.2, R229.2, R230.2, R323.2, R504.2, TP3.1, U1.2 (GND), U4.4 (GND), U8.2, U9.2, U10.5 (+), U11.5 (VREFL), U11.6 (GND), U11.14 (RSTSEL), U11.15 (~ENABLE), U11.16 (LDAC), U12.5 (VREFL), U12.6 (GND), U12.14 (RSTSEL), U12.15 (~ENABLE), U12.16 (LDAC), U15.2 (GND), U17.1 (GND), U20.2 (AGND), U20.19 (DGND), U21.1 (GND), U23.1 (GND), U305.2, U305.3, U305.7 (GND), U306.6 (-), U402.4 (V-), U403.7 (GND)
GND-DIB: C13.2, J3.3, J3.4, U5.4 (GND), U5.7 (WP), X3.7 (GND), X3.11 (GND), X3.16 (GND), X3.20 (GND), X3.25 (GND)
HWProtEnable: J4.5, U403.3
Imon: R3.2, R4.2, R5.2, R7.2, R27.1, R403.1, TP8.1, U304.1
Iset: R303.2, U11.1 (VOUTA)
LoadMin: D8.1 (K), D203.2 (A2), Q7.1 (S), Q7.2 (S), Q7.3 (S), R2.1, R25.2, R216.1, R218.1, R219.2, R220.2, R236.1, R238.1, R239.2, R240.2
LoadMinDirect: C6.1, J2.1, NT202.2, Q3.2 (E), Q7.5 (D), Q7.6 (D), Q7.7 (D), Q7.8 (D), R21.1, R23.1, R53.2
LoadMinMon: K2.10, NT202.1
LoadMinSense: J7.2, K2.8, R10.2
LoadPlus: C3.1, C5.2, D203.1 (A1), F1.2, Q5.2 (E), Q203.2 (D), Q204.2 (D), Q207.2 (D), Q208.2 (D), R8.2
LoadPlusMon: K2.3, NT201.1
LoadPlusSense: J7.1, K2.5, R9.1
LoadPlusUnfused: F1.1, J5.1, NT201.2, R49.1
unnamed: C3.2, R2.2
unnamed: C213.2, R207.1, U201.6
unnamed: C214.2, R208.1, U202.6
unnamed: C227.2, R227.1, U205.6
unnamed: C228.2, R228.1, U206.6
unnamed: C315.1, R304.2, U301.7
unnamed: C316.2, R325.2, R330.2, U305.5, U305.8
unnamed: D1.1 (A1), R307.2, R309.1, U8.3
unnamed: D2.2 (A), K2.12, Q1.3 (D)
unnamed: D3.2 (A), K2.7, Q2.3 (D)
unnamed: D4.2 (A2), R50.2, R52.2, U2.3 (+)
unnamed: D5.2 (A2), R50.1, R53.1, U2.2 (-)
unnamed: D6.2 (A2), R308.1, R310.2, U9.4
unnamed: D7.2 (A), D8.2 (A)
unnamed: D9.1 (K), R48.1, U2.1
unnamed: D9.2 (A), D10.2 (A), R54.1, U2.5 (+)
unnamed: D10.1 (K), R55.2
unnamed: D11.2 (A), Q201.2 (S)
unnamed: D12.2 (A), Q202.2 (S)
unnamed: D13.2 (A), Q205.2 (S)
unnamed: D14.2 (A), Q206.2 (S)
unnamed: D201.2 (A), D206.2 (A)
unnamed: D201.1 (K), Q201.3 (D), Q203.1 (G), R207.2, R209.1
unnamed: D202.2 (A), D207.2 (A)
unnamed: D202.1 (K), Q202.3 (D), Q204.1 (G), R208.2, R210.1
unnamed: D204.2 (A), D208.2 (A)
unnamed: D204.1 (K), Q205.3 (D), Q207.1 (G), R227.2, R229.1
unnamed: D205.2 (A), D209.2 (A)
unnamed: D205.1 (K), Q206.3 (D), Q208.1 (G), R228.2, R230.1
unnamed: C211.2, D206.1 (K), Q203.3 (S), R215.2, R219.1
unnamed: C212.2, D207.1 (K), Q204.3 (S), R217.2, R220.1
unnamed: C225.2, D208.1 (K), Q207.3 (S), R235.2, R239.1
unnamed: C226.2, D209.1 (K), Q208.3 (S), R237.2, R240.1
unnamed: D301.2 (A), JP305.2 (B)
unnamed: D301.1 (K), U301.1
unnamed: D302.2 (A), JP306.1 (A)
unnamed: D302.1 (K), U302.1
unnamed: J1.1, Q4.1 (B), Q4.2 (E)
unnamed: J1.2, Q4.3 (C)
unnamed: J9.1, Q101.1 (B), Q101.2 (C)
unnamed: J9.2, Q101.3 (E)
unnamed: K2.4, R317.2
unnamed: K2.9, R318.1
unnamed: C6.2, Q3.1 (B), R10.1, R21.2
unnamed: Q3.3 (C), R39.1
unnamed: C5.1, Q5.1 (B), R8.1, R9.2
unnamed: Q5.3 (C), R42.2
unnamed: Q6.1 (B), R42.1, R43.2, R58.1
unnamed: Q8.1 (B), R22.1, R39.2
unnamed: Q8.3 (C), R58.2
unnamed: C309.2, Q301.2 (S), R320.1, U302.6 (-)
unnamed: R3.1, U1.3
unnamed: R4.1, R5.1, U1.1
unnamed: R11.1, R12.2
unnamed: R12.1, R24.2
unnamed: R18.1, U8.1
unnamed: R19.1, U9.1
unnamed: R6.1, R24.1
unnamed: R26.2, R28.2
unnamed: R27.2, R29.2
unnamed: R49.2, R51.1
unnamed: R51.2, R52.1
unnamed: R203.2, R204.1, R212.2, TP5.1, U203.1
unnamed: R205.2, R206.1, R214.2, TP4.1, U204.1
unnamed: R223.2, R224.1, R232.2, TP7.1, U207.1
unnamed: R225.2, R226.1, R234.2, TP6.1, U208.1
unnamed: R309.2, R311.1
unnamed: R310.1, R312.2
unnamed: R311.2, R313.1
unnamed: R312.1, R314.2
unnamed: R313.2, R317.1, U8.4
unnamed: R314.1, R318.2, U9.3
unnamed: R503.2, R507.1
unnamed: R56.1, R57.2, U2.6 (-)
unnamed: C503.1, U4.5 (Trim/NR)
unnamed: C504.1, R502.2, R504.1, U10.3 (+)
unnamed: C505.1, R507.2, R509.1, U10.6 (-)
unnamed: C43.1, U17.4 (NR)
unnamed: R29.1, R31.1, U18.3 (+)
unnamed: R32.1, U18.1, U18.4 (-)
unnamed: R28.1, R30.1, U19.3 (+)
unnamed: R34.1, U19.1, U19.4 (-)
unnamed: C40.2, R33.2, U20.4 (AIN0N)
unnamed: C40.1, R32.2, U20.3 (AIN0P)
unnamed: C41.2, R35.2, U20.5 (AIN1N)
unnamed: C41.1, R34.2, U20.6 (AIN1P)
unnamed: C45.1, U20.18 (CAP)
unnamed: R36.1, U20.17 (CLKIN)
unnamed: R38.1, U20.15 (DOUT)
unnamed: R37.1, U20.13 (~DRDY)
unnamed: C48.2, U21.3 (BYP)
unnamed: C54.1, R40.2, R41.1, U22.1 (ADJ)
unnamed: C209.2, R201.2, U201.3 (+)
unnamed: C211.1, C213.1, R203.1, U201.2 (-)
unnamed: C210.2, R202.2, U202.3 (+)
unnamed: C212.1, C214.1, R205.1, U202.2 (-)
unnamed: R211.1, R215.1, U203.3 (+)
unnamed: R212.1, R216.2, U203.4 (-)
unnamed: R213.1, R217.1, U204.3 (+)
unnamed: R214.1, R218.2, U204.4 (-)
unnamed: C223.2, R221.2, U205.3 (+)
unnamed: C225.1, C227.1, R223.1, U205.2 (-)
unnamed: C224.2, R222.2, U206.3 (+)
unnamed: C226.1, C228.1, R225.1, U206.2 (-)
unnamed: R231.1, R235.1, U207.3 (+)
unnamed: R232.1, R236.2, U207.4 (-)
unnamed: R233.1, R237.1, U208.3 (+)
unnamed: R234.1, R238.2, U208.4 (-)
unnamed: C1.1, R302.1, U301.3 (+)
unnamed: C2.1, R303.1, U301.5 (+)
unnamed: R301.1, U302.3 (+)
unnamed: R45.1, U302.5 (+)
unnamed: R305.1, R307.1, U303.3 (+)
unnamed: R306.1, R308.2, U303.4 (-)
unnamed: R6.2, R7.1, U1.4, U304.4 (-)
unnamed: U305.10, U305.11
unnamed: U305.6, U305.9, U305.13
unnamed: C314.2, R322.2, R323.1, R324.2, U306.2 (-)
unnamed: R401.2, U401.3 (+)
unnamed: C401.1, R402.2, U401.2 (-)
unnamed: C18.2, R17.2, U402.3 (+)
unnamed: C405.2, R403.2, U402.5 (+)
unnamed: U403.1, U403.8
unnamed: U403.2, U403.4
unnamed: U403.10, U403.11
OCPset: U11.7 (VOUTC), U402.6 (-)
OCPtriggered: J8.2, R405.1, U402.7, U403.6
OVPset: U11.8 (VOUTD), U402.2 (-)
OVPtriggered: J8.4, R404.1, U402.1, U403.5
ReversePolarity: J4.8, R47.1, R48.2
SPI0_RX: J8.10, R38.2
SPI0_SCK: J8.8, U11.10 (SCLK), U12.10 (SCLK), U20.14 (SCLK)
SPI0_TX: J8.7, U11.11 (DIN), U12.11 (DIN), U20.16 (DIN)
SenseError: J4.9, Q6.3 (C), R44.1
Umon: R17.1, R26.1, R306.2, R321.1, R401.1, TP13.1, U303.1
Uset: R402.1, U12.1 (VOUTA)
VoltRangeLow: J4.11, R18.2, R19.2
VonComp: R324.1, R330.1, U306.1
VonOut: C309.1, Q301.3 (D), R301.2, U302.7
Vonset: R322.1, U11.2 (VOUTB)
Vref: C11.1, C12.1, C19.1, C20.1, C21.1, C22.1, R502.1, R503.1, TP12.1, U4.6 (Vout), U11.3 (VREFH), U12.3 (VREFH)
VsenseClear: J4.3, Q2.1 (G), R20.2
VsenseSet: J4.7, Q1.1 (G), R16.2
resetProt: J8.1, U403.12
~VonLatch: J4.13, U305.12
~Von: J8.16, Q301.1 (G), R55.1, U305.4

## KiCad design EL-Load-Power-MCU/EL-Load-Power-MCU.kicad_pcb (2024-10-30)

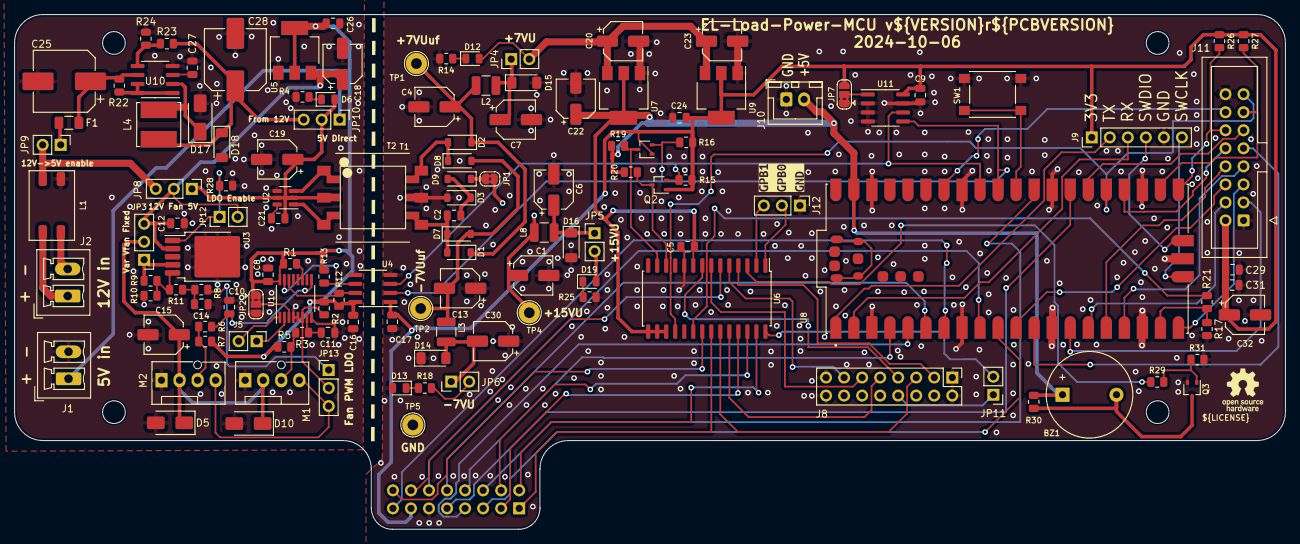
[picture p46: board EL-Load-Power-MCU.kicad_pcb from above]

Board: 4 copper layers, 179.0 x 72.5 mm, 137 parts (1 on the bottom side), 108 nets.

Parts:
BZ1: Buzzer; Buzzer_12x9.5RM7.6
C1, C4, C6, C7, C13, C15, C18, C19, C20, C22, C23, C30, C32: 10u; CP_Elec_5x5.8
C2, C14, C29: 1u; C_0805_2012Metric
C5, C8, C9, C10, C11, C16, C17, C21, C31: 100n; C_0805_2012Metric
C12: 2.2u; C_0805_2012Metric
C24, C26: 10u; C_0805_2012Metric
C25, C28: 100u; CP_Elec_8x10.5
C27: 200p; C_0805_2012Metric
D1, D2, D3, D7, D8, D9: MBR0530; D_SOD-123
D5, D10, D17: SS14; D_SMA
D6, D12, D13, D19: LED; LED_0805_2012Metric
D14, D15: 16V; D_MiniMELF
D16: 20V; D_MiniMELF
D18: BZV55B5V6; D_MiniMELF
F1: 1A; Fuse_1206_3216Metric
H1, H2, H3, H4: MountingHole; MountingHole_3.2mm_M3_ISO14580
J1, J2: Conn_01x02; PhoenixContact_MCV_1,5_2-G-3.81_1x02_P3.81mm_Vertical
J5: PN sensor; PinHeader_1x02_P2.54mm_Vertical
J7, J8: PinHeader 2x08 P2.54mm; PinHeader_2x08_P2.54mm_Vertical
J9: SWD+UART header; PinHeader_1x06_P2.54mm_Vertical
J10: Power for serial interface; JST_XH_B2B-XH-A_1x02_P2.50mm_Vertical
J11: IDC-Header 2x08 P2.54mm; IDC-Header_2x08_P2.54mm_Vertical
J12: Conn_01x05_Pin; PinHeader_1x03_P2.54mm_Vertical
JP1: SolderJumper_2_Bridged; SolderJumper-2_P1.3mm_Bridged2Bar_RoundedPad1.0x1.5mm
JP2: I2C Address; SolderJumper-3_P1.3mm_Bridged2Bar12_RoundedPad1.0x1.5mm
JP3: Fan Volt/PWM; PinHeader_1x03_P2.54mm_Vertical
JP4, JP5, JP6, JP9: Jumper_2_Bridged; PinHeader_1x02_P2.54mm_Vertical
JP7: Jumper_3_Bridged12; SolderJumper-3_P1.3mm_Bridged2Bar12_RoundedPad1.0x1.5mm
JP8: Select Fan Voltage; PinHeader_1x03_P2.54mm_Vertical
JP10: Select 5V source; PinHeader_1x03_P2.54mm_Vertical
JP11: HW V3/V4; PinHeader_1x02_P2.54mm_Vertical
JP12: LDO En; PinHeader_1x02_P2.54mm_Vertical
JP13: PWM 2 LDO/PWM; PinHeader_1x03_P2.54mm_Vertical
L1: SRF0905-202Y; L_Bourns_SRF1260
L2, L3, L8: 10u; L_1210_3225Metric
L4: 100u / 300mA; L_Bourns_SRN6045TA
M1, M2: Fan_4pin; FanPinHeader_1x04_P2.54mm_Vertical
PCB1: Logo_Open_Hardware_Small; OSHW-Logo_5.7x6mm_SilkScreen
Q1, Q2, Q3: BSS138W; SOT-323_SC-70
R1, R2: 4k7; R_0805_2012Metric
R3, R6: 10; R_0805_2012Metric
R4, R14, R18, R21, R23, R28: 10k; R_0805_2012Metric
R5, R7, R8, R29, R30: 1k; R_0805_2012Metric
R9: 39k; R_0805_2012Metric
R10, R11, R24: 3k3; R_0805_2012Metric
R12, R13, R15, R16, R19, R20, R26, R27: 3k; R_0805_2012Metric
R17, R25, R31: 20k; R_0805_2012Metric
R22: 0.3; R_0805_2012Metric
SW1: Pico Reset; SW_Push_1P1T_NO_6x6mm_H9.5mm
T1: Wuerth_750315371; L_Wuerth_750315371
T2: Wuerth_750316031; L_Wuerth_750316031
TP1, TP2, TP4, TP5: TestPoint_Probe; TestPoint_Loop_D2.54mm_Drill1.5mm_Beaded
U1: MAX31760; QSOP-16_3.9x4.9mm_P0.635mm
U2: SN6505BDBV; SOT-23-6
U3: BD00FC0WFP-E2; TO-252-5_TabPin6
U4: Si8602AB; SOIC-8_3.9x4.9mm_P1.27mm
U5, U9: AMS1117-3.3; SOT-223-3_TabPin2
U6: MCP23017_SO; SOIC-28W_7.5x17.9mm_P1.27mm
U7: AZ1117-5.0; SOT-223-3_TabPin2
U8: SC0915; MODULE_SC0915
U10: MC34063AD; SOIC-8_3.9x4.9mm_P1.27mm
U11: 24C64; SOIC-8_3.9x4.9mm_P1.27mm
kibuzzard-66FFF99B: G***; kibuzzard-66FFF99B

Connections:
+3V3: C9.1, C17.2, C24.2, C29.1, C31.2, C32.1, J7.13, J9.1, J11.2, JP7.3 (B), Q1.1 (G), Q2.1 (G), R15.1, R16.1, R26.1, R27.1, U4.1 (AVDD), U9.2 (VO), U11.8 (VCC)
+3V3_ISO: C8.1, C16.2, C26.2, JP2.1 (A), R1.2, R2.1, R5.1, R7.1, R12.1, R13.1, U1.16 (VDD), U4.8 (BVDD), U5.2 (VO)
+5VD: BZ1.1 (-), C5.2, C22.1, J10.2, R19.1, R20.1, R30.1, U6.9 (VDD), U6.15 (A0), U6.16 (A1), U6.17 (A2), U7.2 (VO), U8.39 (VSYS)
+5V_ISO: C19.1, C21.2, D6.2 (A), JP8.1 (A), JP10.2 (C), T1.2 (N2-A), T2.2 (N2-A), U2.2 (VCC), U2.5 (EN)
+7VU: C20.1, C23.1, D12.2 (A), J8.4, J8.6, JP4.2 (B), U7.3 (VI), U9.3 (VI)
+12V_ISO: JP8.3 (B), JP9.2 (B), L1.3
+15VU: D19.2 (A), J8.10, JP5.2 (B)
+V_FANS: C12.1, C18.1, JP3.3 (B), JP8.2 (C), JP12.2 (B), U3.2 (Vcc), U5.3 (VI)
-7VU: J8.12, J8.14, JP6.2 (B), R18.2
/BLK: J11.7, U8.17 (GP13)
/CS1: J11.9, U8.12 (GP9)
/CS2: J11.10, U8.24 (GP18)
/DC: J11.6, U8.11 (GP8)
/Fan Controllers/Fan1PWM: JP13.3 (B), M1.4 (PWM), M2.4 (PWM)
/Fan Controllers/Fan1PWR: C15.1, D5.1 (K), D10.1 (K), JP3.2 (C), M1.2 (+), M2.2 (+)
/Fan Controllers/Fan1Tacho: M1.3 (Tacho), R3.2, R5.2
/Fan Controllers/Fan2Tacho: M2.3 (Tacho), R6.2, R7.2
/Fan Controllers/SCL_ISO: R13.2, U1.15 (SCL), U4.6 (BSCL)
/Fan Controllers/SDA_ISO: R12.2, U1.14 (SDA), U4.7 (BSDA)
/INT: J11.14, U8.34 (GP28)
/MCU/Buzzer: R29.1, U6.3 (GPB2)
/MCU/EL-ADC_CLK: J7.9, U8.27 (GP21)
/MCU/EL-ADC_CS: J7.6, U8.29 (GP22)
/MCU/EL-ADC_RDY: J7.5, U8.10 (GP7)
/MCU/EL-DAC1_CS: J7.12, U8.9 (GP6)
/MCU/EL-DAC2_CS: J7.15, U8.7 (GP5)
/MCU/EL-SPI_RX: J7.10, U8.6 (GP4)
/MCU/EL-SPI_SCK: J7.8, U8.4 (GP2)
/MCU/EL-SPI_TX: J7.7, U8.5 (GP3)
/MCU/HWGPIO_INT: R17.1, R21.2, U8.19 (GP14)
/MCU/HWIO_SCL: Q2.2 (S), R15.2, U4.3 (ASCL), U8.32 (GP27), U11.6 (SCL)
/MCU/HWIO_SDA: Q1.2 (S), R16.2, U4.2 (ASDA), U8.31 (GP26), U11.5 (SDA)
/MCU/HWProtEnable: J8.5, U6.23 (GPA2)
/MCU/OCPtriggered: J7.2, U6.27 (GPA6)
/MCU/OVPtriggered: J7.4, U6.26 (GPA5)
/MCU/RX: J9.3, U8.2 (GP1)
/MCU/TX: J9.2, U8.1 (GP0)
/MCU/VoltSenseClear: J8.3, U6.4 (GPB3)
/MCU/VoltSenseSet: J8.7, U6.8 (GPB7)
/MCU/clampOff: J7.3, U6.25 (GPA4)
/MCU/currRangeLow: J7.14, U6.6 (GPB5)
/MCU/resetProt: J7.1, U6.22 (GPA1)
/MCU/reversePolarity: JP11.2 (B), U6.28 (GPA7)
/MCU/senseError: J8.9, U6.24 (GPA3)
/MCU/voltRangeLow: J8.11, U6.7 (GPB6)
/MCU/~VonLatch: J8.13, U6.5 (GPB4)
/MCU/~Von: J7.16, U6.21 (GPA0)
/MISO: J11.8, U8.16 (GP12)
/MOSI: J11.4, U8.15 (GP11)
/PEN: J11.11, U8.26 (GP20)
/RESET: J11.5, U8.20 (GP15)
/SCLK: J11.3, U8.14 (GP10)
/Standalone Power/5Vout: C28.1, D18.1 (K), JP10.3 (B), L4.2, R23.1
/Standalone Power/12Vin: F1.1, JP9.1 (A)
/_KEYS_SCL: J11.13, R27.2, U8.22 (GP17)
/_KEYS_SDA: J11.12, R26.2, U8.21 (GP16)
/_reversePolarity: J8.8, JP11.1 (A)
/~RESET: J11.15, U6.18 (~RESET), U8.25 (GP19)
GND: C1.2, C4.2, C5.1, C6.2, C7.2, C9.2, C13.1, C17.1, C20.2, C22.2, C23.2, C24.1, C29.2, C30.1, C31.1, C32.2, D3.2 (A), D13.2 (A), D14.1 (K), D15.2 (A), D16.2 (A), J7.11, J8.1, J8.2, J8.15, J8.16, J9.5, J10.1, J11.1, J11.16, J12.1, JP7.1 (A), Q3.2 (S), R14.2, R17.2, R25.2, R31.2, SW1.2, T1.5 (N4-A), T2.5 (N4-A), TP5.1, U4.4 (AGND), U6.10 (VSS), U7.1 (GND), U8.3 (GND), U8.8 (GND), U8.13 (GND), U8.18 (GND), U8.23 (GND), U8.28 (GND), U8.33 (AGND), U8.38 (GND), U8.D2 (GND), U9.1 (GND), U11.2 (A1), U11.3 (A2), U11.4 (GND), U11.7 (WP)
GND_ISO: C8.2, C10.2, C11.2, C12.2, C14.2, C15.2, C16.1, C18.2, C19.2, C25.2, C26.1, C27.2, C28.2, D5.2 (A), D10.2 (A), D17.2 (A), D18.2 (A), J1.2, JP2.3 (B), L1.4, M1.1 (-), M2.1 (-), R4.2, R10.2, R24.2, R28.1, U1.4 (A1), U1.5 (A2), U1.8 (GND), U2.4 (GND), U3.6 (GND), U4.5 (BGND), U5.1 (GND), U10.4 (GND)
unnamed: BZ1.2 (+), Q3.3 (D), R30.2
unnamed: C14.1, R8.2, R11.2
unnamed: C2.2, D1.2 (A), D7.1 (K), T1.4 (N4-B), T2.4 (N4-B)
unnamed: C4.1, D1.1 (K), D2.1 (K), L2.2, TP1.1
unnamed: D2.2 (A), D8.1 (K), T1.6 (N3-A), T2.6 (N3-A)
unnamed: C2.1, D3.1 (K), D9.2 (A)
unnamed: D6.1 (K), R4.1
unnamed: C13.2, D7.2 (A), D8.2 (A), L3.2, TP2.1
unnamed: D9.1 (K), JP1.1 (A)
unnamed: D12.1 (K), R14.1
unnamed: D13.1 (K), R18.1
unnamed: C30.2, D14.2 (A), JP6.1 (A), L3.1
unnamed: C7.1, D15.1 (K), JP4.1 (A), L2.1
unnamed: C6.1, D16.1 (K), JP5.1 (A), L8.1
unnamed: D17.1 (K), L4.1, U10.2 (SwE)
unnamed: D19.1 (K), R25.1
unnamed: J1.1, JP10.1 (A)
unnamed: J2.1, L1.2
unnamed: J2.2, L1.1
unnamed: J5.1, U1.2 (DXN)
unnamed: J5.2, U1.1 (DXP)
unnamed: J9.4, U8.D3 (SWDIO)
unnamed: J9.6, U8.D1 (SWCLK)
unnamed: J12.2, U6.1 (GPB0)
unnamed: J12.3, U6.2 (GPB1)
unnamed: C1.1, JP1.2 (B), L8.2, TP4.1
unnamed: JP2.2 (C), U1.3 (A0)
unnamed: JP3.1 (A), R9.1, U3.4 (VOUT)
unnamed: JP7.2 (C), U11.1 (A0)
unnamed: JP12.1 (A), R28.2, U3.1 (EN)
unnamed: JP13.1 (A), R8.1
unnamed: JP13.2 (C), R2.2, U1.6 (PWM)
unnamed: Q1.3 (D), R19.2, U6.13 (SDA)
unnamed: Q2.3 (D), R20.2, U6.12 (SCK)
unnamed: Q3.1 (G), R29.2, R31.1
unnamed: T1.1 (N1-A), T2.1 (N1-A), U2.3 (D2)
unnamed: T1.3 (N2-B), T2.3 (N2-B), U2.1 (D1)
unnamed: C11.1, R3.1, U1.7 (TACH1)
unnamed: C10.1, R6.1, U1.9 (TACH2)
unnamed: R1.1, U1.11 (~SHDN)
unnamed: C21.1, U2.6 (CLK)
unnamed: R9.2, R10.1, R11.1, U3.5 (FB)
unnamed: R21.1, U6.20 (INTA)
unnamed: SW1.1, U8.30 (~RUN)
unnamed: R22.2, U10.1 (SwC), U10.7 (Ipk), U10.8 (DC)
unnamed: C27.1, U10.3 (TC)
unnamed: R23.2, R24.1, U10.5 (Vfb)
unnamed: C25.1, F1.2, R22.1, U10.6 (Vin)

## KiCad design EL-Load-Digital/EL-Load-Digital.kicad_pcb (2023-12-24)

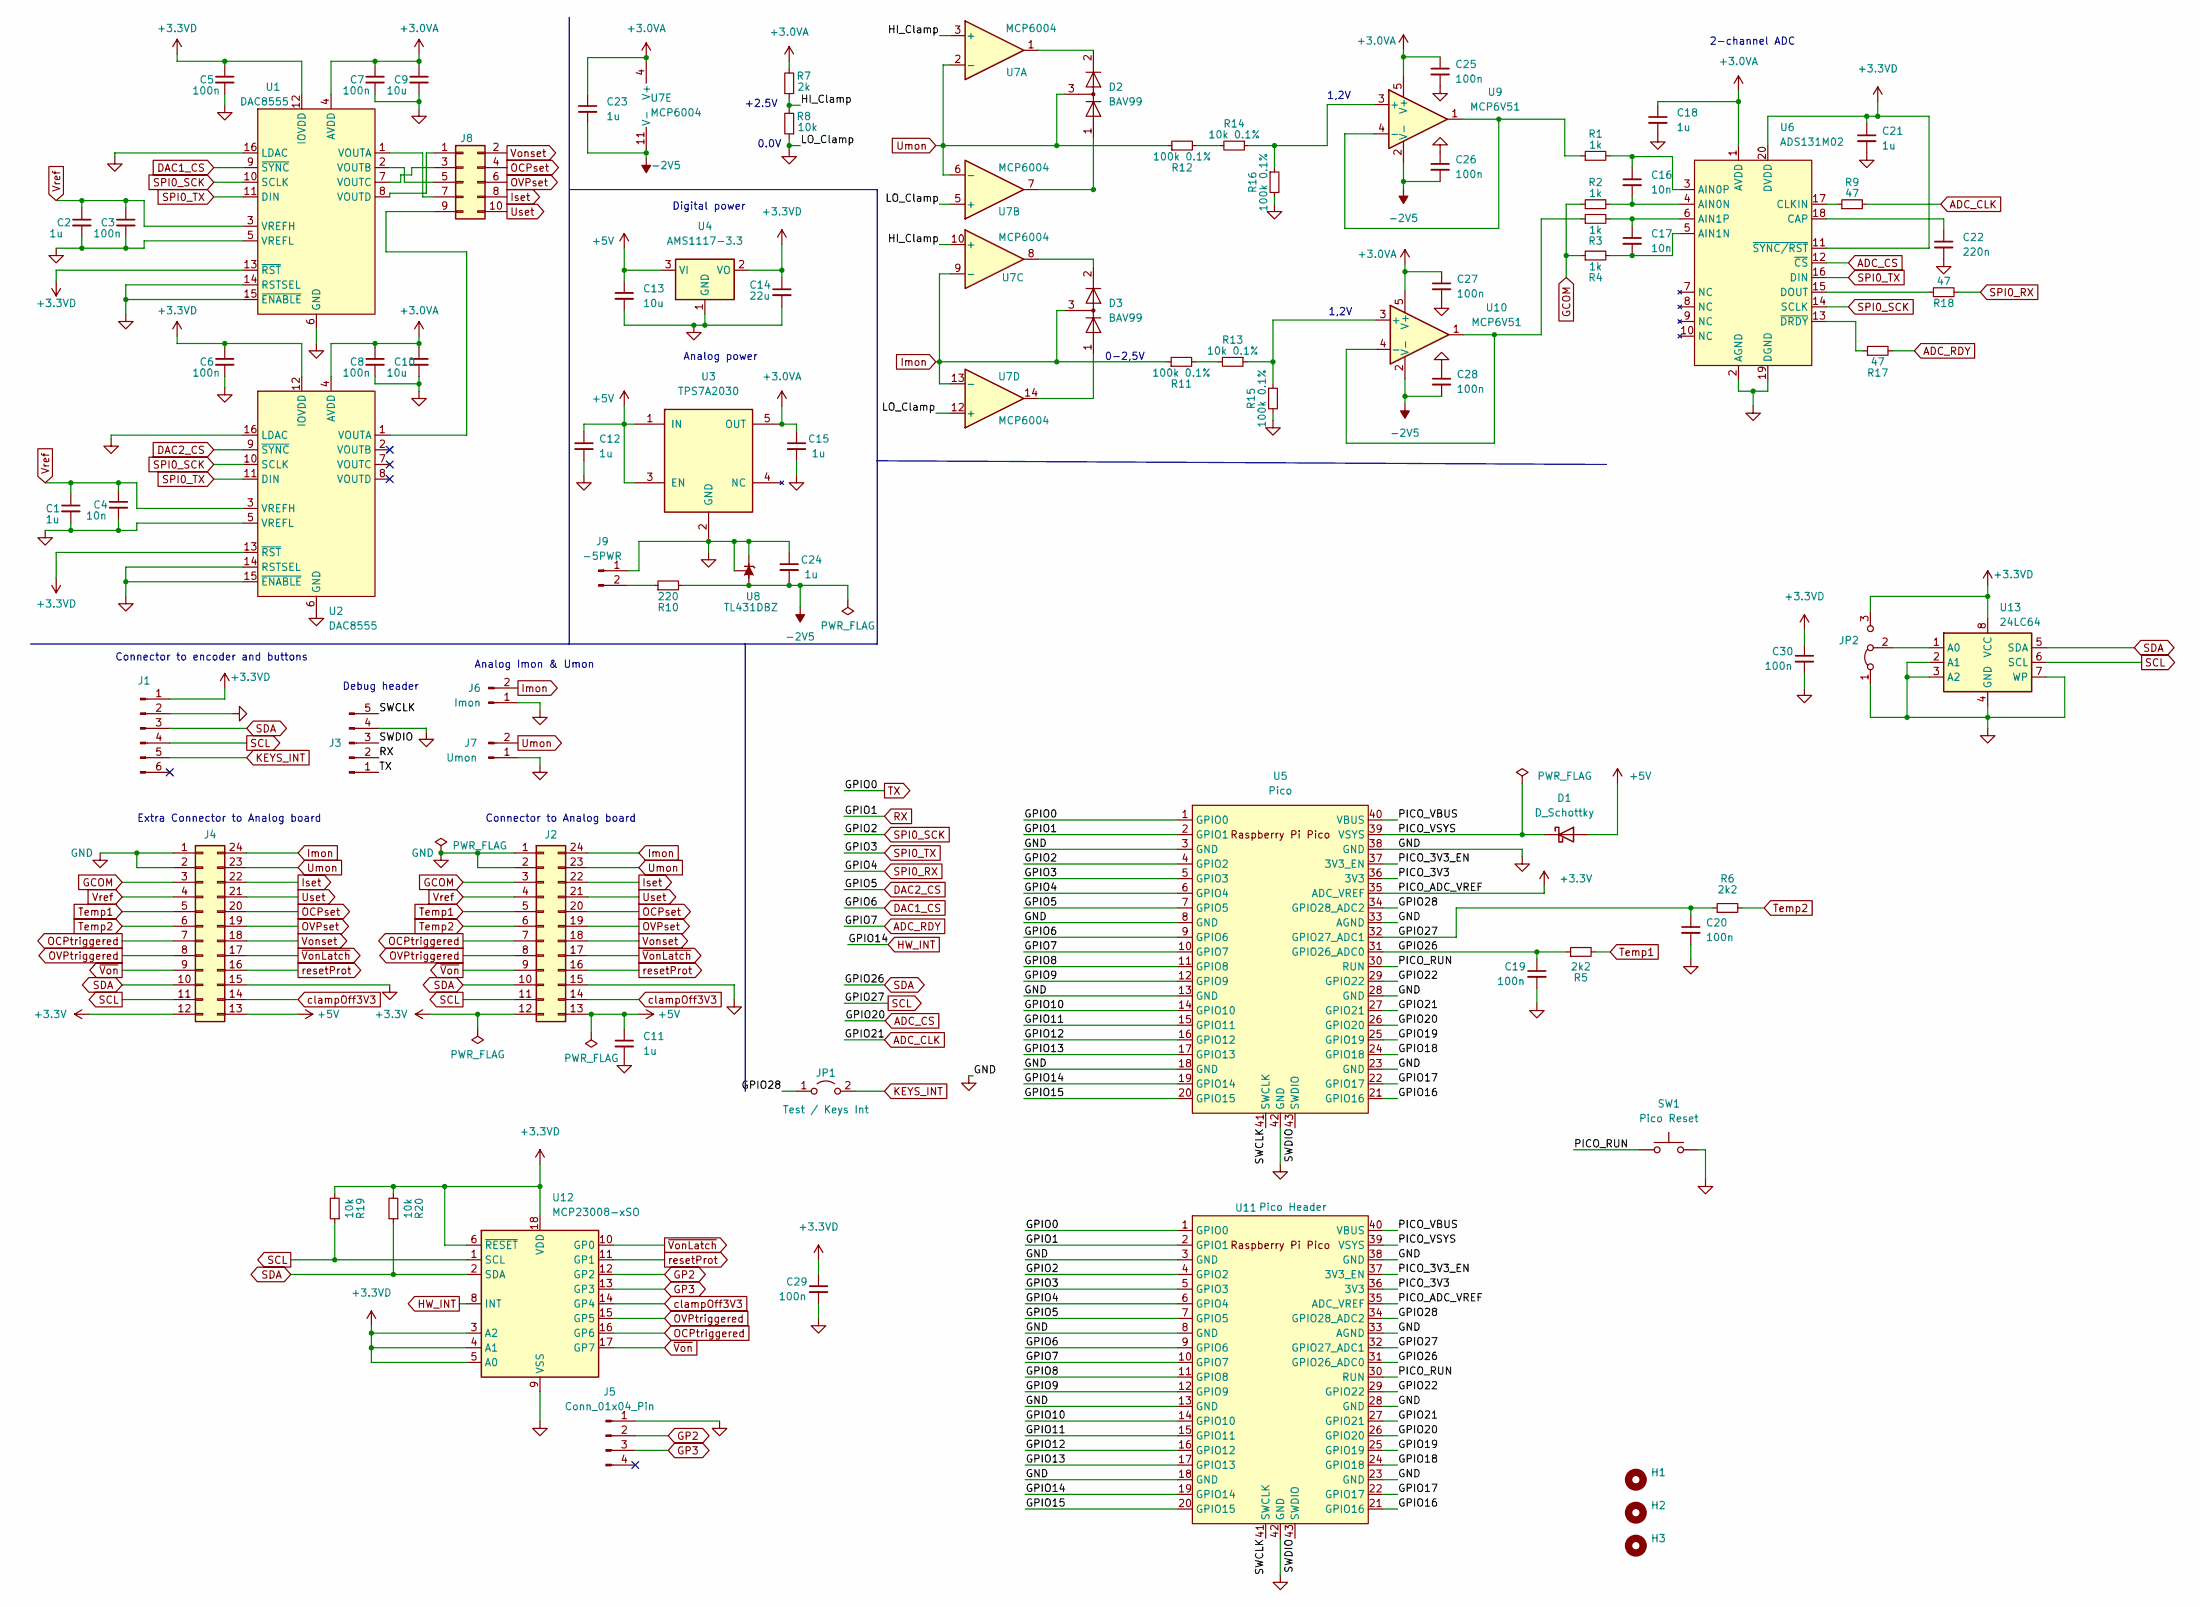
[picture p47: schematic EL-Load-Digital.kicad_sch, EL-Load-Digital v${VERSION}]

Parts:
C1, C2, C11, C12, C15, C18, C21, C23, C24: 1u; C_0805_2012Metric_Pad1.18x1.45mm_HandSolder
C3, C5, C6, C7, C8, C19, C20, C25, C26, C27, C28, C29, C30: 100n; C_0805_2012Metric_Pad1.18x1.45mm_HandSolder
C4, C16, C17: 10n; C_0805_2012Metric_Pad1.18x1.45mm_HandSolder
C9, C10, C13: 10u; C_0805_2012Metric_Pad1.18x1.45mm_HandSolder
C14: 22u; C_0805_2012Metric_Pad1.18x1.45mm_HandSolder
C22: 220n; C_0805_2012Metric_Pad1.18x1.45mm_HandSolder
D1: D_Schottky; D_SMA_Handsoldering
D2, D3: BAV99; SOT-23
H1, H2, H3: MountingHole; MountingHole_2.7mm_M2.5_Pad_Via
J1: Conn_01x06_Male; JST_PH_S6B-PH-SM4-TB_1x06-1MP_P2.00mm_Horizontal
J2: Conn_02x12_Counter_Clockwise; PinSocket_2x12_P2.54mm_Vertical
J3: Conn_01x05_Male; PinHeader_1x05_P2.54mm_Vertical
J4: Conn_02x12_Counter_Clockwise; PinHeader_2x12_P2.54mm_Vertical
J5: Conn_01x04_Pin; PinHeader_1x04_P2.54mm_Vertical
J6: Imon; PhoenixContact_MCV_1,5_2-G-3.81_1x02_P3.81mm_Vertical
J7: Umon; PhoenixContact_MCV_1,5_2-G-3.81_1x02_P3.81mm_Vertical
J8: Conn_02x05_Odd_Even; PinHeader_2x05_P2.54mm_Vertical
J9: -5PWR; JST_XH_B2B-XH-A_1x02_P2.50mm_Vertical
JP1: Test / Keys Int; PinHeader_1x02_P2.54mm_Vertical
JP2: Jumper_3_Bridged12; SolderJumper-3_P1.3mm_Bridged2Bar12_RoundedPad1.0x1.5mm
R1, R2, R3, R4: 1k; R_0805_2012Metric_Pad1.20x1.40mm_HandSolder
R5, R6: 2k2; R_0805_2012Metric_Pad1.20x1.40mm_HandSolder
R7: 2k; R_0805_2012Metric_Pad1.20x1.40mm_HandSolder
R8, R19, R20: 10k; R_0805_2012Metric_Pad1.20x1.40mm_HandSolder
R9, R17, R18: 47; R_0805_2012Metric_Pad1.20x1.40mm_HandSolder
R10: 220; R_0805_2012Metric_Pad1.20x1.40mm_HandSolder
R11, R12, R15, R16: 100k 0.1%; R_0805_2012Metric_Pad1.20x1.40mm_HandSolder
R13, R14: 10k 0.1%; R_0805_2012Metric_Pad1.20x1.40mm_HandSolder
SW1: Pico Reset; SW_Push_1P1T_NO_6x6mm_H9.5mm
U1, U2: DAC8555; TSSOP-16_4.4x5mm_P0.65mm
U3: TPS7A2030; SOT-23-5_HandSoldering
U4: AMS1117-3.3; SOT-223-3_TabPin2
U5: Pico; RPi_Pico_SMD_TH
U6: ADS131M02; TSSOP-20_4.4x6.5mm_P0.65mm
U7: MCP6004; SOIC-14_3.9x8.7mm_P1.27mm
U8: TL431DBZ; SOT-23
U9, U10: MCP6V51; SOT-23-5
U11: Pico Header; RPi_Pico_REVERSED_HEADER_SMD_TH
U12: MCP23008-xSO; SOIC-18W_7.5x11.6mm_P1.27mm
U13: 24LC64; SOIC-8_3.9x4.9mm_P1.27mm

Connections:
+3.0VA: C7.1, C8.1, C9.1, C10.1, C15.1, C18.1, C23.1, C25.1, C27.1, R7.2, U1.4 (AVDD), U2.4 (AVDD), U3.5 (OUT), U6.1 (AVDD), U7.4 (V+), U9.5 (V+), U10.5 (V+)
+3.3V: J2.12, J4.12, U5.35 (ADC_VREF), U11.35 (ADC_VREF)
+3.3VD: C5.1, C6.1, C14.1, C21.1, C29.1, C30.1, J1.1, JP2.3 (B), R19.2, R20.2, U1.12 (IOVDD), U1.13 (~RST), U2.12 (IOVDD), U2.13 (~RST), U4.2 (VO), U6.11 (~SYNC/RST), U6.20 (DVDD), U12.3 (A2), U12.4 (A1), U12.5 (A0), U12.6 (~RESET), U12.18 (VDD), U13.8 (VCC)
+5V: C11.1, C12.1, C13.1, D1.2 (A), J2.13, J4.13, U3.1 (IN), U3.3 (EN), U4.3 (VI)
-2V5: C23.2, C24.2, C26.2, C28.2, R10.2, U7.11 (V-), U8.3 (A), U9.2 (V-), U10.2 (V-)
/GPIO8: U5.11 (GPIO8), U11.11 (GPIO8)
/GPIO9: U5.12 (GPIO9), U11.12 (GPIO9)
/GPIO10: U5.14 (GPIO10), U11.14 (GPIO10)
/GPIO11: U5.15 (GPIO11), U11.15 (GPIO11)
/GPIO12: U5.16 (GPIO12), U11.16 (GPIO12)
/GPIO13: U5.17 (GPIO13), U11.17 (GPIO13)
/GPIO15: U5.20 (GPIO15), U11.20 (GPIO15)
/GPIO16: U5.21 (GPIO16), U11.21 (GPIO16)
/GPIO17: U5.22 (GPIO17), U11.22 (GPIO17)
/GPIO18: U5.24 (GPIO18), U11.24 (GPIO18)
/GPIO19: U5.25 (GPIO19), U11.25 (GPIO19)
/GPIO22: U5.29 (GPIO22), U11.29 (GPIO22)
/GPIO28: JP1.1 (A), U5.34 (GPIO28_ADC2), U11.34 (GPIO28_ADC2)
/HI_Clamp: R7.1, R8.2, U7.3 (+), U7.10 (+)
/PICO_3V3: U5.36 (3V3), U11.36 (3V3)
/PICO_3V3_EN: U5.37 (3V3_EN), U11.37 (3V3_EN)
/PICO_RUN: SW1.1, U5.30 (RUN), U11.30 (RUN)
/PICO_VBUS: U5.40 (VBUS), U11.40 (VBUS)
/PICO_VSYS: D1.1 (K), U5.39 (VSYS), U11.39 (VSYS)
/SWCLK: J3.5, U5.41 (SWCLK), U11.41 (SWCLK)
/SWDIO: J3.3, U5.43 (SWDIO), U11.43 (SWDIO)
ADC_CLK: R9.2, U5.27 (GPIO21), U11.27 (GPIO21)
ADC_CS: U5.26 (GPIO20), U6.12 (~CS), U11.26 (GPIO20)
ADC_RDY: R17.2, U5.10 (GPIO7), U11.10 (GPIO7)
DAC1_CS: U1.9 (~SYNC), U5.9 (GPIO6), U11.9 (GPIO6)
DAC2_CS: U2.9 (~SYNC), U5.7 (GPIO5), U11.7 (GPIO5)
GCOM: J2.3, J4.3, R2.1, R4.1
GND: C1.2, C2.2, C3.2, C4.2, C5.2, C6.2, C7.2, C8.2, C9.2, C10.2, C11.2, C12.2, C13.2, C14.2, C15.2, C18.2, C19.2, C20.2, C21.2, C22.2, C24.1, C25.2, C26.1, C27.2, C28.1, C29.2, C30.2, J1.2, J2.1, J2.2, J2.15, J3.4, J4.1, J4.2, J4.15, J5.1, J6.1, J7.1, J9.1, JP2.1 (A), R8.1, R15.2, R16.2, SW1.2, U1.5 (VREFL), U1.6 (GND), U1.14 (RSTSEL), U1.15 (~ENABLE), U1.16 (LDAC), U2.5 (VREFL), U2.6 (GND), U2.14 (RSTSEL), U2.15 (~ENABLE), U2.16 (LDAC), U3.2 (GND), U4.1 (GND), U5.3 (GND), U5.8 (GND), U5.13 (GND), U5.18 (GND), U5.23 (GND), U5.28 (GND), U5.33 (AGND), U5.38 (GND), U5.42 (GND), U6.2 (AGND), U6.19 (DGND), U7.5 (+), U7.12 (+), U8.1 (K), U8.2 (REF), U11.3 (GND), U11.8 (GND), U11.13 (GND), U11.18 (GND), U11.23 (GND), U11.28 (GND), U11.33 (AGND), U11.38 (GND), U11.42 (GND), U12.9 (VSS), U13.2 (A1), U13.3 (A2), U13.4 (GND), U13.7 (WP)
GP2: J5.2, U12.12 (GP2)
GP3: J5.3, U12.13 (GP3)
HW_INT: U5.19 (GPIO14), U11.19 (GPIO14), U12.8 (INT)
Imon: D3.3 (K), J2.24, J4.24, J6.2, R11.1, U7.9 (-), U7.13 (-)
Iset: J2.22, J4.22, J8.8
KEYS_INT: J1.5, JP1.2 (B)
unnamed: D2.2 (A), U7.1
unnamed: D2.1 (K), U7.7
unnamed: D3.2 (A), U7.8
unnamed: D3.1 (K), U7.14
unnamed: J8.1, U1.8 (VOUTD)
unnamed: J8.3, U1.7 (VOUTC)
unnamed: J8.5, U1.2 (VOUTB)
unnamed: J8.7, U1.1 (VOUTA)
unnamed: J8.9, U2.1 (VOUTA)
unnamed: J9.2, R10.1
unnamed: JP2.2 (C), U13.1 (A0)
unnamed: R11.2, R13.2
unnamed: R12.2, R14.2
unnamed: C16.2, R2.2, U6.4 (AIN0N)
unnamed: C16.1, R1.2, U6.3 (AIN0P)
unnamed: C17.2, R4.2, U6.5 (AIN1N)
unnamed: C17.1, R3.2, U6.6 (AIN1P)
unnamed: C22.1, U6.18 (CAP)
unnamed: R9.1, U6.17 (CLKIN)
unnamed: R18.1, U6.15 (DOUT)
unnamed: R17.1, U6.13 (~DRDY)
unnamed: R14.1, R16.1, U9.3 (+)
unnamed: R1.1, U9.1, U9.4 (-)
unnamed: R13.1, R15.1, U10.3 (+)
unnamed: R3.1, U10.1, U10.4 (-)
OCPset: J2.20, J4.20, J8.4
OCPtriggered: J2.7, J4.7, U12.16 (GP6)
OVPset: J2.19, J4.19, J8.6
OVPtriggered: J2.8, J4.8, U12.15 (GP5)
RX: J3.2, U5.2 (GPIO1), U11.2 (GPIO1)
SCL: C20.1, J1.4, J2.11, J4.11, R6.1, R19.1, U5.32 (GPIO27_ADC1), U11.32 (GPIO27_ADC1), U12.1 (SCL), U13.6 (SCL)
SDA: C19.1, J1.3, J2.10, J4.10, R5.1, R20.1, U5.31 (GPIO26_ADC0), U11.31 (GPIO26_ADC0), U12.2 (SDA), U13.5 (SDA)
SPI0_RX: R18.2, U5.6 (GPIO4), U11.6 (GPIO4)
SPI0_SCK: U1.10 (SCLK), U2.10 (SCLK), U5.4 (GPIO2), U6.14 (SCLK), U11.4 (GPIO2)
SPI0_TX: U1.11 (DIN), U2.11 (DIN), U5.5 (GPIO3), U6.16 (DIN), U11.5 (GPIO3)
TX: J3.1, U5.1 (GPIO0), U11.1 (GPIO0)
Temp1: J2.5, J4.5, R5.2
Temp2: J2.6, J4.6, R6.2
Umon: D2.3 (K), J2.23, J4.23, J7.2, R12.1, U7.2 (-), U7.6 (-)
Uset: J2.21, J4.21, J8.10
Vonset: J2.18, J4.18, J8.2
Vref: C1.1, C2.1, C3.1, C4.1, J2.4, J4.4, U1.3 (VREFH), U2.3 (VREFH)
clampOff3V3: J2.14, J4.14, U12.14 (GP4)
resetProt: J2.16, J4.16, U12.11 (GP1)
~VonLatch: J2.17, J4.17, U12.10 (GP0)
~Von: J2.9, J4.9, U12.17 (GP7)

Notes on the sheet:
0.0V
Digital power
Connector to encoder and buttons
Debug header
Analog power
0-2,5V
+2.5V
2-channel ADC
Analog Imon & Umon
Extra Connector to Analog board
1,2V
Connector to Analog board

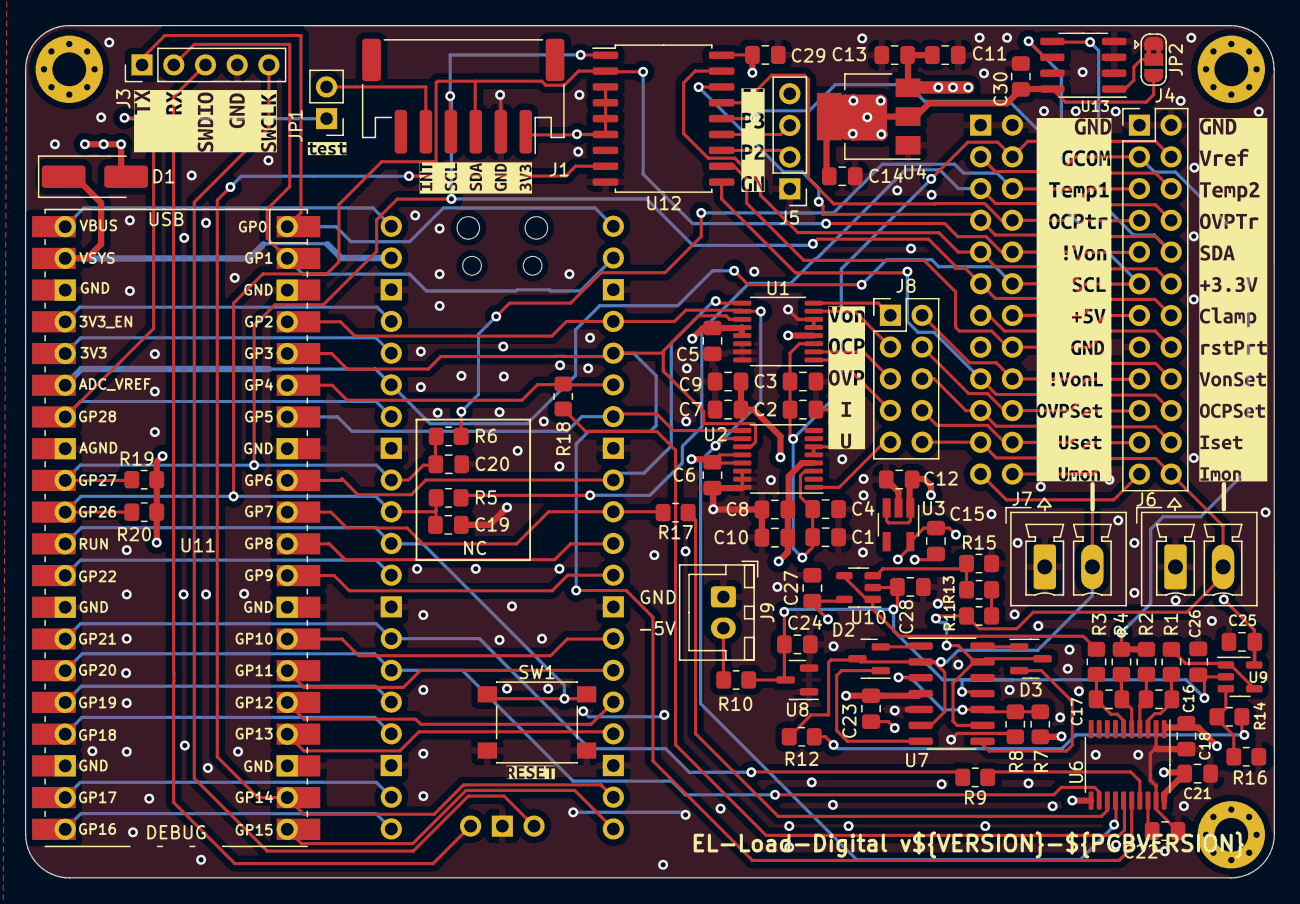
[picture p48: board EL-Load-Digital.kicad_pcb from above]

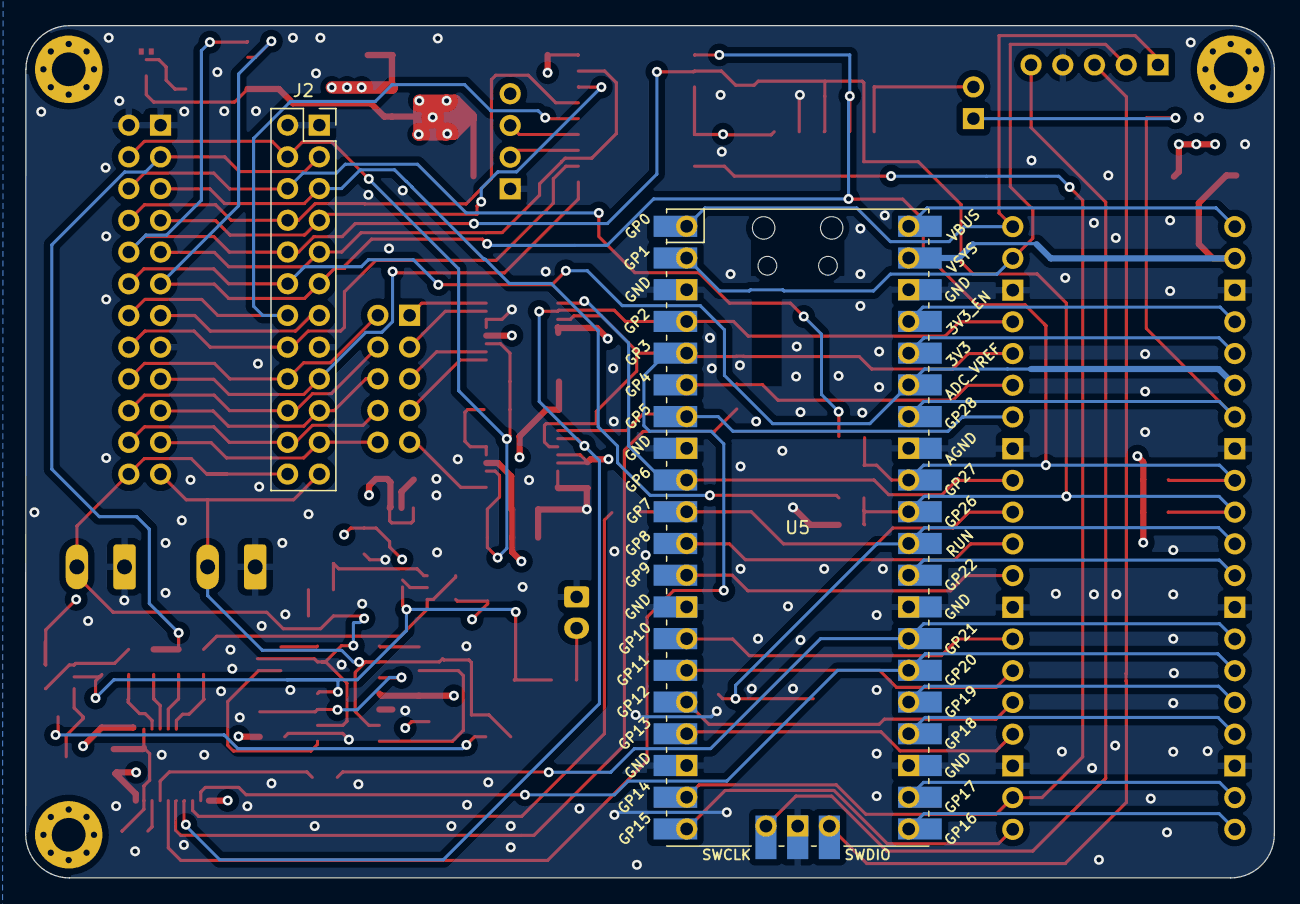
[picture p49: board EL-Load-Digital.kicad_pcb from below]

Board: 4 copper layers, 100.0 x 68.2 mm, 89 parts (2 on the bottom side), 85 nets.

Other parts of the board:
kibuzzard-63C41D86: G***; kibuzzard-63C41D86
kibuzzard-63C41DE1: G***; kibuzzard-63C41DE1
kibuzzard-64AAE6E2: G***; kibuzzard-64AAE6E2
kibuzzard-64AAEA42: G***; kibuzzard-64AAEA42
kibuzzard-64B1211E: G***; kibuzzard-64B1211E
kibuzzard-64B12145: G***; kibuzzard-64B12145
kibuzzard-635D1A4A: G***; kibuzzard-635D1A4A
kibuzzard-6429B73A: G***; kibuzzard-6429B73A

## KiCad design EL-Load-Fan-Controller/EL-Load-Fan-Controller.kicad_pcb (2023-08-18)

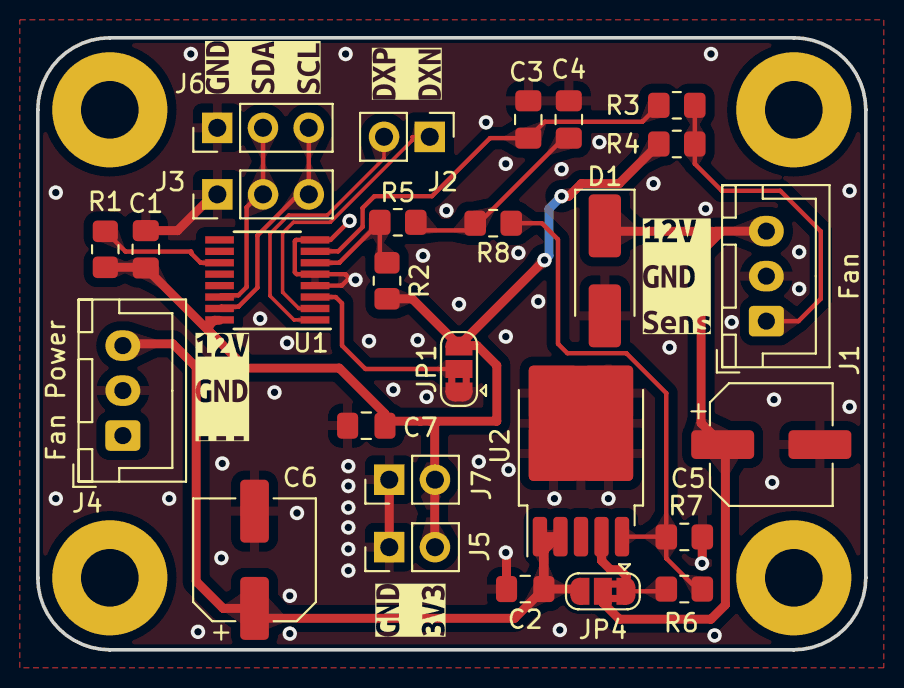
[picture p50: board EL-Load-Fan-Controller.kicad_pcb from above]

Board: 2 copper layers, 46.0 x 34.0 mm, 36 parts (0 on the bottom side), 16 nets.

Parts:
C1, C3: 100n; C_0805_2012Metric_Pad1.18x1.45mm_HandSolder
C2: 10n; C_0805_2012Metric_Pad1.18x1.45mm_HandSolder
C4, C7: 1u; C_0805_2012Metric_Pad1.18x1.45mm_HandSolder
C5, C6: 10u; CP_Elec_6.3x5.8
D1: SS14; D_SMA_Handsoldering
H1, H2, H3, H4: MountingHole; MountingHole_3.2mm_M3_Pad
J1: Fan; JST_XH_B3B-XH-A_1x03_P2.50mm_Vertical
J2: PN sensor; PinHeader_1x02_P2.54mm_Vertical
J3, J6: I2C; PinHeader_1x03_P2.54mm_Vertical
J4: Fan Power; JST_XH_B3B-XH-A_1x03_P2.50mm_Vertical
J5, J7: 3V3; PinHeader_1x02_P2.54mm_Vertical
JP1: I2C Address; SolderJumper-3_P1.3mm_Bridged2Bar12_RoundedPad1.0x1.5mm
JP4: SolderJumper_3_Bridged12; SolderJumper-3_P1.3mm_Bridged2Bar12_RoundedPad1.0x1.5mm
R1, R2: 4k7; R_0805_2012Metric_Pad1.20x1.40mm_HandSolder
R3: 10; R_0805_2012Metric_Pad1.20x1.40mm_HandSolder
R4, R5: 1k; R_0805_2012Metric_Pad1.20x1.40mm_HandSolder
R6: 39k; R_0805_2012Metric_Pad1.20x1.40mm_HandSolder
R7, R8: 3k3; R_0805_2012Metric_Pad1.20x1.40mm_HandSolder
U1: MAX31760; QSOP-16_3.9x4.9mm_P0.635mm
U2: BD00FC0WFP-E2; TO-252-5_TabPin6
kibuzzard-64B07B9D: G***; kibuzzard-64B07B9D
kibuzzard-64B073D4: G***; kibuzzard-64B073D4
kibuzzard-64B07534: G***; kibuzzard-64B07534
kibuzzard-64B10700: G***; kibuzzard-64B10700
kibuzzard-64B16975: G***; kibuzzard-64B16975

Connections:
+3.3V: C1.1, C7.1, J5.2, J7.2, JP1.3 (B), R1.2, R2.1, R4.1, U1.16 (VDD)
+12P: C2.1, C6.1, J4.3, JP4.3 (B), U2.1 (EN), U2.2 (Vcc)
/DXN: J2.1, U1.2 (DXN)
/DXP: J2.2, U1.1 (DXP)
/FanPWR: C5.1, D1.1 (K), J1.3, JP4.2 (C)
/Tacho: J1.1, R3.2, R4.2
GND: C1.2, C2.2, C3.2, C4.2, C5.2, C6.2, C7.2, D1.2 (A), J1.2, J3.1, J4.2, J5.1, J6.1, J7.1, JP1.1 (A), R7.2, U1.4 (A1), U1.5 (A2), U1.8 (GND), U2.6 (GND)
unnamed: C4.1, R5.2, R8.2
unnamed: JP1.2 (C), U1.3 (A0)
unnamed: JP4.1 (A), R6.1, U2.4 (VOUT)
unnamed: R2.2, R5.1, U1.6 (PWM)
unnamed: C3.1, R3.1, U1.7 (TACH1)
unnamed: R1.1, U1.11 (~SHDN)
unnamed: R6.2, R7.1, R8.1, U2.5 (FB)
SCL: J3.3, J6.3, U1.15 (SCL)
SDA: J3.2, J6.2, U1.14 (SDA)

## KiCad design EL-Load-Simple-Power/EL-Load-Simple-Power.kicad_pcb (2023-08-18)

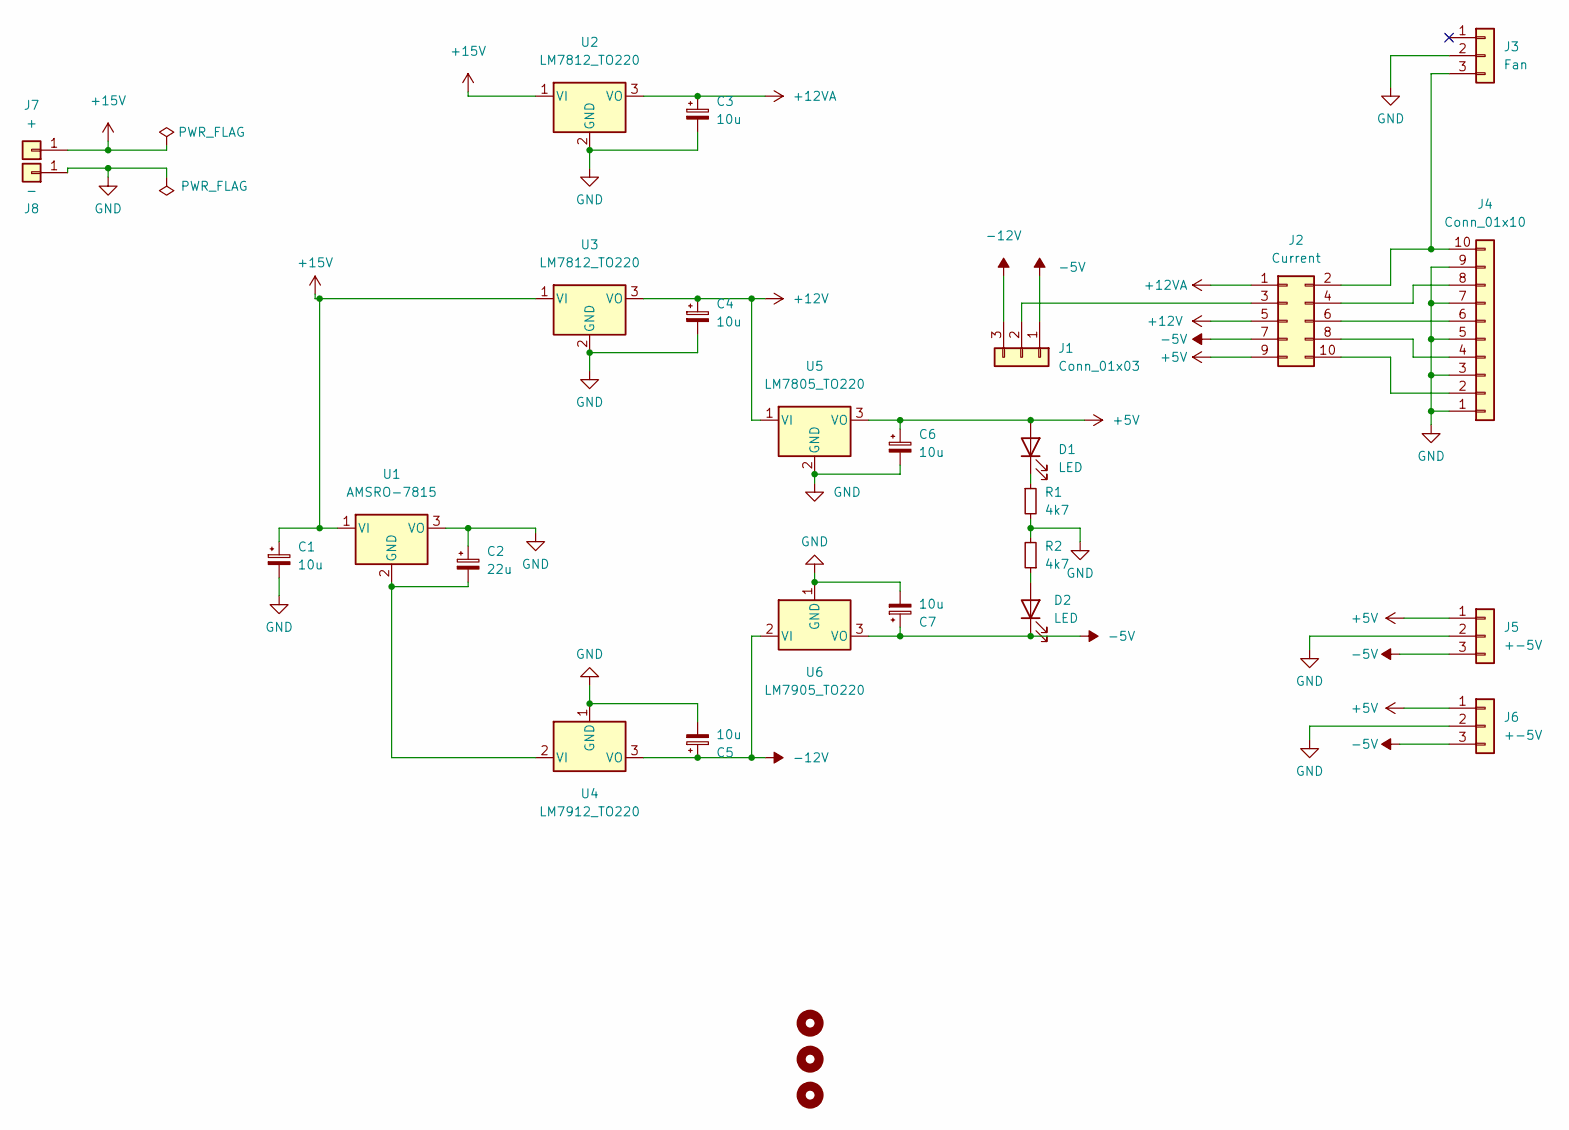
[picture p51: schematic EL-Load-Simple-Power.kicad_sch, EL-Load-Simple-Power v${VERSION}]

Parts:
C1, C3, C4, C5, C6, C7: 10u; CP_Radial_D5.0mm_P2.00mm
C2: 22u; CP_Radial_D5.0mm_P2.00mm
D1, D2: LED; LED_0805_2012Metric_Pad1.15x1.40mm_HandSolder
H1, H2, H3: MountingHole; MountingHole_3.2mm_M3_DIN965_Pad
J1: Conn_01x03; PinHeader_1x03_P2.54mm_Vertical
J2: Current; PinHeader_2x05_P2.54mm_Vertical
J3: Fan; JST_XH_B3B-XH-A_1x03_P2.50mm_Vertical
J4: Conn_01x10; PinSocket_1x10_P2.54mm_Horizontal
J5, J6: +-5V; JST_XH_B3B-XH-A_1x03_P2.50mm_Vertical
J7: +; MountingHole_4.3mm_M4_Pad_Via
J8: -; MountingHole_4.3mm_M4_Pad_Via
R1, R2: 4k7; R_0805_2012Metric_Pad1.20x1.40mm_HandSolder
U1: AMSRO-7815; PinHeader_1x03_P2.54mm_Vertical
U2, U3: LM7812_TO220; TO-220-3_Vertical
U4: LM7912_TO220; TO-220-3_Vertical
U5: LM7805_TO220; TO-220-3_Vertical
U6: LM7905_TO220; TO-220-3_Vertical

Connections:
+5V: C6.1, D1.2 (A), J2.9, J5.1, J6.1, U5.3 (VO)
+12V: C4.1, J2.5, U3.3 (VO), U5.1 (VI)
+12VA: C3.1, J2.1, U2.3 (VO)
+15V: C1.1, J7.1, U1.1 (VI), U2.1 (VI), U3.1 (VI)
-5V: C7.1, D2.1 (K), J1.1, J2.7, J5.3, J6.3, U6.3 (VO)
-12V: C5.1, J1.3, U4.3 (VO), U6.2 (VI)
GND: C1.2, C2.1, C3.2, C4.2, C5.2, C6.2, C7.2, J3.2, J4.1, J4.3, J4.5, J4.7, J4.9, J5.2, J6.2, J8.1, R1.2, R2.2, U1.3 (VO), U2.2 (GND), U3.2 (GND), U4.1 (GND), U5.2 (GND), U6.1 (GND)
unnamed: D1.1 (K), R1.1
unnamed: D2.2 (A), R2.1
unnamed: J1.2, J2.3
unnamed: J2.2, J3.3, J4.10
unnamed: J2.4, J4.8
unnamed: J2.6, J4.6
unnamed: J2.8, J4.4
unnamed: J2.10, J4.2
unnamed: C2.2, U1.2 (GND), U4.2 (VI)

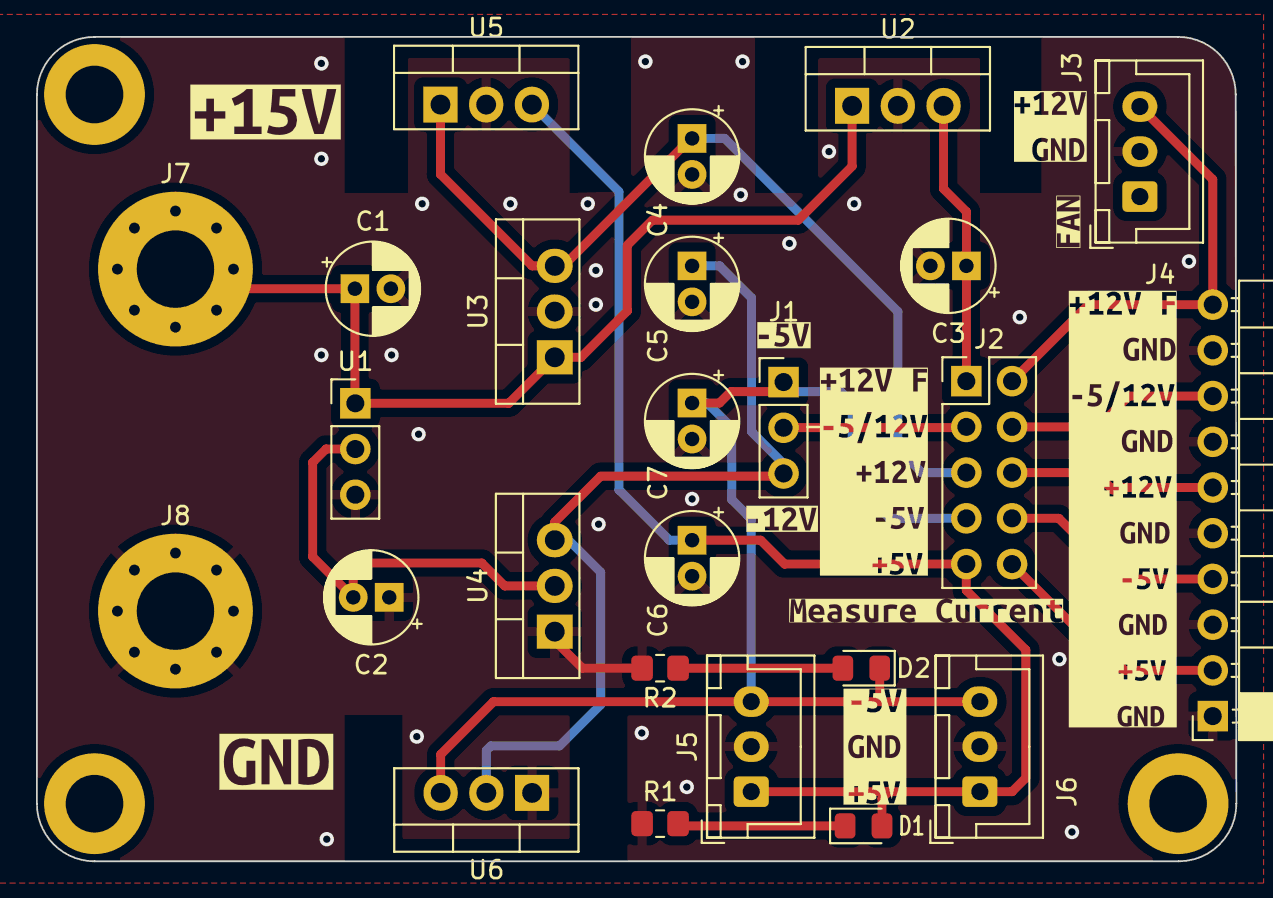
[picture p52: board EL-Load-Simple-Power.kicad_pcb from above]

Board: 2 copper layers, 66.6 x 45.8 mm, 38 parts (0 on the bottom side), 16 nets.

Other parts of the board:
kibuzzard-637A8A74: G***; kibuzzard-637A8A74
kibuzzard-637A8B4C: G***; kibuzzard-637A8B4C
kibuzzard-637A8BAE: G***; kibuzzard-637A8BAE
kibuzzard-637A8BC6: G***; kibuzzard-637A8BC6
kibuzzard-637A8C48: G***; kibuzzard-637A8C48
kibuzzard-637A8C53: G***; kibuzzard-637A8C53
kibuzzard-636532B8: G***; kibuzzard-636532B8
kibuzzard-6365324F: G***; kibuzzard-6365324F
kibuzzard-63653018: G***; kibuzzard-63653018
kibuzzard-63653277: G***; kibuzzard-63653277

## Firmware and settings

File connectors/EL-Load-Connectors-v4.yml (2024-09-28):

connectors:
    MCU-J8:
        type: PinHeader 2x08 P2.54mm
        pins: [1, 2, 3, 4, 5, 6, 7, 8, 9, 10, 11, 12, 13, 14, 15, 16, ]
        pinlabels: [GND, GND, MCU/VoltSenseClear, +7VU, MCU/HWProtEnable, +7VU, MCU/VoltSenseSet, _reversePolarity, MCU/senseError, +15VU, MCU/voltRangeLow, -7VU, MCU/~VonLatch, -7VU, GND, GND, ]

    MCU-J7:
        type: PinHeader 2x08 P2.54mm
        pins: [1, 2, 3, 4, 5, 6, 7, 8, 9, 10, 11, 12, 13, 14, 15, 16, ]
        pinlabels: [MCU/resetProt, MCU/OCPtriggered, MCU/clampOff, MCU/OVPtriggered, MCU/EL-ADC_RDY, MCU/EL-ADC_CS, MCU/EL-SPI_TX, MCU/EL-SPI_SCK, MCU/EL-ADC_CLK, MCU/EL-SPI_RX, GND, MCU/EL-DAC1_CS, +3V3, MCU/currRangeLow, MCU/EL-DAC2_CS, MCU/~Von, ]

    MCU-J11:
        type: IDC-Header 2x08 P2.54mm
        pins: [1, 2, 3, 4, 5, 6, 7, 8, 9, 10, 11, 12, 13, 14, 15, 16, ]
        pinlabels: [GND, +3V3, SCLK, MOSI, RESET, DC, BLK, MISO, CS1, CS2, PEN, _KEYS_SDA, _KEYS_SCL, INT, ~RESET, GND, ]

    Panel-J2:
        type: Conn_02x08_Odd_Even
        pins: [1, 2, 3, 4, 5, 6, 7, 8, 9, 10, 11, 12, 13, 14, 15, 16, ]
        pinlabels: [GND, +3V3, SCLK, MOSI, RESET, DC, BLK, MISO, CS1, CS2, PEN, SDA, SCL, INT, ~RESET, GND, ]

    Analog-J8:
        type: Conn_02x08_Odd_Even
        pins: [1, 2, 3, 4, 5, 6, 7, 8, 9, 10, 11, 12, 13, 14, 15, 16, ]
        pinlabels: [resetProt, OCPtriggered, ClampOff, OVPtriggered, ADC_RDY, ADC_CS, SPI0_TX, SPI0_SCK, ADC_CLK, SPI0_RX, GND, DAC1_CS, +3.3VD, CurrRangeLow, DAC2_CS, ~Von, ]
    Analog-J4:
        type: Conn_02x08_Odd_Even
        pins: [1, 2, 3, 4, 5, 6, 7, 8, 9, 10, 11, 12, 13, 14, 15, 16, ]
        pinlabels: [GND, GND, VsenseClear, +6V, HWProtEnable, +6V, VsenseSet, ReversePolarity, SenseError, +15V, VoltRangeLow, -6V, ~VonLatch, -6V, GND, GND, ]

cables:
  W1:
    gauge: 28 AWG
    length: 0.045
    color_code: DIN
    wirecount: 16
    shield: false

  W2:
    gauge: 28 AWG
    length: 0.05
    color_code: DIN
    wirecount: 16
    shield: false

connections:
  -
    - MCU-J8: [1,2,3,4,5,6,7,8,9,10,11,12,13,14,15,16,]
    - W1: [1,2,3,4,5,6,7,8,9,10,11,12,13,14,15,16,]
    - Analog-J4: [1,2,3,4,5,6,7,8,9,10,11,12,13,14,15,16,]
  -
    - MCU-J7: [1,2,3,4,5,6,7,8,9,10,11,12,13,14,15,16,]
    - [ -,-,-,-,-,-,-,-,-,-,-,-,-,-,-,-, ]
    - Analog-J8: [1,2,3,4,5,6,7,8,9,10,11,12,13,14,15,16,]
 
  - 
    - MCU-J11: [1,2,3,4,5,6,7,8,9,10,11,12,13,14,15,16,]
    - W2: [1,2,3,4,5,6,7,8,9,10,11,12,13,14,15,16,]
    - Panel-J2: [1,2,3,4,5,6,7,8,9,10,11,12,13,14,15,16,]

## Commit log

2023-08-18 Put REF2025 in place, added LICENSES and .gitignore
    [EL-Load-Analog.kicad_pcb, EL-Load-Analog.kicad_sch, shifts-refs.kicad_sch]
2023-12-24 Added 3D models, mainly PCB stands
    [PCB-ADS1115-module.FCStd, PCB-ADS1115-module.stl, PCB-EL-Load-Analog-Fan30Stand1.FCStd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]
2023-12-24 Digital PCB update
    [EL-Load-Digital.kicad_pcb, EL-Load-Digital.kicad_sch]
2023-12-24 Major Analog PCB update DAC/ADC + connectors included, fan IC removed
    [DIB.kicad_sch, EL-Load-Analog.kicad_pcb, EL-Load-Analog.kicad_sch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]
2023-12-26 Added Power-MCU board
    [EL-Load-Power-MCU.kicad_pcb, EL-Load-Power-MCU.kicad_sch, FanControllers.kicad_sch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]
2023-12-26 Added EL-Load-Panel PCB
    [EC11_Rotary_Encoder_Switched.step, EL-Load-Panel.kicad_pcb, EL-Load-Panel.kicad_sch]
2023-12-26 Added standalone case 3D model
2023-12-26 small update
    [EL-Load-Analog.kicad_pcb]
2023-12-26 Added Power-MCU schema PDF
2023-12-30 Added snubber on input, bananajacks, sense connector, some cleanup.
    [DIB.kicad_sch, EE2-3TNUH-L.step, EL-Load-Analog.kicad_pcb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]
2023-12-30 added missing files
    [SWEB 8094 AU GN.step, SWEB 8094 AU OR.step, SWEB 8094 AU RT.step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]
2023-12-30 Moved old PCBs to Obsolete directory
    [EL-Load-Digital.kicad_pcb, EL-Load-Digital.kicad_sch, EL-Load-Fan-Controller.kicad_pcb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]
2024-01-05 Fixed Panel 1r1 and Power-MCU 2r2 versions
    [EL-Load-Panel.kicad_pcb, EL-Load-Panel.kicad_sch, EL-Load-Power-MCU.kicad_pcb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]
2024-01-05 BOM fixes/updates.
    [EL-Load-Power-MCU.kicad_sch, FanControllers.kicad_sch]
2024-01-26 Updated EL-Load-Panel to 1r2, fixing issues in issue #3.
    [EL-Load-Panel.kicad_pcb, EL-Load-Panel.kicad_sch]
2024-02-04 Added license text to panel, updated gitignore
    [EL-Load-Panel.kicad_pcb, EL-Load-Panel.kicad_sch]
2024-02-04 Fixes to Power-MCU board.
    [EL-Load-Power-MCU.kicad_pcb, EL-Load-Power-MCU.kicad_sch, FanControllers.kicad_sch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]
2024-02-04 Added SenseError detection (including ocmponents), added clearances, fixed few BOM items.
    [DIB.kicad_sch, EL-Load-Analog.kicad_pcb, EL-Load-Analog.kicad_sch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]
2024-02-06 Final v3 PCB version C.
    [DIB.kicad_sch, EL-Load-Analog.kicad_pcb, EL-Load-Analog.kicad_sch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]
2024-03-10 Final v3C version for Analog PCB.
    [EL-Load-Analog.kicad_pcb]
2024-03-20 Did #7, #10 and few items from #2
    [EL-Load-Power-MCU.kicad_pcb, EL-Load-Power-MCU.kicad_sch, standalone power.kicad_sch]
2024-03-20 Added +15VU led, fixed JP1
    [EL-Load-Power-MCU.kicad_pcb, EL-Load-Power-MCU.kicad_sch, FanControllers.kicad_sch]
2024-03-21 Working on #4,#2 fixed #8,#22
    [EL-Load-Analog.kicad_pcb, EL-Load-Power-MCU.kicad_pcb, EL-Load-Power-MCU.kicad_sch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]
2024-03-24 Fixing issues from #4, adding ESD protection (#6)
    [EL-Load-Analog.kicad_pcb, Monitoring.kicad_sch, cv-von.kicad_sch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]
2024-03-30 Added heatsink moutingholes, reverse polarity, moved snubbers.
    [DIB.kicad_sch, EL-Load-Analog.kicad_pcb, EL-Load-Analog.kicad_sch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]
2024-04-21 Added Reverse Polarity Test PCB design
    [EL-Load-Reverse-Polarity.csv, EL-Load-Reverse-Polarity.kicad_pcb, EL-Load-Reverse-Polarity.kicad_sch]
2024-06-21 New reverse polarity test schema & PCB.
    [EL-Load-Reverse-Polarity.csv, EL-Load-Reverse-Polarity.kicad_pcb, EL-Load-Reverse-Polarity.kicad_sch]
2024-08-25 Added extra capacitor to Panel for stability. Upped schematic and pcb revisions to v2r3.
    [EL-Load-Panel.kicad_pcb, EL-Load-Panel.kicad_sch]
2024-09-28 Added inter board connector definitions (for V4)
2024-10-06 EL-Load-Power-MCU PCB v4r4 release.
    [EL-Load-Power-MCU.kicad_pcb, EL-Load-Power-MCU.kicad_sch, EL-Load-Power-MCU_bom_4r4.csv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]
2024-10-27 Connectors for v3 and v4 make explicit
2024-10-30 Fixed fan driver with jumper. Initial v5 version (still KiCad7)
    [EL-Load-Power-MCU.kicad_pcb, FanControllers.kicad_sch]
2024-11-03 Standalone case for V4
    [BevelHinge-Bevel.stl, BevelHinge-BevelMirror.stl, BevelHinge-Hinge.stl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]
2024-11-10 v4 Analog board design. Features reverse polarity, remote sense error and new clamping circuitry.
    [DIB.kicad_sch, EL-Load-Analog.kicad_pcb, EL-Load-Analog.kicad_sch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]
2025-01-03 Schema changed to 4.1, PCB version E. Modified R44, Remote sense error circtuit had wrong min input.
    [EL-Load-Analog.kicad_pcb, EL-Load-Analog.kicad_sch, Monitoring.kicad_sch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]
2025-01-12 Changed comparator to LM393A.
    [EL-Load-Analog.kicad_pcb, Monitoring.kicad_sch, cv-von.kicad_sch]
2025-02-22 3D model and bom update
    [BevelHinge.FCStd]
2025-02-22 Initial Panel v3 commit
    [EL-Load-Panel.kicad_pcb, EL-Load-Panel.kicad_sch]
2025-07-27 standalone model cleanups and stl exports
    [EL-Load-CaseV4-EndPanel.stl, EL-Load-CaseV4-PCBFrame1.stl, EL-Load-CaseV4-USB clip.stl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]

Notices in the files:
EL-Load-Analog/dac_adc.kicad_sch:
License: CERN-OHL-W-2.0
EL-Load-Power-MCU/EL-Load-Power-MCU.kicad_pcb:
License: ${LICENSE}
